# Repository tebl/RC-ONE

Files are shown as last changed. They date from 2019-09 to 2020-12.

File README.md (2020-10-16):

# KIM-1 Replica Computer
Along the years I've built quite a few computers, some bought as kits from various vendors and some I've even designed myself based on designs described in good old books or other technical resources - above all, there's always been one I really wanted above all of them: the KIM-1! 

Originally created by MOS in order to show off their new 6502-processor, it was a success that tapped into a market they probably never knew themselves was growing into a force to be reckoned with - the homecomputing market! Later bought up by little-known typewriter-manufacturer *Commodore*, the KIM-1 is an iconic piece of hardware and since I can't afford to buy one I'll build one instead.

The original unit cost 245$ assembled with everything you needed to get started, it had six segment displays for outputting information and a 24-key keypad onboard. CPU ran at an incredible 1 Mhz, it had a complete monitor in 2K of ROM, 1K of static RAM as well as an additional 128 bytes of RAM. You got 15 additional I/O lines to play with, all on a single PCB.

# RC-ONE
I however don't have that amount of money to play with, PCB prices skyrocket past 100x100 mm so I've separated functionality into separate boards so that each version would cost only around 5$ per piece instead. It means it's no longer a single board computer, but if it means more people can build it as a fun project then that's a plus in my book. The main setup does not include the additional 15 I/O lines due to space requirements, but you can add those back to the system by including the 65K Expansion (in addition to the backplane module) if you want to. If you just want to play around with the system and try your hand at machine language coding, you can get started with the CPU board, UI board and a keypad module.

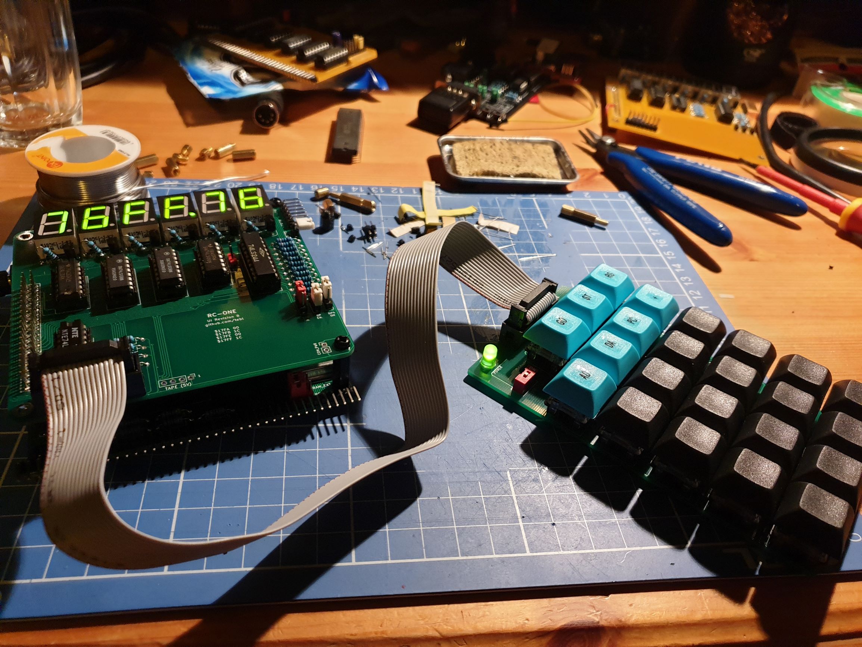
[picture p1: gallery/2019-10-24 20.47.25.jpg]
RC-ONE Standalone


As a classic microcomputer, I've gone ahead and created the obligatory memory map for your perusal - the highlights are shown below, but you'll find the complete set of information in the documentation section ([ODS](https://github.com/tebl/RC-ONE/raw/master/documentation/memory_map.ods)- or [PDF](https://github.com/tebl/RC-ONE/raw/master/documentation/memory_map.pdf)-format). Some of the functions have been shifted physically, but in the end the system should be functionally identical to an original system and able to run code without requireing changes.

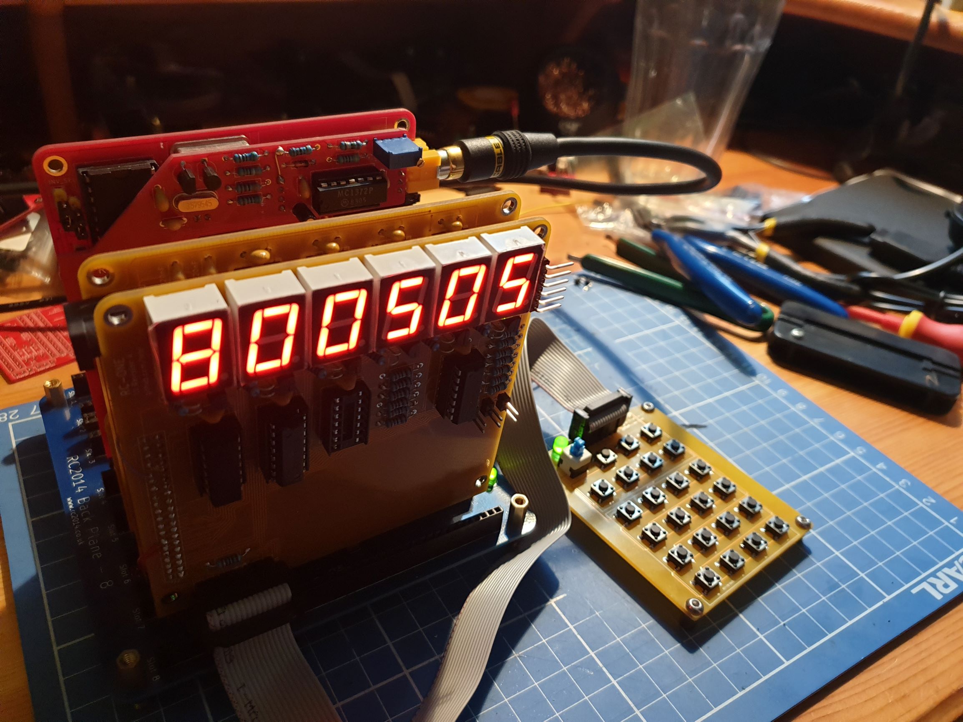
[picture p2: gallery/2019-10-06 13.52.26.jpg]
Expanded system


The system is highly expandable, with the [65K Expansion board](https://github.com/tebl/RC-ONE/tree/master/RC1%2065K%20Expansion) in place you'll get better utilization of the components already on the CPU board as well as the ability to add additional modules to the system with an additional backplane also in place. See *System modules* below for a list of modules required for a complete system, optional modules available as well as modules for other systems that are compatible with the RC-ONE computer.

A lot of the work I've done couldn't have been completed without the work previously done by Ruud Baltissen, you can compare the schematics he did for the original KIM-1 computer and his more modern recreation of it by studying his [Build your own KIM-1](http://www.baltissen.org/newhtm/buildkim.htm) page.

## Project status
The RC-ONE computer is operational, it can be used to enter and run code via the keypad and can output to the displays as expected and for many this will be all that's needed to have fun with it as a replica of the KIM-1. Some sections are still being worked on, mainly those that deal with the TTY mode and tape functionality - see [TODO](https://github.com/tebl/RC-ONE/blob/master/TODO.md) for an overview of things I'd like to see done sometime in the future!

## System modules
As mentioned earlier there are a few different modules available for the system, some will be required to make the system function and others is considered optional and can be added if you want that extra piece of 70s-technology to play around with. There may be additional modules in the project files, but the ones I've added here are the ones that can be considered ready. As modules are being worked on over time, I've also added an order link to the modules so that you can get the last version I know worked. For more information about the specific module, including schematic and a list of parts you'd need to build it - click the name of the module!

Note that due to the similarities with the [RC6502  Apple 1 Replica](https://github.com/tebl/RC6502-Apple-1-Replica), quite a few of the modules developed for that system will also work with the RC-ONE - the ones I've tested and use with the system have also been linked below.

| Module | RC-ONE | RC-ONE 65K | Order |
| --- | --- | --- | ----- |
| [RC-ONE CPU](https://github.com/tebl/RC-ONE/tree/master/RC1%20CPU) | required | required | [PCBWay](https://www.pcbway.com/project/shareproject/RC_ONE_KIM_1_Replica__CPU_module_.html) |
| [RC-ONE User Interface](https://github.com/tebl/RC-ONE/tree/master/RC1%20UI) | required | required | [PCBWay](https://www.pcbway.com/project/shareproject/RC_ONE_KIM_1_Replica__UI_revision_C_.html) |
| [RC-ONE Keypad SX](https://github.com/tebl/RC-ONE/tree/master/RC1%20Keypad) | required * | required * | [PCBWay](https://www.pcbway.com/project/shareproject/RC_ONE_Keypad_SX.html?inviteid=88707) |
| [RC-ONE Keypad MX](https://github.com/tebl/RC-ONE/tree/master/RC1%20Keypad%20MX) | required * | required * | [PCBWay](https://www.pcbway.com/project/shareproject/RC_ONE_Keypad_MX.html) |
| [RC-ONE 65K Expansion](https://github.com/tebl/RC-ONE/tree/master/RC1%2065K%20Expansion) |  | required | [PCBWay](https://www.pcbway.com/project/shareproject/RC_ONE_65K_Expansion.html) |
| [RC-ONE 8K ExRAM](https://github.com/tebl/RC-ONE/tree/master/RC1%208K%20ExRAM) |  | optional | |
| [RC6502 Backplane](https://github.com/tebl/RC6502-Apple-1-Replica/tree/master/RC6502%20Backplane)  |  | required | [PCBWay](https://www.pcbway.com/project/shareproject/RC6502_Apple_1_Replica__Backplane_module_revision_A_.html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) |
| [RC6502 Prototyping module](https://github.com/tebl/RC6502-Apple-1-Replica/tree/master/RC6502%20Prototyping) |  | optional | [PCBWay](https://www.pcbway.com/project/shareproject/RC6502_Apple_1_Replica__Module_prototyping_board_.html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) |
| [6502 Project Platform](https://github.com/tebl/RC-Project-Board) | optional | optional | [PCBWay](https://www.pcbway.com/project/shareproject/6502_Project_Platform__RC6502__RC_ONE__RC6802_.html?inviteid=88707) |
| [6502 Games Board](https://github.com/tebl/RC-Project-Board/tree/master/projects/GB-001%20Game%20Board) | | optional** | [PCBWay](https://www.pcbway.com/project/shareproject/6502_Games_Board.html)
| [6502 Games Platform](https://github.com/tebl/RC-Project-Board/tree/master/platforms/PP%206502%20Game%20Board) | | optional** | [PCBWay](https://www.pcbway.com/project/shareproject/6502_Games_Platform.html)

*) Only one Keypad module is required, the MX version is a lot more comfortable to use though it comes at an increased cost.
**) You need [6502 Games Platform](https://github.com/tebl/RC-Project-Board/tree/master/platforms/PP%206502%20Game%20Board) and 6502 Game Board to build the 6502 Games hardware, originally created by Rodnay Zaks in his book [6502 Games](https://archive.org/details/6502GamesRodnayZaks/mode/2up). To use them with the RC-ONE you also require the [65K Expansion](https://github.com/tebl/RC-ONE/tree/master/RC1%2065K%20Expansion) installed.

If you would like to have a copy of one or more modules (usually 5$ per module), consider using the order links listed above - that way you also support the development of these boards while doing so. Alternatively, you can also zip up the contents of the export directory for each module and give that to your favourite PCB fabrication plant (I use [PCBWay](https://www.pcbway.com/setinvite.aspx?inviteid=88707) instead. Note that since I'm always tinkering with things, this repository may contain changes that I've not yet tested!

## Tell me more!
You'll find a lot of additional technical information belonging to each of the various modules by clicking on them from the table in the previous section, but those are mainly for reference when using or building them. For that reason I've also taken the time to write a somewhat acceptable attempt at a [manual](https://github.com/tebl/RC-ONE/blob/master/Manual.md), it should be able to get you started at both understanding not only how to use the computer, but also give you a more concise idea about what a KIM-1 computer (or replica) actually is.

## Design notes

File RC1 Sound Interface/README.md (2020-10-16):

# RC-ONE Sound Interface (SID)

**This design is untested!**

Made in order to use Commodore 64 SID chip replacements such as the SwinSID, armSID or fpgaSID as a sound device. Purposefully does not include the extra voltages needed to use a real SID-chip, mostly because the functioning chips that are left in this world belong in real computers (also, did not want to mess around with more than one power rail).

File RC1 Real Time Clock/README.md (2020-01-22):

# RC-ONE Real Time Clock (RTC)

**This design is untested!**

Wanted a Real Time Clock, but have been a hard time locating a suitable circuit for it since most of them either contain batteries that ran out a decade ago or are based on I2C or SPI (which I don't feel like bit-banging now or possibly ever). Appearantly there is a chip called DS12885 that is suitable and was readily used on the XT and AT line of computers, so they are cheap and plentiful though have a multi-plexed bus that is probably why it haven't been much used for SBC builds. Did however find an article in [Elektor Electronics from april 1985](https://www.americanradiohistory.com/UK/Elektor/80s/Elektor-1985-04.pdf) that uses it, so I've tried my best to adapt it for use here.

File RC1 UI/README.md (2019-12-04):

# RC-ONE

Among the years I've built quite a few computers, some bought as kits from various vendors and some I even designed myself based on available designs describes in books and other technical resources - above all, there was one I really wanted above all of them; the KIM-1! The [RC-ONE](https://github.com/tebl/RC-ONE) is a functional replica designed in a modular fashion, for the specifics see the specific module.

## User Interface (UI)
The *User Interface (UI)* board has been created to stack on top of the CPU-board, see below for an indication of how that'll look on a completed revision B system - I'm using M3 nylon standoffs to support the boards.

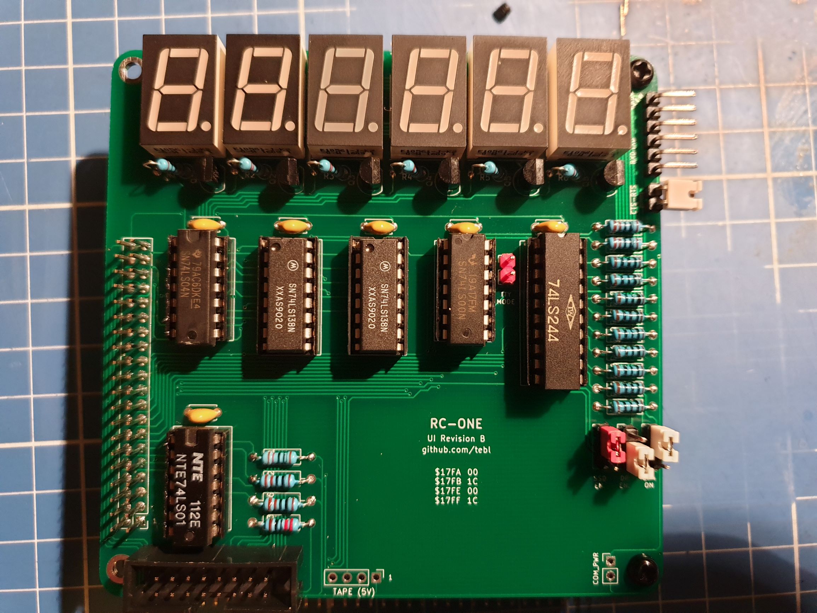
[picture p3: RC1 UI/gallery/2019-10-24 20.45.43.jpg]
Assembled UI Board

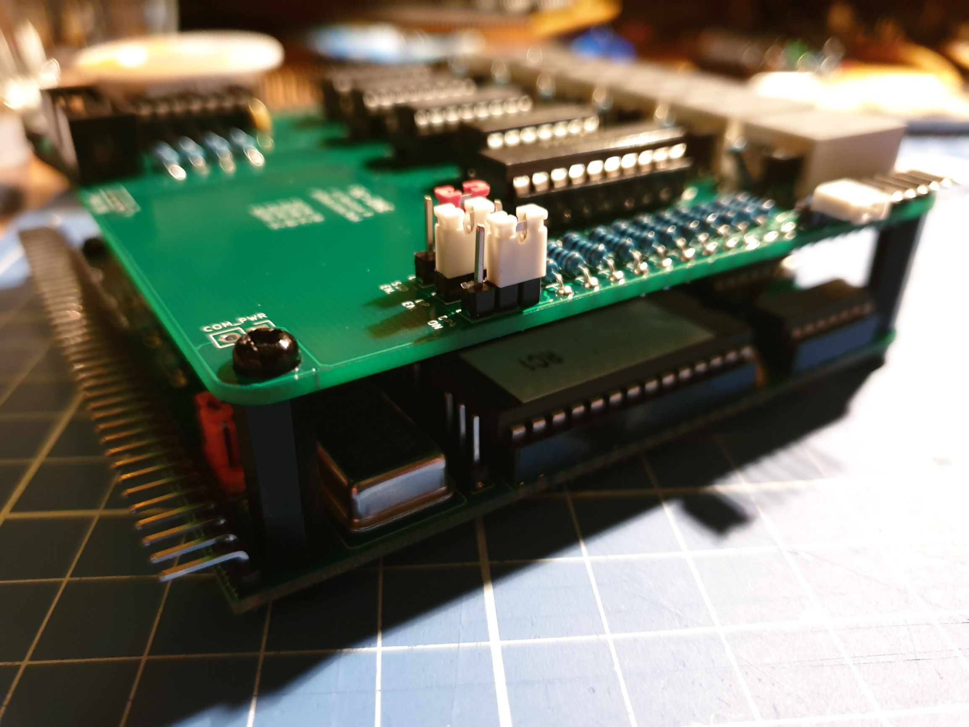
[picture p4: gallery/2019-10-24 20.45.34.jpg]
Stacked boards


The UI board takes care of all the various ways that the user can interact with the computer, it should functionally include all the functions found on the original computer such as 7-segment displays, keypad connector, a simplified tape interface as well as the ability to connect with a serial terminal.

The displays function the same way as the original displays, but the output hardwareas well as the logic dealing with device selection has been changed to replace some of the ICs that I could not reliably obtain - unfortunately at an increased chip-count, but that is the cost of doing increasingly outdated projects. The 6532 compared to the original 6530 IC has an extra I/O line, I've connected that up to the decimal point of the displays though the bahaviour of these is not supported by the original monitor program so I've added jumpers to enable/disable this functionality.

The tape interface was one created by Daniel Metzger and was featured in the book *22 micro-computer projects - to build, learn and learn*, I don't have an original KIM-1 so I can't compare the two though it is the only one I've seen that only use 5v (3.5mm jack has both audio in and out, I designed it for use with a ZX Spectrum +3 tape cables that people are still selling). 

The serial interface is now TTL level and is intended for use with USB TTL serial adapters, *USE_COM* must be jumpered when resetting the computer so that the computer knows to attempt communication over serial instead of using the displays/keypad. After starting up, the computer will await the receipt of the *ENTER* key in order to determine the baud rate that should be used when communicating with the terminal (-program).

## Jumpers
| Reference | Position | Description |
| ---| --- | ---  |
| DP_EN | 1-2 | Decimal point (DP) on displays connected to 6532 PB6 line |
| | 2-3 * | DP on displays disabled as original |
| DP4_EN | 1-2 * | DP on display 4 always on |
| | 2-3 | DP on display 4 connected to 6532 PB6 line |
| SSD_EN | 1-2 * | Enable Seven Segment Displays (SSD) |
| | 2-3 | Disable Seven Segment Displays (SSD) |
| TTY_MODE  | o-o | Jumper to enable TTY-mode, disabled keypad/displays |
| CTS - RTS | o-o * | Shorts serial CTS to RTS to disable flow control |
| COM_PWR | o-o | Jumpering allows the computer to be powered over the serial connection *INSTEAD* of connecting power to the CPU board |

\*) Marks the default jumpered positions for a standalone RC-ONE system.

# Schematic
The supplied KiCad files should be sufficient as both a schematic and as a starting point for ordering PCBs (basically you could just zip the contents of the export folder and upload that on a fabrication site), the schematic is also available in [PDF-format](https://github.com/tebl/RC-ONE/raw/master/RC1%20UI/export/RC1%20UI.pdf) so that you print it out and hang it on your office wall, excellent conversation starter at any technology-oriented business worth working at (or so I keep telling myself)!

If you require more assistance, there is also a separate [Troubleshooting](https://github.com/tebl/RC-ONE/blob/master/Troubleshooting.md) guide as part of the supplied documentation. Also make sure to have a read through the [Manual](https://github.com/tebl/RC-ONE/blob/master/Manual.md) to see if it's a *feature* instead!

# BOM
This is the part list as it stands now, most should be easy to get a hold of from your local electronic component shop though you might have to consider other sources depending on the quality of your local vendor. Values in parenthesis are optional components that might not be needed depending on what you want, here it's mostly the tape interface.

Some vendors will have the same ICs in different form factors, the ones you want will often be specified as being in the form of a DIP/PDIP package. For the pin headers, you probably won't find the exact pin count so just buy the 40 pin versions and snip off the parts you don't need.

| Reference | Item | Count |
| --- | --- | ----- |
| PCB | Fabricate yourself using Gerber files | 1 |
| AFF1-AFF6 | 0.56" 7-segment displays (C.K.) | 6 |
| C7,C9 | 50nF ceramic capacitor | (2)|
| C8 | 68nF ceramic capacitor | (1)|
| C1-C6 | 100nF ceramic capacitor | 6 |
| C11 | 100nF ceramic capacitor | (1)|
| D4 | 5mm LED | (1)|
| D1-D3 | 1N4148 small signal diode | 3 |
| D5-D7 | 1N4148 small signal diode | (3)|
| J1 | 2x8 straight pin header | 1 |
| J2 | 2x20 straight pin header | 1 |
| J3 | 1x6 right-angle pin header | 1 |
| J4 Audio | 3.5mm 5pin green audio socket (PJ307) | (1)|
| JP1,JP3 | 1x2 straight pin header | 2 |
| JP4-JP6 | 1x3 straight pin header | 3 |
| JP2 | 1x2 right-angle pin header | 1 |
| Q1-Q6 | 2N3904 TO-92 transistor | 6 |
| Q7-Q9 | 2N3904 TO-92 transistor | (3)|
| R7,R8,R14-R20 | 100 ohm resistor | 9 |
| R10 | 100 ohm resistor | (1)|
| R13 | 220 ohm resistor | 1 |
| R22,R23,R25,R26 | 1k ohm resistor | 3 |
| R29-R31 | 1k ohm resistor | (3)|
| R11,R33 | 1k5 (1500) ohm resistor | (2)|
| R36 | 2k2 (2200) ohm resistor | (1)|
| R27 | 2k7 (2700) ohm resistor | (1)|
| R32 | 6k8 (6800) ohm resistor | (1)|
| R1-R6,R21 | 10k ohm resistor | 7 |
| R9,R28,R34 | 10k ohm resistor | (3)|
| R35 | 51k ohm resistor | (1)|
| U1,U2 | 74LS138 (DIP-16) | 2 |
| U3 | 74LS01 (DIP-14) ** | (1)|
| U4 | 74LS00 (DIP-14) | 1 |
| U5 | 74LS04 (DIP-14) | 1 |
| U6 | 74LS244 (DIP-20) | 1 |
| | Jumpers for settings (CAP headers) | 4 |

*) These values depend on the color of the seven segment displays you bought, 100 was a bit dim on the green displays though red ones should be good. Personally I'd bump it up a notch on the blue displays. Test on a breadboard first if the brightness is important to you, if in doubt use 100 ohm.

**) The 74LS01 is not stocked everywhere, but it seems the NTE74LS01 is still being produced. The computer will mostly function without it, but you won't be able to single-step code or use the serial interface so it's wort getting one!

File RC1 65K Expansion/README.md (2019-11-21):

# RC-ONE

Among the years I've built quite a few computers, some bought as kits from various vendors and some I even designed myself based on available designs describes in books and other technical resources - above all, there was one I really wanted above all of them; the KIM-1! The [RC-ONE](https://github.com/tebl/RC-ONE) is a functional replica designed in a modular fashion, for the specifics seaddresse specific module.

## 65K Expansion
The original KIM-1 computer as well as RC-ONE base system only has around 1K of RAM available as well as 2K of ROM, it also limits the entire address space available to the 6502 CPU to 8K where most of it has already been taken up. The RC-ONE by comparison uses the same address decoding scheme, but actually has 32K of RAM and 8K of ROM on the base system, most of it simply isn't accessible by the base system. The addition of the 65K Expansion allows the computer to access up to 29K of RAM , the full 8K of ROM as well as increases the total address space to the 64K limit set by the 6502 processor.

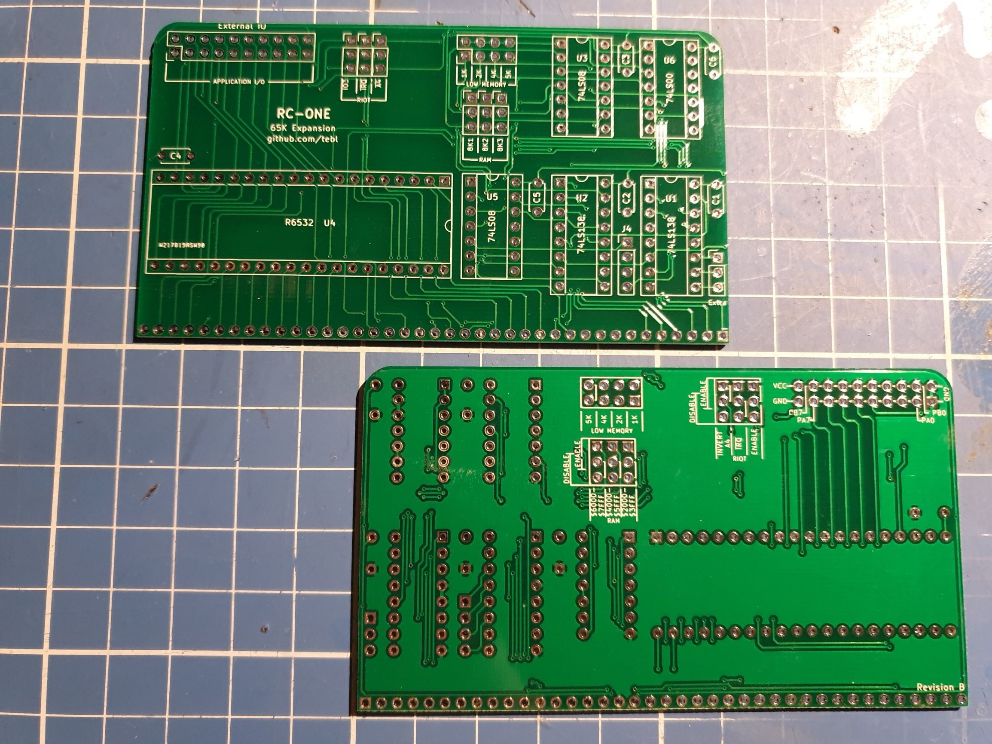
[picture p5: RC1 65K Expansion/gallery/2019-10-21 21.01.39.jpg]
65K Expansion


For a complete overview of the addressing used with the computer, see [Memory Map](https://github.com/tebl/RC-ONE/raw/master/documentation/memory_map.pdf) ([ODS-format](https://github.com/tebl/RC-ONE/raw/master/documentation/memory_map.ods)) for a comparison between the relevant systems - preview of the main bits below as well!

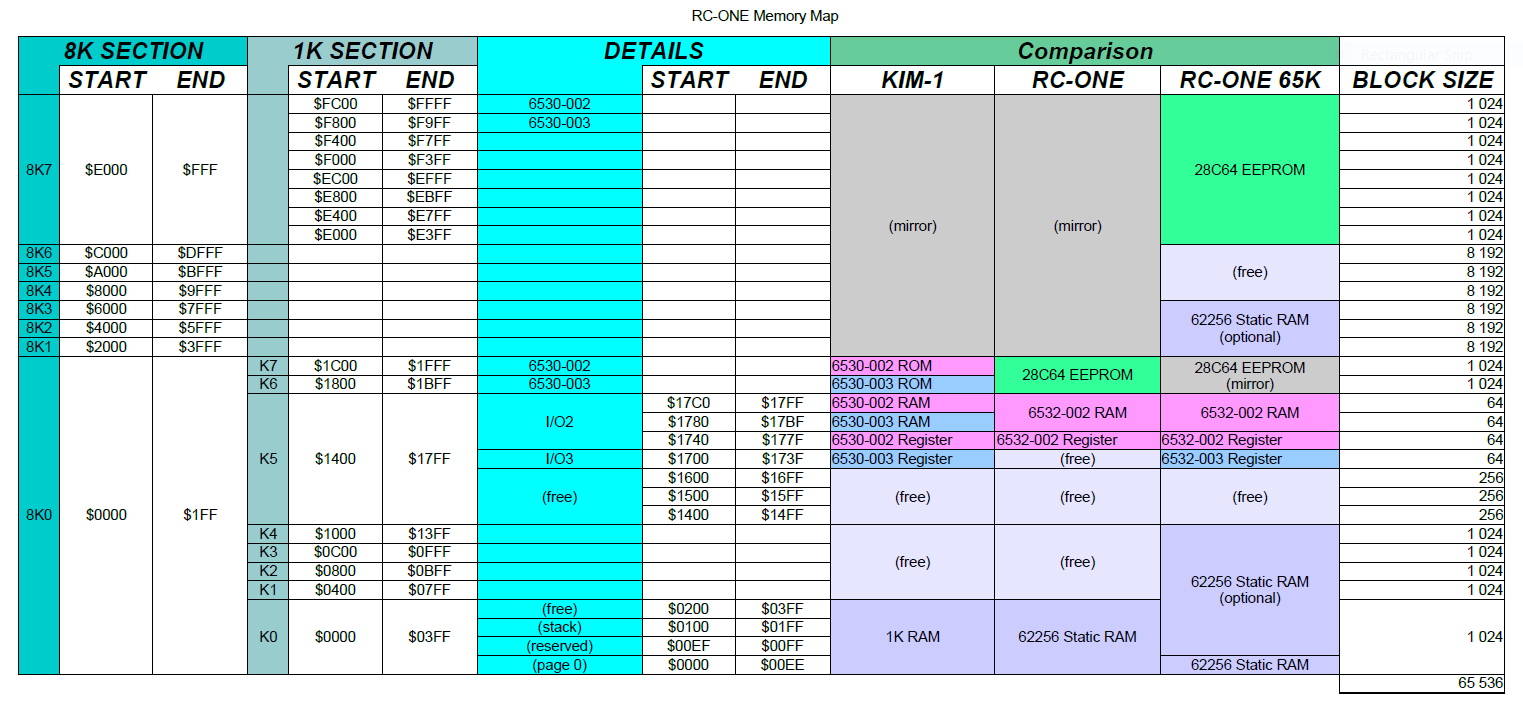
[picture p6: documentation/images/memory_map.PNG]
Memory Map


The 65K Expansion expands upon the address decoding performed by the [CPU-board](https://github.com/tebl/RC-ONE/tree/master/RC1%20CPU) so that more of the address space is both freed up, my implementation on it is for the most part functionally the same as the one described in the [KIM-1 Programming Manual](http://users.telenet.be/kim1-6502/6502/proman.html) (which is why it's called the *65K Expansion*).

Given that since the 65K Expansion changes the address decoding, the *DEN* jumper on the CPU module needs to be removed in order for the computer to function with the 65K Expansion taking over the heavy lifting on the address decoding. Likewise, the *RAM_EXT* and *ROM_EXT* configuration must be changed so that pins 2-3 on them are jumpered in order for the additional RAM and ROM to be accessible.

The original KIM-1 computer came with two 6530s, one dedicated to the user interface and the other available to do with as you please. The RC-ONE base system only has the one 6532 replacing the former, the latter has been added to the 65K Expansion so that you don't have to go without it if you don't actually want to! Quite a lot of the books written for the KIM-1 depend on the additional I/O lines in order to control fun little hardware experiments and I think it's worth getting the extra 6532 for this purpuse.

## Configuration
| Reference  | Position | Description |
| --- | --- | --- |
| DEN *  | o o ** | **Remove** jumper when using 65K Expansion |
| RAM_EXT *  | 1-2 | Jumper when **NOT** using with 65K Expansion |
| | 2-3 ** | RAM decoding performed by 65K Expansion |
| ROM_EXT *  | 1-2 | Jumper when **NOT** using with 65K Expansion |
| | 2-3 ** | ROM decoding performed by 65K Expansion |
| LOW MEMORY | 1-2 | 1K low memory size ($0000 - $03FF) |
| | 3-4 | 2K low memory size ($0000 - $07FF) |
| | 5-6 | 4K low memory size ($0000 - $0FFF) |
| | 7-8 ** | 5K low memory size ($0000 - $13FF) |
| RAM_8K1 | o o | Enable 8K RAM size ($2000 - $3FFF) |
| RAM_8K2 | o o | Enable 8K RAM ($4000 - $5FFF) |
| RAM_8K3 | o o | Enable 8K RAM ($6000 - $7FFF) |
| RIOT_IO3 | 1-2 ** | Enable RIOT chip |
| | 2-3 | RIOT chip disabled |
| RIOT_IRQ | 1-2 | RIOT chip IRQ line connected to BUS |
| | 2-3 ** | RIOT chip IRQ line not connected |
| RIOT_A4 | 1-2 ** | Invert A4 to match 6532 registers to 6530 |
| | 2-3 | 6532 registers according to 6532 datasheet |

*) These jumpers are found on the CPU board
**) Marks the default jumpered positions for a RC-ONE system, but mostly these are suggestions meant to get you started with a computer functionally equivalent to a 65K expanded KIM-1 with a 4K RAM expansion installed.

## Connectors
The following additional headers break out additional signals. *EXTRA* and *K1-K4* allows a convenient hookup point for decoded memory segments for use in other projects as they don't conflict with any other expansions present on the same backplane (pin 1 is on the top). Application I/O is numbered odd-even, see reverse side of PCB or this [image](https://github.com/tebl/RC-ONE/raw/master/RC1%2065K%20Expansion/gallery/application_io.png) for reference.

| Reference | Pins | Description |
| --- | --- | --- |
| Application I/O | 1 (bottom left) | GND |
| | 2 (top left) | GND |
| | 3 | PB7 |
| | 4 | PA7 |
| | 5 | PB6 |
| | 6 | PA6 |
| | 7 | PB5 |
| | 8 | PA5 |
| | 9 | PB4 |
| | 10 | PA4 |
| | 11 | PB3 |
| | 12 | PA3 |
| | 13 | PB2 |
| | 14 | PA2 |
| | 15 | PB1 |
| | 16 | PA1 |
| | 17 | PB0 |
| | 18 | PA0 |
| | 19 (bottom right) | GND |
| | 20 (top right) | VCC |
| EXTRA | 1 (top) | 8K4 ($8000 - $9FFF) |
| | 2 | 8K5 ($A000 - $BFFF) |
| | 3 | 8K6 ($C000 - $DFFF) |
| K1-K4 | 1 (top) | 8K0 K1 ($0400 - $07FF) |
| | 2 | 8K0 K2 ($0800 - $0BFF) |
| | 3 | 8K0 K3 ($0C00 - $0FFF) |
| | 4 | 8K0 K4 ($1000 - $13FF) |

# Schematic
The supplied KiCad files should be sufficient as both a schematic and as a starting point for ordering PCBs (basically you could just zip the contents of the export folder and upload that on a fabrication site), the schematic is also available in [PDF-format](https://github.com/tebl/RC-ONE/raw/master/RC1%20Keypad%20MX/export/RC1%20Keypad%20MX.pdf) so that you print it out and hang it on your office wall, excellent conversation starter at any technology-oriented business worth working at (or so I keep telling myself)!

# BOM
This is the part list as it stands now, most should be easy to get a hold of from your local electronic component shop though you might have to consider other sources depending on the quality of your local vendor.

| Reference | Item | Count |
| --- | --- | ----- |
| PCB | Fabricate yourself using Gerber files | 1 |
| D1 | 5mm LED | 1 |
| J1 | 2x8 straight pin header | 1 |
| SW1-SW22,SW23,SW24 | 3 or 5 pin Cherry MX key switches * | 23 |
| SST | 1-position DIP switch | 1 |
| Keycaps | Blank 1U keycaps ** | 23 |
| Keypad cable | 2x8 pin JTAG cable | 1 |

*) Any type of Cherry MX compatible switches can be used, these can be either of the 3 or pin variety. Personally I bought the green Gateron MX switches and they work great though you'd probably want to buy the non-green version if you don't like the clicky sound.

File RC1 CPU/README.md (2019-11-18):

# RC-ONE

Among the years I've built quite a few computers, some bought as kits from various vendors and some I even designed myself based on available designs describes in books and other technical resources - above all, there was one I really wanted above all of them; the KIM-1! The [RC-ONE](https://github.com/tebl/RC-ONE) is a functional replica designed in a modular fashion, for the specifics see the specific module.

## CPU
The CPU board has been created to stack with the UI-board, see below for an indication of how that'll look on a completed revision B system - I'm using M3 nylon standoffs to support the boards.

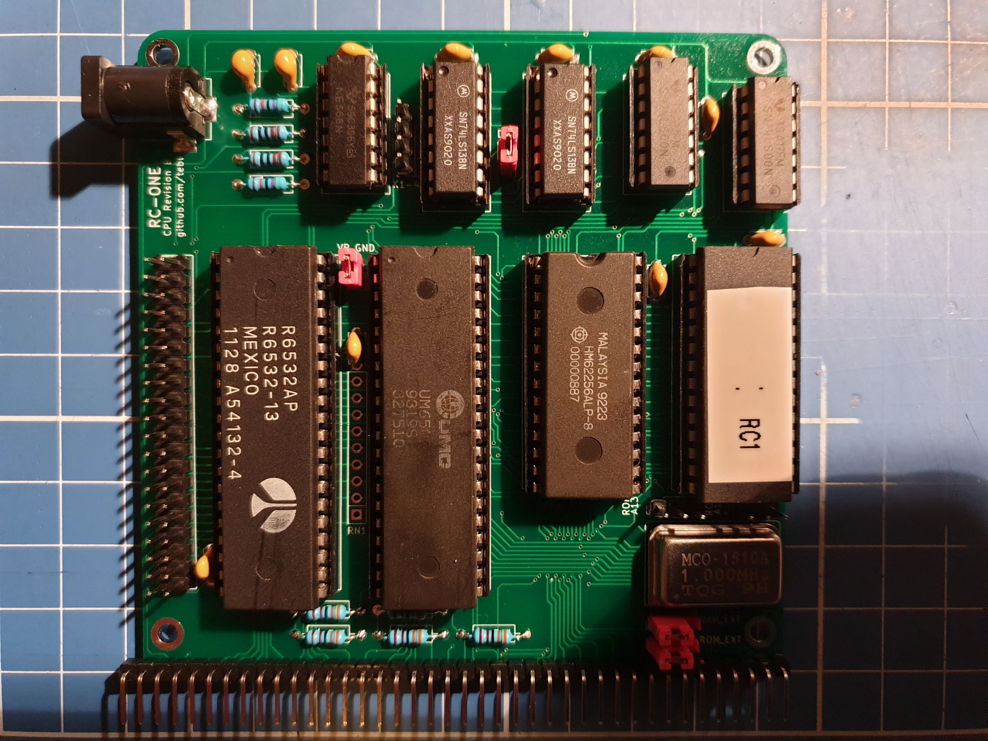
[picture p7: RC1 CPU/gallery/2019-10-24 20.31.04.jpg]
Assembled CPU Board

Stacked boards

The CPU board is actually a complete SBC (Single Board Computer) by itself, meaning that it can be used standalone - the only thing missing is an automatic reset, which the KIM-1 originally also lacked. The design follows the original KIM-1 schematics and has the exact same specifications as the original system (1Mhz, 1K RAM and 2K ROM), you can compare the [memory map](https://github.com/tebl/RC-ONE/raw/master/documentation/memory_map.pdf) for the specifics.

Some of the ICs however have been changed out with components that should be easier to source for a lot less money, the result of this is that the system actually instead has 32K of RAM and 8K ROM on the board though only 1K of RAM 2K of ROM will be accessible by the CPU board without additional hardware. The [65K Expansion](https://github.com/tebl/RC-ONE/tree/master/RC1%2065K%20Expansion) allows you to utilize most of the the memory (29K maximum) and the full 8K of ROM.

The *DEN* jumper must jumpered when **NOT** using together with a [65K Expansion board](https://github.com/tebl/RC-ONE/tree/master/RC1%2065K%20Expansion), *RAM_EXT* and *ROM_EXT* likewise must be jumpered across pins 1-2 when not using the expansion (these transfer the address decoding to the 65K-card, without it there is no decoding done and the computer will not work).

## Jumpers
| Reference | Position | Description |
| --- | --- | ---  |
| DEN | o-o * | Jumper when NOT using with 65K Expansion |
| RAM_EXT | 1-2 * | Jumper when NOT using with 65K Expansion |
| | 2-3 | RAM decoding handled by 65K Expansion |
| ROM_EXT | 1-2 * | Jumper when NOT using with 65K Expansion |
| | 2-3 | ROM decoding handled by 65K Expansion |
| VP_GND | o-o * | Jumpered when UM6502, R6502 and SY6502 processors |

\*) Marks the default jumpered positions for a standalone RC-ONE system with a common 6502 processor (ie. not 65c02).

# Schematic
The supplied KiCad files should be sufficient as both a schematic and as a starting point for ordering PCBs (basically you could just zip the contents of the export folder and upload that on a fabrication site), the schematic is also available in [PDF-format](https://github.com/tebl/RC-ONE/raw/master/RC1%20CPU/export/RC1%20CPU.pdf) so that you print it out and hang it on your office wall, excellent conversation starter at any technology-oriented business worth working at (or so I keep telling myself)!

If you require more assistance, there is also a separate [Troubleshooting](https://github.com/tebl/RC-ONE/blob/master/Troubleshooting.md) guide as part of the supplied documentation. Also make sure to have a read through the [Manual](https://github.com/tebl/RC-ONE/blob/master/Manual.md) to see if it's a *feature* instead!

# BOM
This is the part list as it stands now, most should be easy to get a hold of from your local electronic component shop though you might have to consider other sources depending on the quality of your local vendor. Values in parenthesis are optional components that might not be needed.

Some vendors will have the same ICs in different form factors, the ones you want will often be specified as being in the form of a DIP/PDIP package. Usually you'll want sockets for each of the ICs as well, a bag of assorted sockets should be easily available without setting you back more than a couple bucks. With the sockets in place, you don't need to dread having to remove an IC later, this leads to easier fault finding and you can easily "borrow" them for other projects later! For the pin headers, you probably won't find the exact pin count so just buy the 40 pin versions and snip off the parts you don't need.

| Reference | Item | Count |
| --- | --- | ----- |
| PCB | Fabricate yourself using Gerber files | 1 |
| C1-C9 | 100nF ceramic capacitor | 9 |
| C10-C11 | 220nF ceramic capacitor | 2 |
| J1 | 39p right angle pin header | 1 |
| J2 | 2x20 pin straight header | 1 |
| J3 | 2.1mm x 5.5mm barrel plug | 1 |
| JP1,JP2 | Single row, 2 pin straight header | 2 |
| JP3,JP4 | Single row, 3 pin straight  header | 2 |
| R1-R3,R6-R7  | 3k3 (3300) ohm resistor | 5 |
| R9-R10 | 1k ohm resistor | 2 |
| R11-R12 | 47k ohm resistor | 2 |
| RN1 | 4k7 ohm bussed resistor array (SIP-9) | (1)|
| U1 | 6502 CPU (DIP-40) | 1 |
| U2 | 62256 Static RAM (DIP-28) | 1 |
| U3 | 28C64/28C256 EEPROM (DIP-28) | 1 |
| U4 | 6532 RIOT (DIP-40) | 1 |
| U5,U9 | 74LS00 (DIP-14) | 2 |
| U6 | LM556 (DIP-14) | 1 |
| U7,U8 | 74LS138 (DIP-16) | 2 |
| X1 | 1.000Mhz TTL Oscillator, (DIP 14) | 1 |
| | Jumpers for settings (CAP headers) | 3 |

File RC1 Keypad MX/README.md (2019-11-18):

# RC-ONE

Among the years I've built quite a few computers, some bought as kits from various vendors and some I even designed myself based on available designs describes in books and other technical resources - above all, there was one I really wanted above all of them; the KIM-1! The [RC-ONE](https://github.com/tebl/RC-ONE) is a functional replica designed in a modular fashion, for the specifics see the specific module.

## Keypad MX
The RC-ONE has a keypad with the same key layout as the one found on the original KIM-1 computer, it has been designed so that it can be connected to the computer using a cheap 2x8 pin JTAG cable.

RC-ONE with Keypad MX
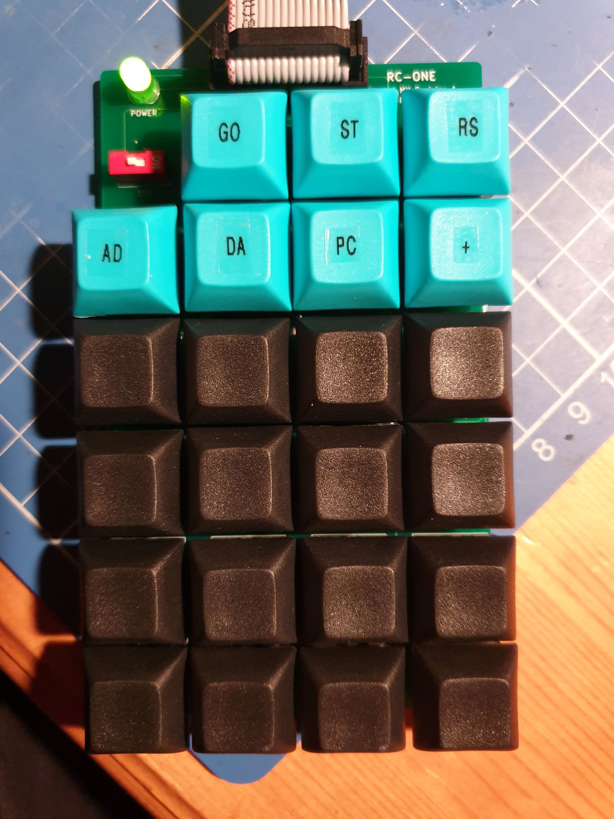
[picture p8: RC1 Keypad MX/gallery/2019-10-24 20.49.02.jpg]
Keypad MX


This is the MX version of the keypad, it uses Cherry MX key switches as well as suitable keycaps for that ultimate RC-ONE experience. I built mine using cheaper Gateron clone switches, they're really comfortable for the price and when using the green ones you also get that traditional clicky sound. I was out of white on clear tape for my label printer so 0-F was blank when I took the picture, but overall it's a good look! Add some bumpon rubber feet to the bottom to save the desk from the sharp solder points on the underside.

The Keypad MX might be part of the ultimate RC-ONE experience, but it is a rather expensive build due to the PCB size and components used - the standard [Keypad](https://github.com/tebl/RC-ONE/tree/master/RC1%20Keypad) uses ordinary tactile switches and is a lot cheaper to build. On the other hand, both of these can be connected to your main computer as a USB keyboard by adding the [Keypad USB Adapter](https://github.com/tebl/RC-ONE/tree/master/RC1%20Keypad%20to%20USB) along with an Arduino Pro Micro.

# Schematic
The supplied KiCad files should be sufficient as both a schematic and as a starting point for ordering PCBs (basically you could just zip the contents of the export folder and upload that on a fabrication site), the schematic is also available in [PDF-format](https://github.com/tebl/RC-ONE/raw/master/RC1%20Keypad%20MX/export/RC1%20Keypad%20MX.pdf) so that you print it out and hang it on your office wall, excellent conversation starter at any technology-oriented business worth working at (or so I keep telling myself)!

# BOM
This is the part list as it stands now, most should be easy to get a hold of from your local electronic component shop though you might have to consider other sources depending on the quality of your local vendor.

| Reference | Item | Count |
| --- | --- | ----- |
| PCB | Fabricate yourself using Gerber files | 1 |
| D1 | 5mm LED | 1 |
| J1 | 2x8 straight pin header | 1 |
| SW1-SW22,SW23,SW24 | 3 or 5 pin Cherry MX key switches * | 23 |
| SST | 1-position DIP switch | 1 |
| Keycaps | Blank 1U keycaps ** | 23 |
| Keypad cable | 2x8 pin JTAG cable | 1 |

*) Any type of Cherry MX compatible switches can be used, these can be either of the 3 or pin variety. Personally I bought the green Gateron MX switches and they work great though you'd probably want to buy the non-green version if you don't like the clicky sound.

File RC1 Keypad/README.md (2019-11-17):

# RC-ONE

Among the years I've built quite a few computers, some bought as kits from various vendors and some I even designed myself based on available designs describes in books and other technical resources - above all, there was one I really wanted above all of them; the KIM-1! The [RC-ONE](https://github.com/tebl/RC-ONE) is a functional replica designed in a modular fashion, for the specifics see the specific module.

## Keypad
The RC-ONE has a keypad with the same key layout as the one found on the original KIM-1 computer, it has been designed so that it can be connected to the computer using a cheap 2x8 pin JTAG cable.

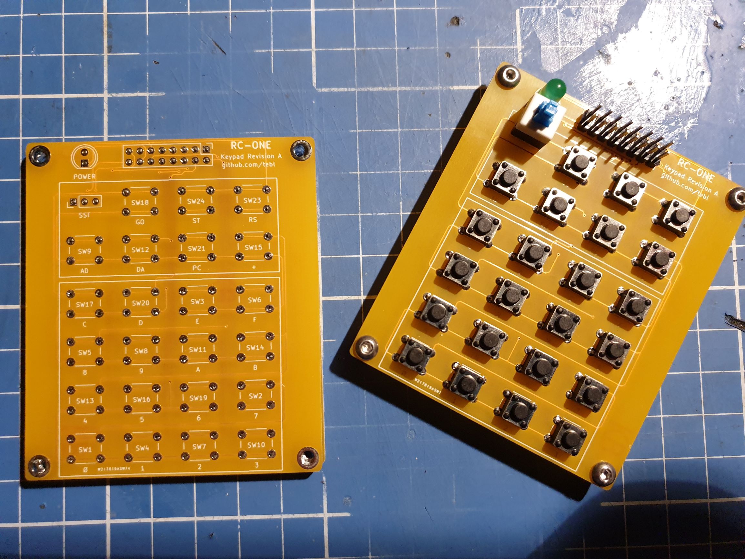
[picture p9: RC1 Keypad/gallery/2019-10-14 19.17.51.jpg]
Keypad PCB and assembled unit


To avoid punching a lot of tiny holes into the desk underneath the keypad, I recommend getting some M3 nylon standoffs to create some space under the solder points. Using a proper 2x8 pin IDC connector also ensures you don't plug the cable in the wrong way. The SST switch can be pin headers and a jumper to be moved around or a 3-position slide switch.

While the keypad is perfectly sufficient for getting started with the RC-ONE, it's not the most ergonomic piece of keyboard I've ever used and entering longer programs may prove a somewhat painful process. For that reason, and I really wanted to build one, the [Keypad MX](https://github.com/tebl/RC-ONE/tree/master/RC1%20Keypad%20MX) version was also designed - it uses Cherry MX (or cheaper clones) key switches for that ultimate RC-ONE build! The keypad itself can also be used as an ordinary USB keyboard by adding the [Keypad USB Adapter](https://github.com/tebl/RC-ONE/tree/master/RC1%20Keypad%20to%20USB) along with an Arduino Pro Micro.

# Schematic
The supplied KiCad files should be sufficient as both a schematic and as a starting point for ordering PCBs (basically you could just zip the contents of the export folder and upload that on a fabrication site), the schematic is also available in [PDF-format](https://github.com/tebl/RC-ONE/raw/master/RC1%20Keypad/export/RC1%20Keypad.pdf) so that you print it out and hang it on your office wall, excellent conversation starter at any technology-oriented business worth working at (or so I keep telling myself)!

# BOM
This is the part list as it stands now, most should be easy to get a hold of from your local electronic component shop though you might have to consider other sources depending on the quality of your local vendor.

| Reference | Item | Count |
| --- | --- | ----- |
| PCB | Fabricate yourself using Gerber files | 1 |
| D1 | 5mm LED | 1 |
| J1 | 2x8 straight pin header | 1 |
| SW | Momentary push button | 23 |
| SST | 3-position slide switch * | 1 |
| Keypad cable | 2x8 pin JTAG cable | 1 |

*) You can install one of those handy 3-position slide switches, these are sold from China and have a 2.54mm pin spacing - if you use them, I recommend testing it with a continuity meter after soldering it in to make sure that it functions properly and does not permanently bridge the connections (had some problems with them). Alternatively, you can use anything that is able to short the two right-most pins as long as it fits or can be made to fit.

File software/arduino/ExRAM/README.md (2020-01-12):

# ExRAM
Originally based on the Arduino EEPROM programmer as featured in a [video](https://www.youtube.com/watch?v=K88pgWhEb1M) by the master of breadboards, Ben Eater. I started this project with his code at the heart of it all, then coerced it into becoming a way of loading data onto a 62256 static RAM chip before adding a bunch of features to the whole overall package.

The Arduino has a fully functioning command-line interface added to it so that you can send it commands using most fully-featured terminal programs, the one I use for this project is Tera Term for Windows. The configuration I use is included in the project files, but you will most certainly have to change the COM-port used to make it work - there's nothing special added to it other than line-delays in order to make data transfers more reliable. The reason for the delays is that the Arduino Nano doesn't include any form of hardware-based flow control so while it still runs at a whopping 16Mhz, it doesn't even come close to being able to compete with modern laptop so it gets easily overflowed with data).

The interface currently supports loading data in the form of both Intel HEX-files as well as the more ancient Paper-tape formats. For a complete listing of the supported commands, type **help** and press ENTER for a listing of the currently supported commands. If you find that the output contains a bunch of wierd characters like the title being shown as "[1;37mExRAM 0.2", then that's probably just that the terminal software doesn't support the [terminal codes](https://wiki.bash-hackers.org/scripting/terminalcodes) that I added to it (unfortunately, the Arduino serial terminal is one of them) - you can either just disable them by giving the command *ansi off* or recompile the sketch with the feature disabled.

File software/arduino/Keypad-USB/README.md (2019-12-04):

# Keypad to USB adapter

While not actually a part of the RC-ONE computer, I wanted to a way to use the keypad on a modern computer - this is implemented by using an Arduino Pro Micro, a version of the board with USB host functionality.

This project folder contains an Arduino sketch with the necessary code to do so, code was originally based on routines by Dave Curran and his [ZX81 USB Keyboard](http://blog.tynemouthsoftware.co.uk/2012/02/zx81-usb-keyboard-source.html) though changes were made and bugs were probably introduced.

## Arduino-module
For assistance on getting going with the Pro Micro on common tasks such as uploading code and communicating with the module, I found the drivers guides on [learn.sparkfun.com](https://learn.sparkfun.com/tutorials/pro-micro--fio-v3-hookup-guide#hardware-overview-pro-micro) to be of great help (the board I purchased and used for the project was a DIY MORE Arduino Pro Micro). The following is what I have selected as board type, make sure that you pick the one that corresponds to your module as Pro Micro will have to be reset using the module if you have problems.

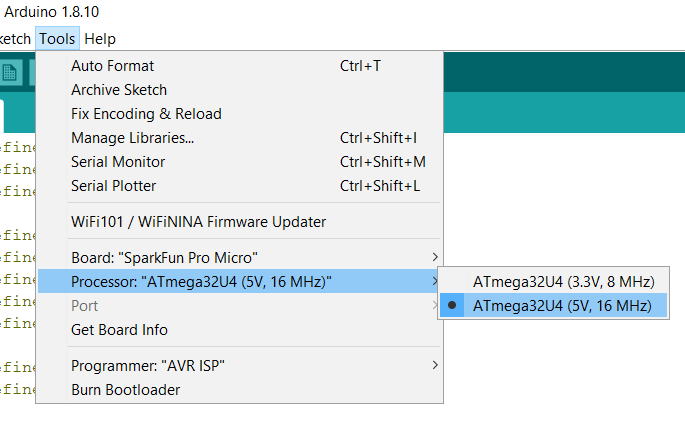
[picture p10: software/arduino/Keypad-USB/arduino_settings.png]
Arduino board configuration


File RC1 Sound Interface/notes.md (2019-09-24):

$xx00 Voice 1 freq. LB
$xx01 Voice 1 freq. HB
$xx02 Voice 1 Pulse wave LB
$xx03 Voice 1 Pulse wave HB
$xx04 Voice 1 Control
$xx05 Voice 1 attack/decay
$xx06 Voice 1 sustain/release

$xx07 Voice 2 freq. LB
$xx08 Voice 2 freq. HB
$xx09 Voice 2 Pulse wave LB
$xx0a Voice 2 Pulse wave HB
$xx0b Voice 2 Control
$xx0c Voice 2 attack/decay
$xx0d Voice 2 sustain/release

$xx0e Voice 3 freq. LB
$xx0f Voice 3 freq. HB
$xx10 Voice 3 Pulse wave LB
$xx11 Voice 3 Pulse wave HB
$xx12 Voice 3 Control
$xx13 Voice 3 attack/decay
$xx14 Voice 3 sustain/release

$xx15 Filter cutoff freq. LB
$xx16 Filter cutoff freq. HB

$xx17 Filter resonance/routing
$xx18 Filter mode/volume

$xx19 Analog X
$xx1A Analog Y
$xx1B Voice 3 oscillator
$xx1C Voice 3 envelope

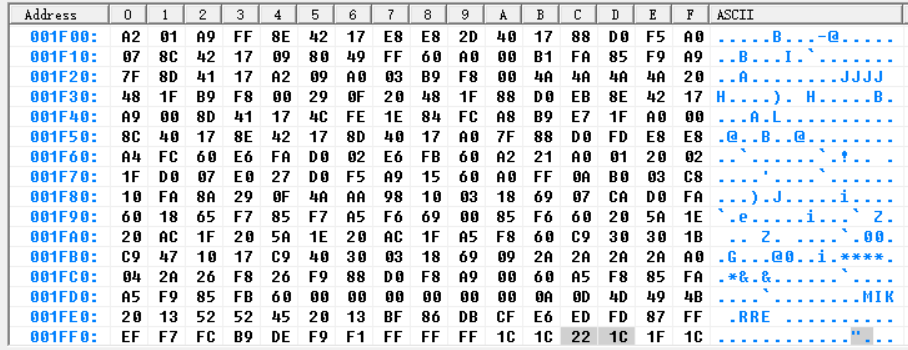
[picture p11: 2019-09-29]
documentation/images/reset_vector #1.png

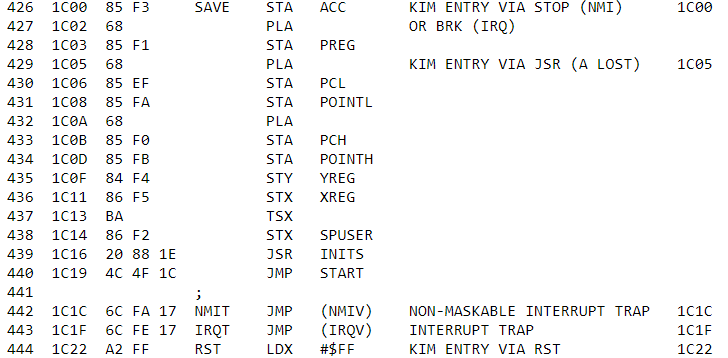
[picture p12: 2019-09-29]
documentation/images/reset_vector #2.png

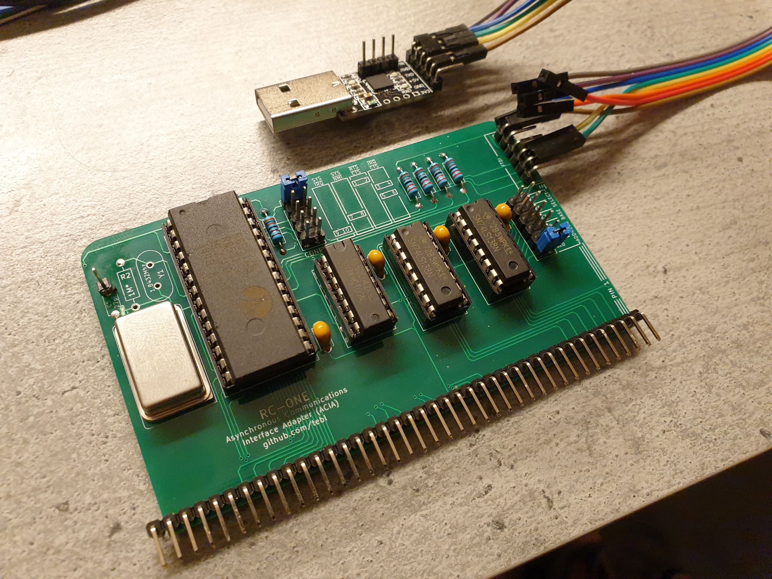
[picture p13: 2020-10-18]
RC1 ACIA/gallery/2020-10-18 02.45.57.jpg

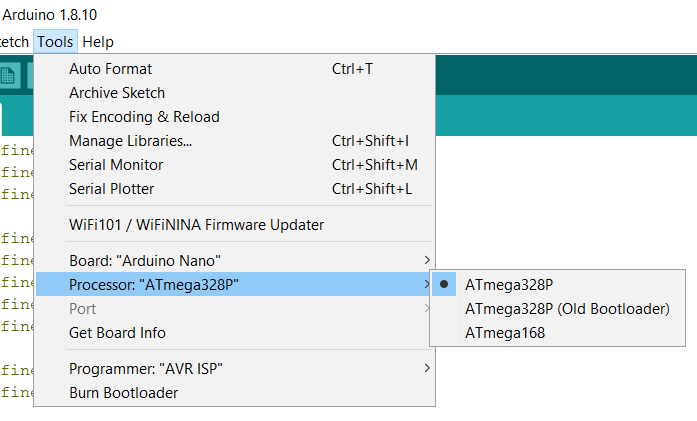
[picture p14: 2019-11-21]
software/arduino/ExRAM/arduino_settings.png

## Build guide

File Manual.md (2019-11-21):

# RC-ONE Manual
There are manuals and this one is mine, all mine and has all the best words with the exception of the parts actually written by other people. A lot of the best words might also never find a way into this manual, mostly because I never found a natural way of mentioning the Aardvark in a document describing the inner workings of the computer that might one day be known as the *RC-ONE*.

RC-ONE Standalone

# 1> Introduction
What an *RC-ONE* actually is? Well, that is what this project is all about. Mostly it is functional replica of the original MOS KIM-1, but please keep in mind the *mostly*-part as I'll surely loose my way before long and start implementing features or make changes that weren't supposed to be there in the first place.

If you want the original authenticity and the same identical parts as back in the day, then I recommend one of the primary sources of information used when building the RC-ONE; the [Build your own KIM-1](http://www.baltissen.org/newhtm/buildkim.htm) pages by Ruud Baltissen as well as the pages of [Hans Otten](http://retro.hansotten.nl/6502-sbc/kim-1-manuals-and-software/). Rest asure, however, that the RC-ONE will ultimately be a KIM-1 in spirit (thrown together, cheaply made and open to all manner of hacks)!

Somewhat telling for probably all of the projects I've fiddled with, I've mostly tended towards recreating the type of equipment I could not possibly manage to finance such as the [*RC6502 Apple 1 replica*](https://github.com/tebl/RC6502-Apple-1-Replica) - or - the ones such as the [*RC1802 Cosmac ELF*](https://github.com/tebl/RC1802-Cosmac-ELF), which was chosen based on the already excellent availability of software and documentation so I didn't have to write sufficient amounts of it. The RC-ONE, being based on the KIM-1, fits neatly into both of those categories - I could not buy afford an actual one, but I could read almost all about it!

While we're on the whole *reading bit* and coming back to the topic of this supposedly being called a manual, most of the ancient wordy tomes of knowledge mentioning the computer will probably do a better job of conveying its capabilities through step-by-step guidance - so it is my hope that this manual won't have to be much longer than its actual length.

# 2> History of MOS KIM-1
As the story goes, without going so far as to actually fact-check things before repeating them from a spotty set of memories of someone born half a decade later... MOS was a company originally selling digital calculators, these were mostly constructed using on integrated circuits (ICs) produced by Texas Instrument (TI), but when TI themselves started undercutting the market by producing calculators for themselves they were soon forced to find other ways of earning a profit.

The object therefore was to create a new calculator they could produce themselves, so a new chip responsible for doing the calculations was made. However, the chip that was designed - the 6502 - was much more actually more advanced than what was necessary for a simple calculator due to the foresight of its designer, the legendary Chuck Peddle. It wasn't designed to be a simple chip capable of performing only a set number of calculations, it was a CPU capable of doing a lot more than that - it was able to do CPU-y things!

Anyway, the calculators weren't actually flying off the shelves and the 6502 itself didn't see much third-party use either - mostly because hardware designers didn't know what to do with it either! In order to make 6502 an attractive purchase they needed something to show off it's capabilities, something that buyers could toy around with in order to learn why they needed to base their next product around it - the MOS KIM-1 was what they came up with!

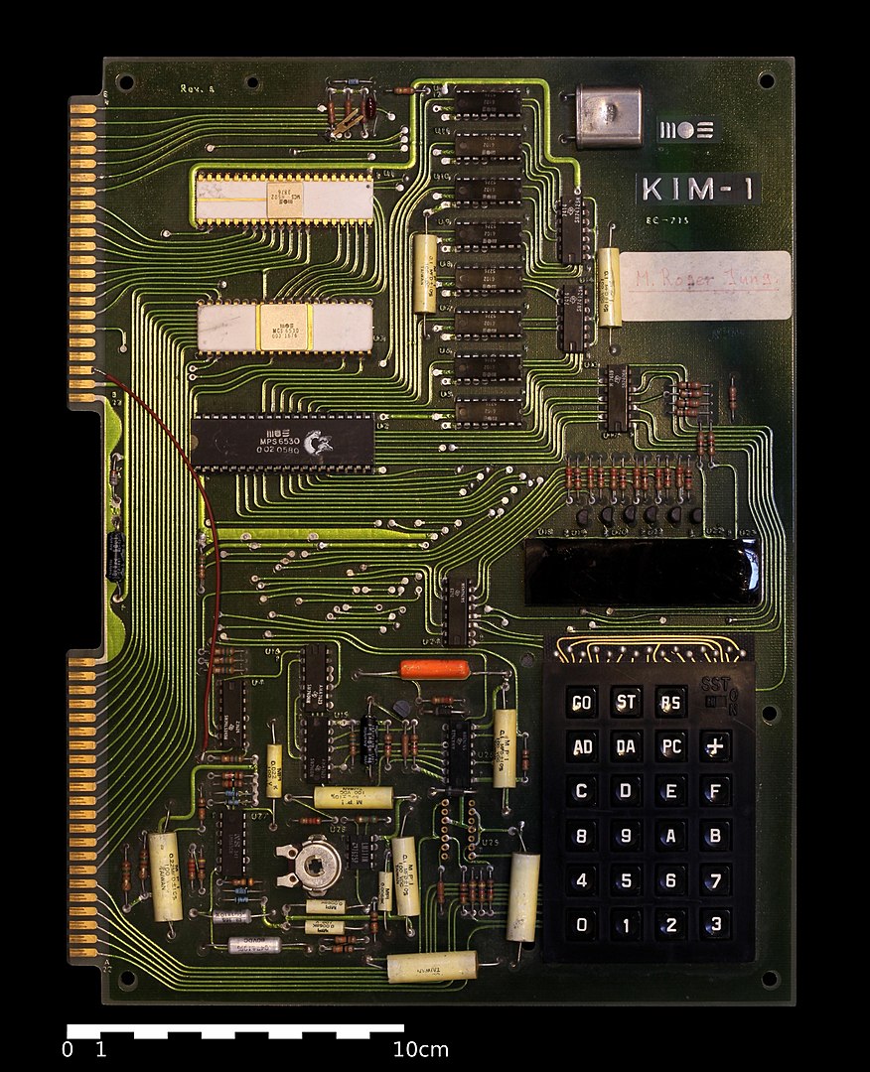
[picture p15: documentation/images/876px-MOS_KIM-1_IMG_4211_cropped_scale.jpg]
MOS KIM-1

> **MOS KIM-1 computer. On display at the Musée Bolo, EPFL, Lausanne.**
> Source [Wikipedia](https://en.wikipedia.org/wiki/KIM-1#/media/File:MOS_KIM-1_IMG_4211_cropped_scale.jpg): Rama & Musée Bolore-framing: Tomer T
> CC BY-SA 2.0 fr, https://commons.wikimedia.org/w/index.php?curid=18666108.

The KIM-1, standing for **K**eyboard **I**nput **M**onitor, probably didn't strike people as much more than an ordinary calculator kit though its success was in a market they probably never expected to exist in any substantial form; the home computer market!

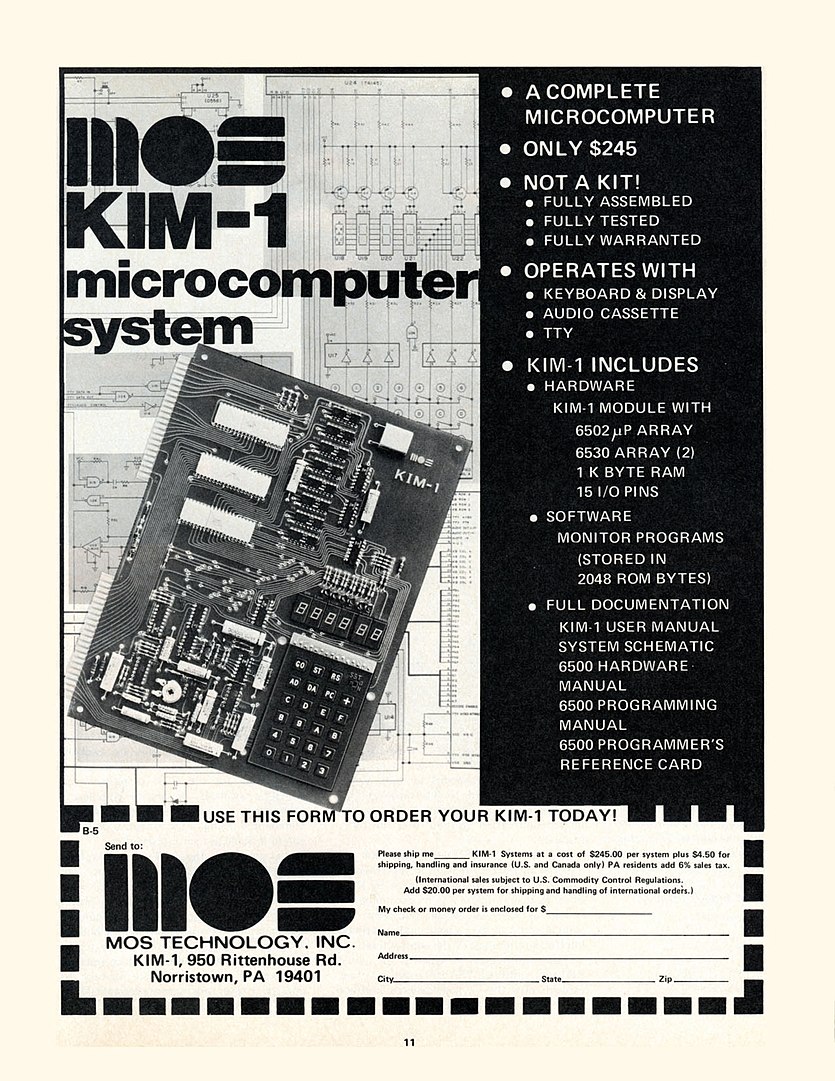
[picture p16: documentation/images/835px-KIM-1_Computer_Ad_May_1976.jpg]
MOS KIM-1, only $245

> **The introductory advertisement for the KIM-1 microcomputer, May 1976**
> Source [Wikipedia](https://en.wikipedia.org/wiki/KIM-1#/media/File:KIM-1_Computer_Ad_May_1976.jpg): MOS Technology Inc. Norristown, PA. - Scanned from the May 1976 BYTE magazine (page 11) by Michael Holley Swtpc6800 in August 2009
> Public Domain, https://commons.wikimedia.org/w/index.php?curid=8594032

Four paragraphs on overtime, a company called Commodore was struggling to make a satisfactory profit on the steadily declining market for mechanical typewriters, so they ended up buying MOS. The MOS KIM-1 became the Commodore KIM-1, later expanded to become the Commodore PET and so forth until we end up with my favourite computer of all time - the Commodore 64!   

Did you need to know all that? Probably not. 

## 2.1> Specifications
The heart of the KIM-1 computer was always its CPU, a MOS-branded 6502 CPU clocked at a whopping 1 Mhz. Without even attempting to account for the difference in the level of sophistication, but only going by pure clock speed it's at least 2000 times slower than my already ancient laptop. A 3$ Arduino will be actually be a lot faster than what this thing is clocked in at. On the other hand, and this is where it really gets interresting - that's still a million tiny tasks that could potentially be performed every second!

It had a single KB of static memory available, plus 128 words worth of memory giving it a total of 1152 bytes of RAM. I could return to the case of my sad laptop at this point and just mention that it has around 4 million times that, but the 1K wasn't actually all that much back then to be honest. That's after all only a 100 monkeys typing things in for 11.52 seconds before running out, accounting for adressing difficulties due to non-continuous memory and overrunning system memory not accounted for. The system monitor, the software allowing you to interact with the system is stored in 2K of ROM. 

In the category of I/O, you got a bit of everything in the package thanks to the versatility of two 6530 chip originally found on the system. The first one is dedicated to handling the keypad, serial TTY, the tape interface and outputting data to the six seven segment displays. The last 6530 was yours to do with as you wanted, that's 15 bi-directional I/O lines that could be used to change the world - one short-circuit at a time!

Well, that's what you got!

## 3> A brief history of RC-ONE
If you've already read the previous chapters, then the briefest of history for the RC-ONE that I can give has already been given. Read on for the for the slightly less brief history.
    
Still here? Well, then who's a good boy [or girl]? You are, I guess...

The RC-ONE project as my big follow-up to the RC6502, it was my summer of 2017 project with all my hope and slightly more available time poured into it. Thinking it'd be easy now that I've learned the basics of 6502 and basic amateur PCB design, my first and second attempt at creating a compact, functional and affordable version of the KIM-1 - were of course complete failures and thrown into the pile of shame for later part extraction.

Summer of 2019 I threw out the old files and took a new tactic, this time keeping the main components of the 6502 computer on a separate CPU board putting all of the rest of the interface components a separate User Interface board. Divide and conquer, keeping both under the magic $5 limit on most PCB fabrication shops such as PCBway. Also needed a keypad, had to have something suitable for hammering out all my frustrations upon.

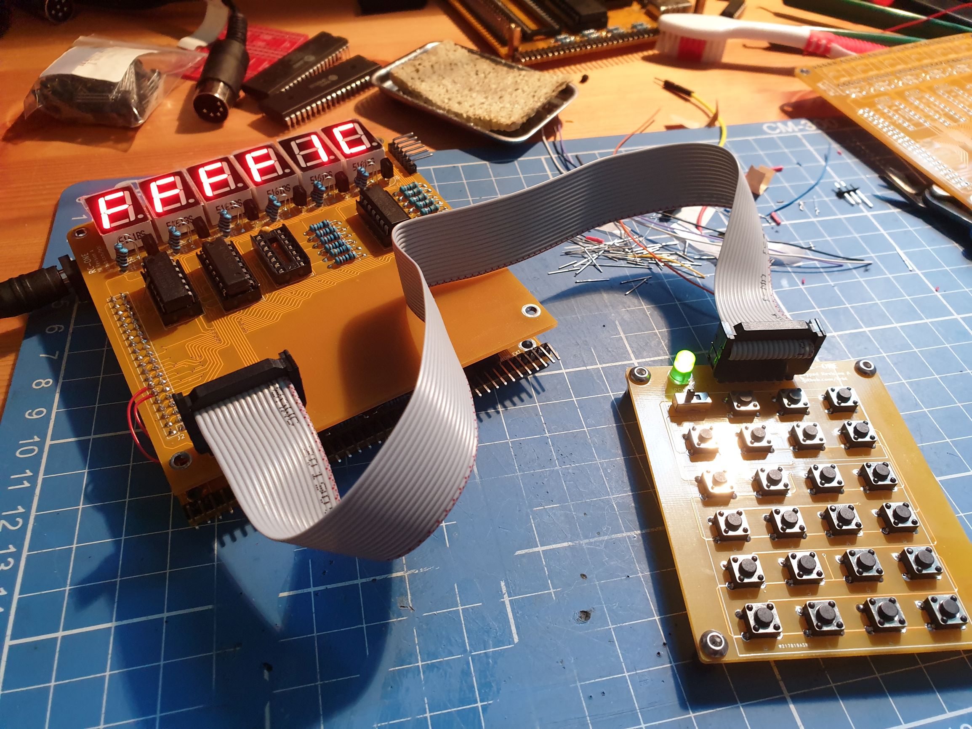
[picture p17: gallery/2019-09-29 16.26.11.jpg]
Revision A


The first of the new ones worked with some cutting and patching, the second perished in a fire due to last minute redesigns in order to avoid components that weren't so easy to obtain; I unfortunately live in a small country with a de-facto monopoly on the sale of electronic components to private citizens and they don't believe in stocking any of the older or cheaper components, so until the day Norway leaves the global market (probably january 2020) then my options have been the Chinese vendors via Ebay and AliExpress. Yes, I've gotten a lot of fakes - it's what I've got access to, after that I guess I'll have to consider hobbies not dealing with any sort of technology.

Revision B

Anyway, third time's the charm! Thankfully, in time before things really start grinding to a halt around here!

## 4> Construction
Welcome to the part where you'll be expected to play along, so get your soldering iron heated up and lets get going. First of though, make sure that you've got all of the components and modules necessary to build at least a basic RC-ONE system. The required modules have been listed in the table below, but for a complete list of available modules including all of the cool extras - see the main project [README](https://github.com/tebl/RC-ONE)!

| Module | RC-ONE | RC-ONE 65K |
| --- | --- | --- |
| [CPU](https://github.com/tebl/RC-ONE/tree/master/RC1%20CPU) | required | required |
| [User Interface](https://github.com/tebl/RC-ONE/tree/master/RC1%20UI) | required | required |
| [Keypad](https://github.com/tebl/RC-ONE/tree/master/RC1%20Keypad) | required * | required * |
| [Keypad MX](https://github.com/tebl/RC-ONE/tree/master/RC1%20Keypad%20MX) | required * | required * |
| [65K Expansion](https://github.com/tebl/RC-ONE/tree/master/RC1%2065K%20Expansion) | | required |
| [RC6502 Backplane](https://github.com/tebl/RC6502-Apple-1-Replica/tree/master/RC6502%20Backplane) | | required |

*) Only one Keypad module is required, the MX version is a lot more comfortable to use though it comes at an increased cost.

In order to build each of the modules, you'll need to obtain the pre-requisite number of components as specified - a component list will usually be found in something called a *BOM*, you'll find them separately listed for each of the modules by clicking on them above.

### 4.1> Watch the hot end!
If you turned on your soldering iron at the start of chapter 4, then waited for 2-6 weeks for a delivery from China, then I apologize for not thinking things through. If you've got everything ready, then get ready and turn on your soldering iron **NOW**!

Mentally or physically sort the components in order of height, start with the smallest components and work your way up to make things easy for yourself; do the diodes (not LEDs as those are pretty tall), resistors, monolithic capacitors if you have them and then sockets for all of the ICs. Then, probably the rest of the components as you'll probably have gotten the point by now.

If there is something you're unsure about, which holes to put the component leads into - then it's a good idea to put those aside for now, it'll probably make more sense as the other components slot into place. When doing the connectors, try doing a test-fit to ensure that things slot together like you expect them to (check twice, solder once).

You should already have some practice using a soldering iron before building something like the RC-ONE, but given that we're in the post-YouTube world you can find all manner of excellent tutorials that show you exactly how things are done (just press skip on the video if you encounter the standard arrogant, *you shouldn't do it if you're not already and expert with the best possible tools available* attitude). The short story; heat component lead, add solder to lead and remove the hot end within a second or so (keep fingers away from boiling hot metal).

Take your time, there's no need to hurry things along and build everything in a single night or even a single week - those that don't take things slow are doomed to burn their fingers and accidentally create solder bridges in the wrong places! After you're done, check the default jumper on the various modules so that you have a known good configuration before moving along to the next step.

UI Module
CPU Module
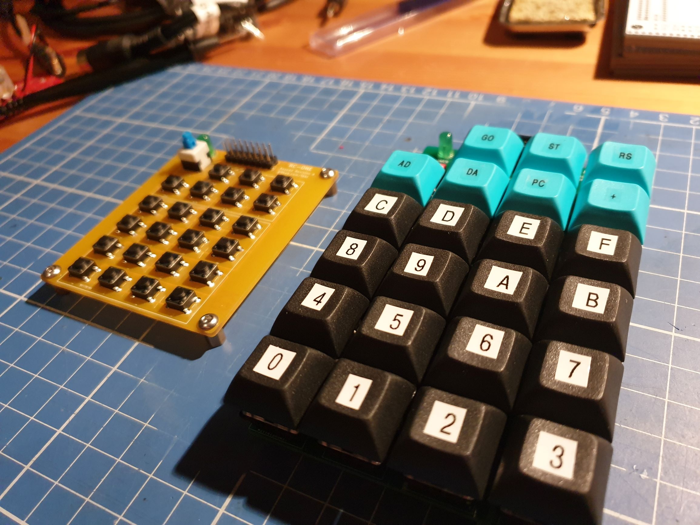
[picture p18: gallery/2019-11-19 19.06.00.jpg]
Keypad and Keypad MX


### 4.2> Before applying power
Before powering it up by connecting, there's a few things that should be done in order to minimize the potential for any accidental damage to the system.

#### 4.2.1> Visual inspection
Start by doing a visual inspection of all things soldered and plugged into place, does it look like you missed a solder point? Is there a hint of even a tiny hint of solder that bridges across to somewhere it shouldn't?

Examine the ICs after plugging them in, does the alignment match up with the symbols on the board itself and have you made sure that none of the pins got bent underneath the socket instead of going down into it?

#### 4.2.2> Check for continuity (in all the wrong places)
At point you'll need a multimeter, but given that you've committed to building an actual computer by soldering it together I sort assume you already have one on hand. If you don't, then you don't even need those expensive Fluke thingies - the $10 version from your whatever chain that sells cheap tools, will probably be more than you need.

Find the continuity setting, it's the one that makes an irritating noise every time you touch both of the probes together. If you in a similar fashion to the aforementioned Aardvark, is a nocturnal sort of fellow [or gal] then your significant other'll probably learn to hate it the morning rolls around!

Check out the [datasheets](https://github.com/tebl/RC-ONE/tree/master/documentation/datasheets) found within the documentation-folder, look at the pinouts listed. An example for the 74Ls138 is shown below, the thing I'd like you to note down at the moment is where pin 1 is located (this'll always be your main reference point), the way the pins are numbered and especially for this section of the manual - the location of the pins labelled *VCC* and *GND*.

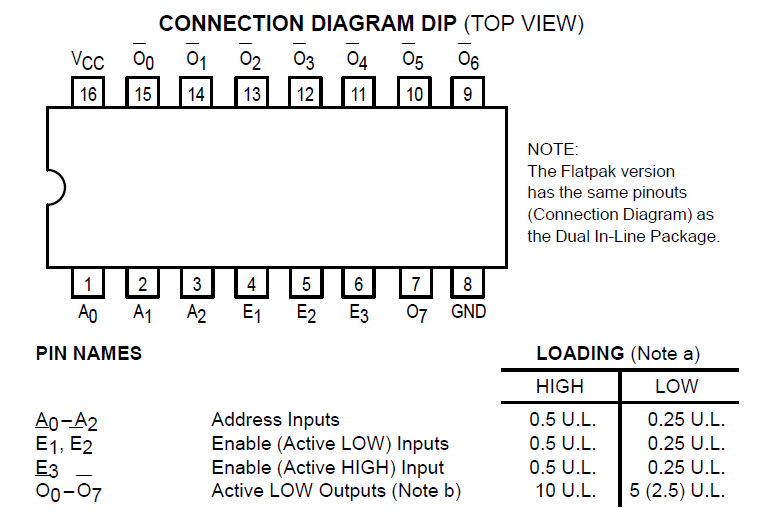
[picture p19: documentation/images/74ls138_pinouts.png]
74LS138 Pinout


Put one of the probes on *VCC* and the other on *GND*, if the multimeter makes a beeping sound then you've got a short in the worst of places. Never attempt to power up a system in this state before finding the short, you'll either overheat the power supply or most likely turn parts of the PCB into a shortlived heater until some of the traces turn into ash (I'm not joking about this part)!

Do this for all of the modules you've built, preferably without them connected together so that any faults of this kind can be narrowed down even further.

**NB!** This is probably the point where you'll slot together the various modules using cables, baling wire and probably not a hammer (I may be judgning you, but only if you let me know you've done it this way). Pay careful attention so that none of the pins are out of alignment, this is very important!

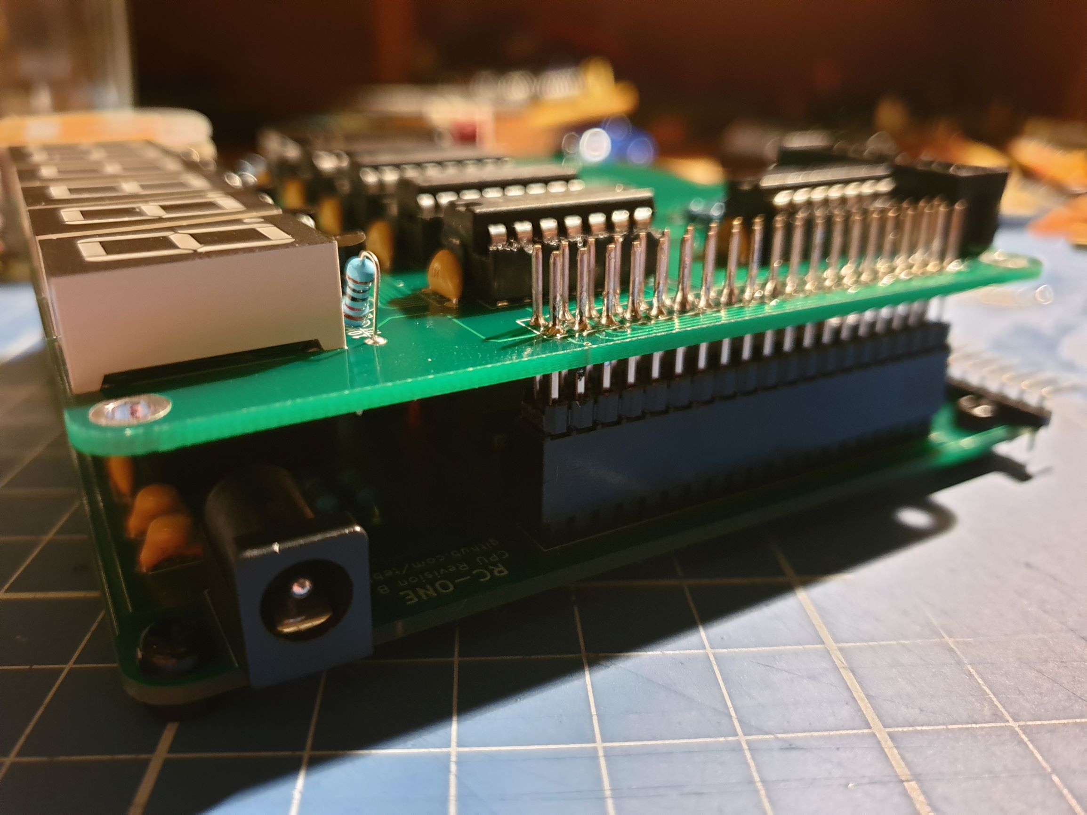
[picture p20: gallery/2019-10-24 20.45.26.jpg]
Pin alignment


#### 4.2.3> Connect the power
Connect a 5V DC power supply, it should have a barrel connector and you must use one that has a positive center pin - there should be an illustration on the power supply itself that makes this perfectly clear. Note however that as a retro-computer afficianado you may have several negative-center power supplies in your collection, this will instantly and more than like permanently kill all the ICs on your boards!

All good so far? Good.

Connect the power, but only do so for a short while at first; observe the board carefully, is something smoking? If so, replace those components before powering it up and attempt to read up on the schematic in order to determine the root cause.

### 4.3 Connect the power (for real this time)
Connect the power as previously described, did something happen? At the very least you should have a green (or whatever colour you selected) LED lighting up on the keypad of your choice. Some of the 7-segment displays might even light up, but this is mainly due to the randomness of the computer being in an unknown state until it is properly reset.

Other computers you've worked with probably includes an automatic reset when you power it on, the RC6502 has one in the form of a 555-timer if you're wondering how that'd work in a circuit (with the RESET-signal present on the backplane connector, you can actually make a separate expansion that does this for you if you'd like to). Anyway, the KIM-1 didn't include one - and so the RC-ONE in its current revision doesn't either. You need to manually press the *RESET* (**RS**) button on the keypad in order to reset the computer. Hopefully the displays light up, letting you bask in the electronic afterglow of having a computer that more or less runs!

**NB!** Make sure that the *SST* switch is off, this means that the DIP-switch/slide-switch or something else entirely, that has a direction, is in the left position.

### 4.4> When things fail
If you've gotten to this point and everything works;
> Congraturation,
> This story is happy end.
> Reset to starting point.
> Challenge again!

Didn't work at all or just some things working? If nothing is working, return to the start of chapter 4 and start there again - read the pinouts and use your multimeter to ensure that each of the chips are receiving somewhere in the vicinity of 5v on the pins labelled VCC (some might say VDD though - same thing, different conventions of naming things). Beginners tip; put the black one on somewhere named *GND* and the red on the one you're measuring, check manual for which setting to use when measuring voltage.

Find the reset pin, ensure that it is also 5v unless you're sitting on the *RESET*-button (then, why would you choose to do that?). Do the same for the clock pins on the 6502 (pins 37 and 39), the multimeter will average the reading while the clock swings between VCC and GND so you'll get around 2.5v and this is a good indication of things working without needing exotic equipment such as an oscilloscope. You probably won't be able to do most of that without removing the UI module, but that's OK as long as you don't do that with power connected!

Hopefully at this point something works, even if not perfectly; a consitent glitch, though scary at first is usually a very good sign as that means you're almost at the finish line. All that would remain now is around 99% of all learning with electronics: even more troubleshooting in the next sub-section!

If everything worked, skip right to the software parts - or - keep reading more for further extrapolated knowledge based on very little actual knowledge!

#### 4.4.1> Try some more logic
OK, so it didn't work the second, third or fourth time... don't despair, this is what the hobby is all about! Kim Jong-Un supposedly climbed the highest mountain in North-Korea waring formal shoes, so surely you can conquer the only KIM that mattered in the western world - the KIM-1 and it's later offspring, the RC-ONE!

The next step is attempting to apply structured logic to all of your troubles confined to the inner workings of the RC-ONE. This starts by printing out the schematic for each of the modules needed - print it in the largest sheet of paper you can force into your printer. Actual paper means you can make notes on said paper, larger paper means you can fit even more notes on said paper and finally you can study all of them in the peace and quiet that is required. Like the Aardvark you need to burrow into the logic, roll around in it and hopefully pieces'll start to come together.

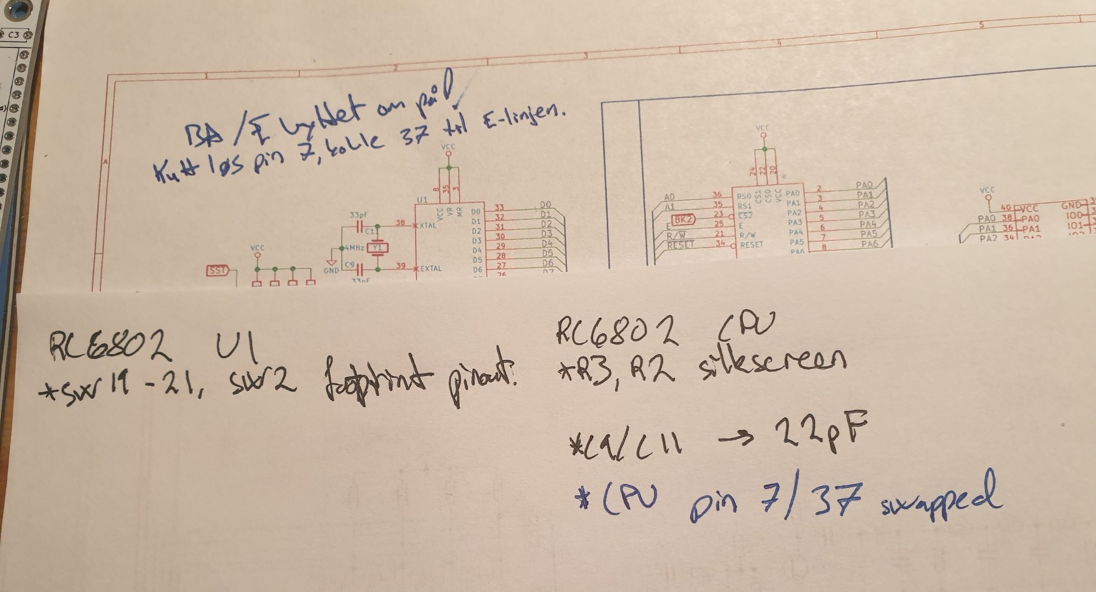
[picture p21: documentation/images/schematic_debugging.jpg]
Paper debugging


You don't need to understand all of it, you just need to understand the basics of it all to get started. Schematics make it easier to understand the logic in a design, it dictates how everything is connected and to what. Take note of the pin numbering used, remembering how things are numbered from previous chapters, and start continuity testing between the corresponding points on the board to see if things beep as expected or possibly without them being supposed to beep.

Note down on the paper things you've checked and are sure about, if you feel like starting a new pass then just get a new printout and start from there again. Try to narrow things down, anticipate what you think those components do and, if possible, how a fault at that point might look in a system that is not working.

I've also started putting things related to troubleshooting in a separate [Troubleshooting](https://github.com/tebl/RC-ONE/blob/master/Troubleshooting.md)-document as well, it'll be a bit more on the dry side though it might quite possibly contain that little extra nugget of wisdom required to get further in the build process. On that note, here ends the construction section of the manual. Sadness all around, but hopefully there's a happy little RC-ONE computer at the end of it all!

## 5> The software side of life
The software running on the RC-ONE is the same as the one powering the original KIM-1, it is a simple monitor that allows you to enter program using the hex-keypad (meaning it has keys numbered from 0 to F in hexadecimal), run it and even perform simple debugging. With the 65K Expansion you'll be able to put up to 6K worth of extra programs on the same EPROM, but on the base system you'll have to enter those the hard way (usually by typing them in, possibly even loading them from tape if I get that working). If you recall from some of those earlier pictures, the keypad on the RC-ONE will look something like the following:

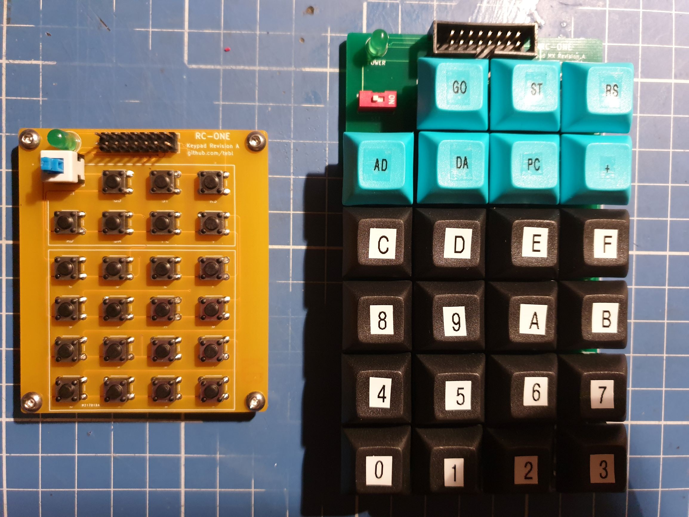
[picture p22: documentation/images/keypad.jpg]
Keypad


I won't go into more details on what each key does than what is shown below, as the book that originally came with the system - the [Programmers Manual](http://users.telenet.be/kim1-6502/6502/proman.html) will do a better job of explaining all the fine details. When looking for something a little more accessible, I highly recommend checking out The [First Book of KIM](https://archive.org/details/The_First_Book_of_KIM).

| Key | Description |
| --- | --- |
| SST | Right position to single-step code |
| GO  | Start executing from current address |
| ST  | Stop executing program |
| RS  | Resets the computer |
| AD  | Address mode, enter digits to set (4 digits) |
| DA  | Data mode, enter digits to set (last 2 digits) |
| PC  | Resume single-stepping after each step |
|  +  | Increases currently set address |
| 0-F | Enters digits into data or address depending on mode |

The first step that you always have to do before doing anything with the computer is to set the initalization vectors for the monitor. These are the addresses that the CPU will used to determing where it should start execution when an interrupt is encountered such as when pressing the ST-button to stop execution. The following snippet from the First Book of KIM describes this process in detail:

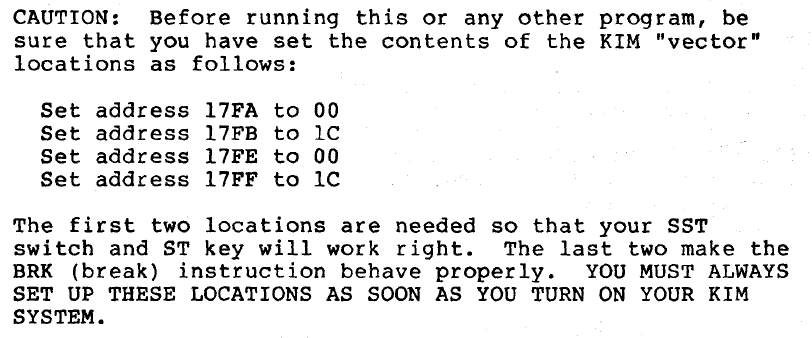
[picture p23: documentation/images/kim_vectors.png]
Reset vectors


The computer should already be in addressing mode after it has been reset, meaning that the next digits typed in will set the address on the first 4 displays. After typing in **17FA**, push **DA** to go into data entry mode and enter 00 using the keypad. Press the **+** key to go to the next address, verify that it is listed as **17FB** and enter **1C**. Keep pusing **+** to get to **17FE** and keep goint until all of the data has been entered.

### 5.1> Mapping it all out
Life may be like a box of chocolate, but computers not so much - unless you veer into unitialized memory, then all bets are off until you put something sensible into them. Returning to the magical number of **17FA** in the previous section, which is usually written as **$17FA** as it's a hexadecimal number - even more, it's a four digit address into the 64K of total address space that the 6502 processor is able to access directly. Where does this number come from?

Well, some numbers are magical - meaning that someone else, in this case the designer of the original KIM-1 decided that this specific address should be used for that uniquely specific thing. All of the machines that operate in the same fashion has rules determining how the system should react, in the case of a 6502-based system it all comes down to which memory addresses are assigned to the various segments of RAM, ROM or even more traditional devices that you'd probably not think of as a storage device (they probably aren't, but we call them registers when working with them like that). 

So where is everything? To answer that, we need a map and when dealing with anything 8bit you should find one for just about any computer you'll every work with (unless they come up with something better). This map is usually referenced to as the computers Memory Map, if you're lucky it exists and even matches the actual hardware you'll be working on in practice though you'll usually also need to refer to the datasheets related to the IC living in that area of memory. The RC-ONE has a map that looks something like the following:

Memory map preview

There's a lot of information to take in, but rememember that this is only used as a reference when programming new things into the computer so you don't have to remember everything - it's in a document so that I don't actually have to remember it. The picture only includes the highlights, in order to get the complete and most up to date information you'll have to check out the source material - available in [ODS](https://github.com/tebl/RC-ONE/raw/master/documentation/memory_map.ods)- or [PDF](https://github.com/tebl/RC-ONE/raw/master/documentation/memory_map.pdf)-format).

The essential part when getting started is just getting a feeling for where everything lives, you can see the differences between the original KIM-1 and the various versions of the RC-ONE.

### 5.2> Hello KIM-1
The chapter where we finally type in our first program, but not before setting up those interrupt vector you learned all about at the beginning of the chapter - do this now, the next time and every time before you start entering programs. With that done, let's go completely coocoo on this KIM-1 (*sort of*) by getting the important parts of the follwing assembler listing typed in:
```
0000-                  1               .CR     6502
0000-                  2               .TF     hello.hex,INT
0000-                  3
00FA-                  4       POINTL  .EQ     $FA     addressL on display
00FB-                  5       POINTH  .EQ     $FB     addressH on display
00F9-                  6       INH     .EQ     $F9     inputbuffer high
1F1F-                  7       SCANDS  .EQ     $1F1F
0000-                  8
0200-                  9               .OR     $0200
0200-                 10               .TA     $0000
0200-                 11
0200-A9 C0            12 (  2) START   LDA     #$C0
0202-85 FB            13 (  2)         STA     POINTH
0204-A9 0C            14 (  2)         LDA     #$0C
0206-85 FA            15 (  2)         STA     POINTL
0208-A9 00            16 (  2)         LDA     #$00
020A-85 F9            17 (  2)         STA     INH
020C-20 1F 1F         18 (  6) LOOP    JSR     SCANDS
020F-4C 0C 02         19 (  3)         JMP     LOOP
```

Well, that's certainly a bunch of information just to type in one simple program! I could probably have just given you the byte by byte listing instead, but where would the learning process be in that as you'd just be getting a load of magic numbers instead. This way is better, trust me!

Each assembly statement is one line, the lines are numbered from 1 to 19 and all of them equal a maximum of one machine language instruction (the stuff that the CPU knows how to execute). I say maximum because most of the lines at the beginning are just equates, they tell the assembler program information that should be used when converting the program to the machine language instructions. As programs for the KIM-1 usually do, the program should be loaded into memory starting at location $0200 (this is the first column of the code listing) and the first bits of data to be typed into the computer is on line 12.

Enter 0200 while in address mode (push *AD* if you're not sure), push *DA* to tell the monitor program that'll you'll be entering data next. The first instruction consists of two bytes, which is why there's two numbers listed after the address - type in *A* and *9* for the first one, push *+* to go to the next memory location and then enter C0 and hit the *+*-key again. The address part of the display should now read 0202 and we've come to the next line, continuing to enter data as you go along until the entire thing has been loaded into memory. Now imagine the mind-blowing experience this was back in those days!

To verify that everything was entered correctly, go back into address mode using the *AD* key and enter the $0200 address again. Use the *+* key again and verify that you've gotten all of the bytes in the correct place, correct if necessary. Keeping track of the addresses as you go along makes it easy to spot bytes left out, or those that snuck in without having a place in the program.

To run the program, return to $0200 (again). Hit *GO* and hope that the program runs the way it should - either the computer will go coocoo - or - you will!

Press the stop key (*ST*) when you're bored with the program, after that - either go looking for other more advanced programs to enter into the computer or write your own!

Check out chapter 7 for some of the places to find more stuff!

## 6> Going 65K
As you've probably already noticed from studying the extremely detailed memory map that I gave you somewhere around chapter 5, there aren't really all that many blocks of *free* address space that can be easily used for expansions in on unexpanded system - what you get is mostly K1 through K4. What happened to the other 56K available to the 6502, 8K1 through 8K8 to make them go all gray and unattractive?

The short story is that the base systems do not differentiate between any of the high address lines (partial address decoding), so that the bottom 8K is mirrored into every 8K section on the computer - their mirrors of eachother! Initially it would seem like a bad design choice, but when they made the system they already thought out a pretty nifty upgrade path for the system by building a 65K Expansion for the system (it's in the manual, that's what they called it back then).

What they did was add a jumper called *DECODER ENABLE*, this is *DEN* on the RC-ONE CPU board and it should be removed on a 65K system. Given that the RC-ONE also has a lot more RAM and ROM than what is normally accessible, mostly due to those ICs being a lot cheaper these days, I added a way of overriding the original memory decoding so that an upgraded system can access most of it. The table below summarizes the jumper settings used for a 65K system, these are all found on the CPU board of the computer. 

| Reference | Position | Description |
| --- | --- | ---  |
| DEN | o o | Remove jumper for a 65K system |
| RAM_EXT | 1-2 | Jumper when NOT using with 65K Expansion |
| | 2-3 * | RAM decoding is handled by 65K Expansion |
| ROM_EXT | 1-2 | Jumper when NOT using with 65K Expansion |
| | 2-3 * | ROM decoding is handled by 65K Expansion |

If you recall from chapter 4 there is one more module that you'll need in addition to the 65K Expansion itself - a backplane to connect it all together (this is why there's also those 39 pins at the bottom of the CPU board). Any compatible backplane such as the one that comes with the RC2014-line of computers can be used, as I've done in with the 65K computer shown below. Alternatively you can use the RC6502 backplane, it makes things a bit easier at it has the proper pin names used with a 6502 processor.

65K System

## 7> Where do I go now?
As with most things in life, that'll be up to you to decide and I'm neither old enough or wise enough to pretend I know the answer to that question. The Aardvar would probably find the answer using its long snout, then again it doesn't care much for old computers - if it'd ever encounter one, given that it is a medium-sized mammal mostly just living in Zoo-s outside of Africa there's a rather slim chance of that.

As previously mentioned an on the topic of the KIM-1 and the RC-ONE, you really should spend some time reading the [Programmers Manual](http://users.telenet.be/kim1-6502/6502/proman.html) to get the finer details I completely messed up or left out due to humour or downright neglect (is that possible when it's a hobby project?). The [First Book of KIM](https://archive.org/details/The_First_Book_of_KIM) is another excellent tome of knowledge, you mostly just have 20 pages in total to read - after that it's just program listings. Interest that the computer initially created spawned a magaine called the [Dr. Dobb's Journal of Computer Calisthenics and Orthodontia](http://6502.org/documents/publications/dr_dobbs_journal), all collected volumes are available online and there is no better way of learning about a system than reading through what the original owners did with their systems back then.

A gentleman named Jeff Tranter on YouTube made an excellent series of videos on the original KIM-1, those come highly recommended. [Part 1](https://www.youtube.com/watch?v=jj0Hn2ZcW-s), [Part2](https://www.youtube.com/watch?v=97PccuhGl9w) and finally [Part3](https://www.youtube.com/watch?v=3loypYCzEj8). He also provides a [GitHub](https://github.com/jefftranter/6502/tree/master/asm/KIM-1)-repository with a sizable collection of programs for the KIM-1 in one place.

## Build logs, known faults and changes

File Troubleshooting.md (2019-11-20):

# Troubleshooting
When starting out building a system from scratch, there is always the chances that something goes wrong along the way and - for many, even, the very act of troubleshooting and then getting it to work is what is at the heart of the computer-building hobby. Do not be disheartenet however as the RC-ONE is a very simple system, given the time to examine the various parts of the design you'll end up learning a lot more than if it had worked perfectly the first time!

## Visual inspection
Start by doing a visual inspection, does it look like you missed a solder point or do you see one where there might be a hint of solder bridging over to somewhere it shouldn't? Examine the ICs, verify that the alignment matches up with the picture on the board itself and that none of the pins got bent underneath the socket instead of going down into it. Check that you have added all the necessary jumpers in order to make it work, pay especially notice to the following positions:

- **VP_GND** next to the 6502 CPU, this needs to be jumpered in order to make a regular 6502 such as the SY6502, UM6502, R6502 and R65C02 function properly.
- **DEN** next to the address decoders, when not using the computer with a backplane and the 65K expansion then this needs to be jumpered in order to allow the computer to function.
- **K0_EXT** and **K7_EXT** allows the address decoding for RAM and ROM to be transferred to the 65K expansion, when using the computer as a standalone system these need to be jumpered across pins 1-2 (left position).
- **SSD_EN** on the UI module enables the seven segments displays, when using the system normally you want this to be jumpered across pins 1-2 (upper position).
- **TTY_MODE** on the UI module lets the system know you'll be using it in terminal mode, when this is jumpered you won't be able to use the keypad and displays as expected - so leave this unjumpered.
- **SST** switch on the keypad halts the computer after each cycle, make sure that it is in the left position.

When reassembling the system, make sure that the alignment of pins between the CPU and UI modules is correct - messing up on this step might cause issues along the way or even toast some of the ICs, PCB or both.

# Electrical checks
At point you'll need a multimeter, with the meter set to continuity and the computer disconnected from power - check between the two top pins of the UI connector, if it beeps then you have a dead short between VCC and GND and you should fix that before doing anything else. A 2-3 watt power supply might not seem like much, but they'll happily turn the wires on a PCB into ash before shutting down themselves so check that first.

Try powering up the board without the UI module attached, hopefully you'll see no indication anything is going on (no LEDs on it, so no change means nothing started smoking). Put the meter on voltage and check that each IC is powered, you might need to lookup some pinouts to do this to find which pin is VCC and which is the GND pin - on logic chips, with the indent at the top, you'll usually find ground at the bottom left corner and VCC at the top right corner. I've included some of the datasheets as part of my [documentation](https://github.com/tebl/RC-ONE/tree/master/documentation/datasheets).

Next step is checking that the CPU has a clock signal on it's input (Phi0) at pin 37, fourth down from the top right corner of the IC. An oscilloscope does come in handy here as it provides a clearer indication that the clock looks correct, but as a quick check with a multimeter instead you should see it average somewhere in the middle with around 2.5v (stuck at 0v or 5v is a clear indication of a problem). The rest of the system relies on a second clock signal, usually called Phi2, that is generated by the CPU - you'll find this on pin 39. On a multimeter it should look the same as the clock input, if it doesn't look right you should try changing the CPU.

From this point on you'll need to start pouring over the schematics for each of the modules, as most of the basics should be covered at this point. Even if you're not familiar with schematics and know instinctively what each part does, just start where you suspect the fault lies and starting working your way from there - it'll make sense in no time!

# STop and SST
The slide-switch marked SST is for single-stepping programs, it's deactivated in the left position. The STop key halts the program currently running and returns you to the monitor program.

Neither of these keys will work directly as instended, this is because you'll need to manually configure a couple of memory addresses with the expected values in order to have these function properly. These are the CPU initialization vectors, for settings these up you can refer to the following excerpt from the excellent [*The First book of KIM*](https://archive.org/details/The_First_Book_of_KIM) by Jim Butterfield:

Vectors

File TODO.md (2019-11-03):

# TODO
 - UI Board
	 - Add tape interface
	 - Test and verify TTY mode over USB

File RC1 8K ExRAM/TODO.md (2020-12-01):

# TODO
- [ ] Memory corruption
  - [ ] Figure out why data corrupts when running programs directly from it.
  - [ ] First byte always destroyed, but everything else stays consistent when using battery backup (even without Arduino).

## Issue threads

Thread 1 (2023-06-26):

Cassette issues

nateo87, 2023-06-26:
First of all, great project, I'm having lots of fun with it.
Second, I'm struggling a bit with regards to saving to tape. I think something needs to be done to massage the signal coming out of PB7. The output of that signal, (according to my oscilloscope) seems to have a HIGH of 5v no problem, but the LOW only goes halfway to GND, and thus will not trigger the NAND gate.
Can you confirm if this issue is due to my RIOT, or perhaps something needs to be done to attenuate the signal?
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

tebl, 2023-06-26:
To be perfectly honest, I never got that far. My knowledge of analog
electronics is non-existing, so once I ran into trouble it was shelved. It
may be up to a part substitute that wasn't quite as suitable, provided I
didn't straight up goof up somewhere.

man. 26. jun. 2023, 20:04 skrev nateo87 ***@***.***>:

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

nateo87, 2023-06-26:
No, I think you were extremely close with getting the cassette to work - I build a separate cassette interface off of the original schematics using the original parts, and the issue was the exact same. I wonder if the difference is between using a 6532 instead of the original 6530, as the datasheets tall about the output of PB5 - PB7 differently. Something about a "darlington drive"? Anyways, I'm gonna do some more digging around and see what I can figure out.

nateo87, 2023-06-27:
With some help from the Minimalist Computing FB group,  we were able to suss out what's been impeding both this and the serial signals. The NAND gates feeding back into peripheral bus I/O lines are normal 74LS00 NANDs, whereas in the original KIM schematic, these are the open collector 74LS38 variant. This allows the full signal to go out against output of that gate and thus, travel through the rest of the circuit. Unfortunately, I don't have any LS38s currently on hand, but I'm anxious to get a hold of some and see if this truly does solve the issue.

nateo87, 2023-06-27:
Here are pictures comparing the two schematics:
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

tebl, 2023-06-29:
Sounds like a thing I'd do, mainly going by how the symbol looked and
scratching my head when it does something on the spectrum between working
and blowing up.

Let me know how it goes, would be fun to see it do all of its tricks.

tir. 27. jun. 2023, 20:46 skrev nateo87 ***@***.***>:

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

nateo87, 2023-07-04:
Et voilà, we're getting cassette output!
[Here's a video showing successful output.](https://youtu.be/zLS9lcPwVUU)

tebl, 2023-07-07:
That's great! Did it load back from the tape as well?

ons. 5. jul. 2023, 01:27 skrev nateo87 ***@***.***>:

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

nateo87, 2023-07-20:
Hey! Sorry it has been a while, I've been on vacation and then I need to catch up on the work backlog. Anyway, I did not try to load back, I should have some time tonight to give it a go. I'm anxious to find out if it works!

BTW, I did try the serial connection, but I was only getting a single garbage signal back from the KIM. I think the signals might need more massaging looking at how other clones achieve it? Anyway, I'll start digging into that next after I confirm that the tape works.

jvangorkom, 2023-09-20:
I have been able to get the TTY connection working, though it took some time to model and understand how the connection and its interface circuitry worked.

U4 needs to be a 74LS38 not a 74LS00.
R23 and R25 need to be shorted / 0 ohms not 1k ohms.

U4 pin 6/9 need a 10k pull up resistor.
U4 pin 8 needs a 10k pull up resistor.

The frustrating part is realizing that the analog circuity used to connect the 78LS38 to the TTY port actually invert the signal.

So I made a small pc board with the 74LS00 on it and connected as follows:

com_pwr jumpered.

Daughter board.
2 - 6 pin headers for off board connections. (J3-RC1 and J3-TTL)
1 - 74LS00 (U1)

U1 pin 7 - gnd
U1 pin 14 - +5
U1 pins 9 and 10 shorted.
U1 pins 4 and 5 shorted.

J3-RC1 pin 1 goes to J3-TTY pin 1.
J3-RC1 pin 2 goes to U1 pin 9.
J3-RC1 pin 3 goes to U1 pin 6.
J3-RC1 pin 4 goes to +5.
J3-RC1 pin 5 goes to J3-TTY pin 5.
J3-RC1 pin 6 goes to gnd.

J3-TTY pin 2 goes to U1 pin 8.
J3-TTY pin 3 goes to U1 pin 4.
J3-TTY pin 6 goes to gnd.

Note J3-TTY pin 4 is not connected to prevent a power conflict between the two systems.

Tested using 2400, 8N1

jvangorkom, 2023-09-20:
Make the 2 pull up resistors 5.1k,  10k was giving me intermittent results

nateo87, 2023-09-21:
Very excited to try this out for myself, alas, I have a large backlog of projects first to get through. Getting the TTY working along with the cassette is gonna be really satisfying.

jvangorkom, 2023-09-21:
Right now, I am using oTerminal on a MAC to talk to the computer.

The New Line and Carriage Return commands are working perfectly.  But so far I have been unable to go to a specific address or change the value in an address.  Not yet sure what is going on.  At to eliminate a case issue I tried using only numeric addresses and sent the ASCII codes for space and dot directly.

jvangorkom, 2023-09-21:
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

The weirdness mentioned in the notes causes an automatic echo of text being sent to the Kim-1 to be sent back to the terminal

Nice for what is really just 2 logic gates and some inverters

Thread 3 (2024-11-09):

power up nothing on ui display

mciucci65, 2024-11-09:
I finish to assemble the RC1 but when powerup nothing is display on UI.

I'm using 28c256 need to do something to prepare bin file for programming ?

the 5v power it's ok led on keypaad is onand i alse checked with multimeter.
I did some more test and if I remove the riot chip 6532 some was displayed on UI.

Can anyone help me ?
I'm no sure that 6532 is full working china chip :-(

tebl, 2024-11-10:
It's been quite a while since I looked at a 6502, so the following may be a
bit more vague than what I would've wanted it to be.

The 6532 may be a likely culprit as any chip from China is likely to have
been pulled from a different system, and at times they get rebadged
something else - simply by having the same overall appearance. That's not a
guarantee though as you'd need to ensure that the 6502 is properly running
on its own, pay particular attention to the NMI and RESET signals - using a
multimeter, ensure that they momentarily go low when pushed and then go
high again. The clock is harder to observe without an oscilloscope, but a
multimeter will average over time so you'll see a voltage somewhere in the
middle (without being stuck high or low). Also make sure to follow the
steps in the Troubleshooting-document.

The board was designed for the 28C256, so just ensure that the jumpers are
set to where you put the firmware (or write it to each 8k-parts of the
chip, or just do what I do in the batch files and combine the data four
times to get 32k worth of data). A good guide to start reading for the
hardware-side, is this one: http://wilsonminesco.com/6502primer/.

If you do end up getting nowhere, one tip is to look at basic examples for
the assembly code. That way you can have the computer do exactly one thing,
and then try to observe it doing that specific thing. For example, just
doing a NOP-loop, then have it write a single value to a specific address
in RAM.

lør. 9. nov. 2024 kl. 17:14 skrev mciucci65 ***@***.***>:

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

mciucci65, 2024-11-10:
thanks for quick answer it's ok if I use a MOS 6502A CPU ?
Sure cpu it's working because a tested it on other 6502 project.

Other question the firmware 28c64 in firmware folder it's ready can I use it for duplicate for 28c256 eeprom ?
kind regars
MC

tebl, 2024-11-11:
Yes, a 6502A should work fine - as far as I know the only differences
should be its capability to run at speeds up to 2Mhz. The files in the
folder is what I've used on my computer, you can just look at the batch
file to see how you can combine four copies of it to fill the entire 28C256
(always helps to have one less thing to think about).

søn. 10. nov. 2024 kl. 05:43 skrev mciucci65 ***@***.***>:

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

tebl, 2024-11-12:
Serial is a bit harder as it's software-driven, so it's the first thing to
break if there's a problem somewhere. Easiest way to test is probably to
write a small program that alternates the outputs to the display.

tir. 12. nov. 2024, 11:01 skrev mciucci65 ***@***.***>:

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

mciucci65, 2024-11-14:
Hi Tebl,

I'm waiting for new 6532 but now I have a doubt:

for eeprom 28c256 I must do four copies of 28c64.bin or I need to compose the eeprom in diffrente mode:

I tried:

1) copy /b "28c64.bin"+"28c64.bin""+"28c64.bin""+"28c64.bin" "28c256.bin"

2)copy /b "blank_2k.bin"+"blank_2k.bin"+"blank_2k.bin"+"blank_2k.bin"+"blank_2k.bin"+"blank_2k.bin"+"blank_2k.bin"+"blank_2k.bin"+"blank_2k.bin"+"blank_2k.bin"+"blank_2k.bin"+"blank_2k.bin"+"blank_2k.bin"+"blank_2k.bin"+"blank_2k.bin"+"system.bin" "28c256.bin"

3)copy /b "blank_2k.bin"+"blank_2k.bin"+"blank_2k.bin"+"system.bin"+"blank_2k.bin"+"blank_2k.bin"+"blank_2k.bin"+"blank_2k.bin"+"blank_2k.bin"+"blank_2k.bin"+"blank_2k.bin"+"blank_2k.bin"+"blank_2k.bin"+"blank_2k.bin"+"blank_2k.bin"+"blank_2k.bin" "28c256.bin"

but nothing with all eeprom bin files

kind regards

tebl, 2024-11-14:
Number 1) should work regardless of what the A13/A14 jumpers are set to, as
all 8k slots are the same.

Number 2) would only work with both  jumpers set to high.

Number 3) would only work with both jumpers set to low.

Also check that DEN, EXT_RAM, EXT_ROM has been jumpered correctly.

tor. 14. nov. 2024, 12:56 skrev mciucci65 ***@***.***>:

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

mciucci65, 2024-11-19:
thank you for your great support the issue has been resolved after I changed the 6532 received today.
thank again
kind regards
mc

tebl, 2024-11-19:
Glad it worked! Nothing more satisfying than a well-earned victory over the
machine 😅

tir. 19. nov. 2024, 13:22 skrev mciucci65 ***@***.***>:

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

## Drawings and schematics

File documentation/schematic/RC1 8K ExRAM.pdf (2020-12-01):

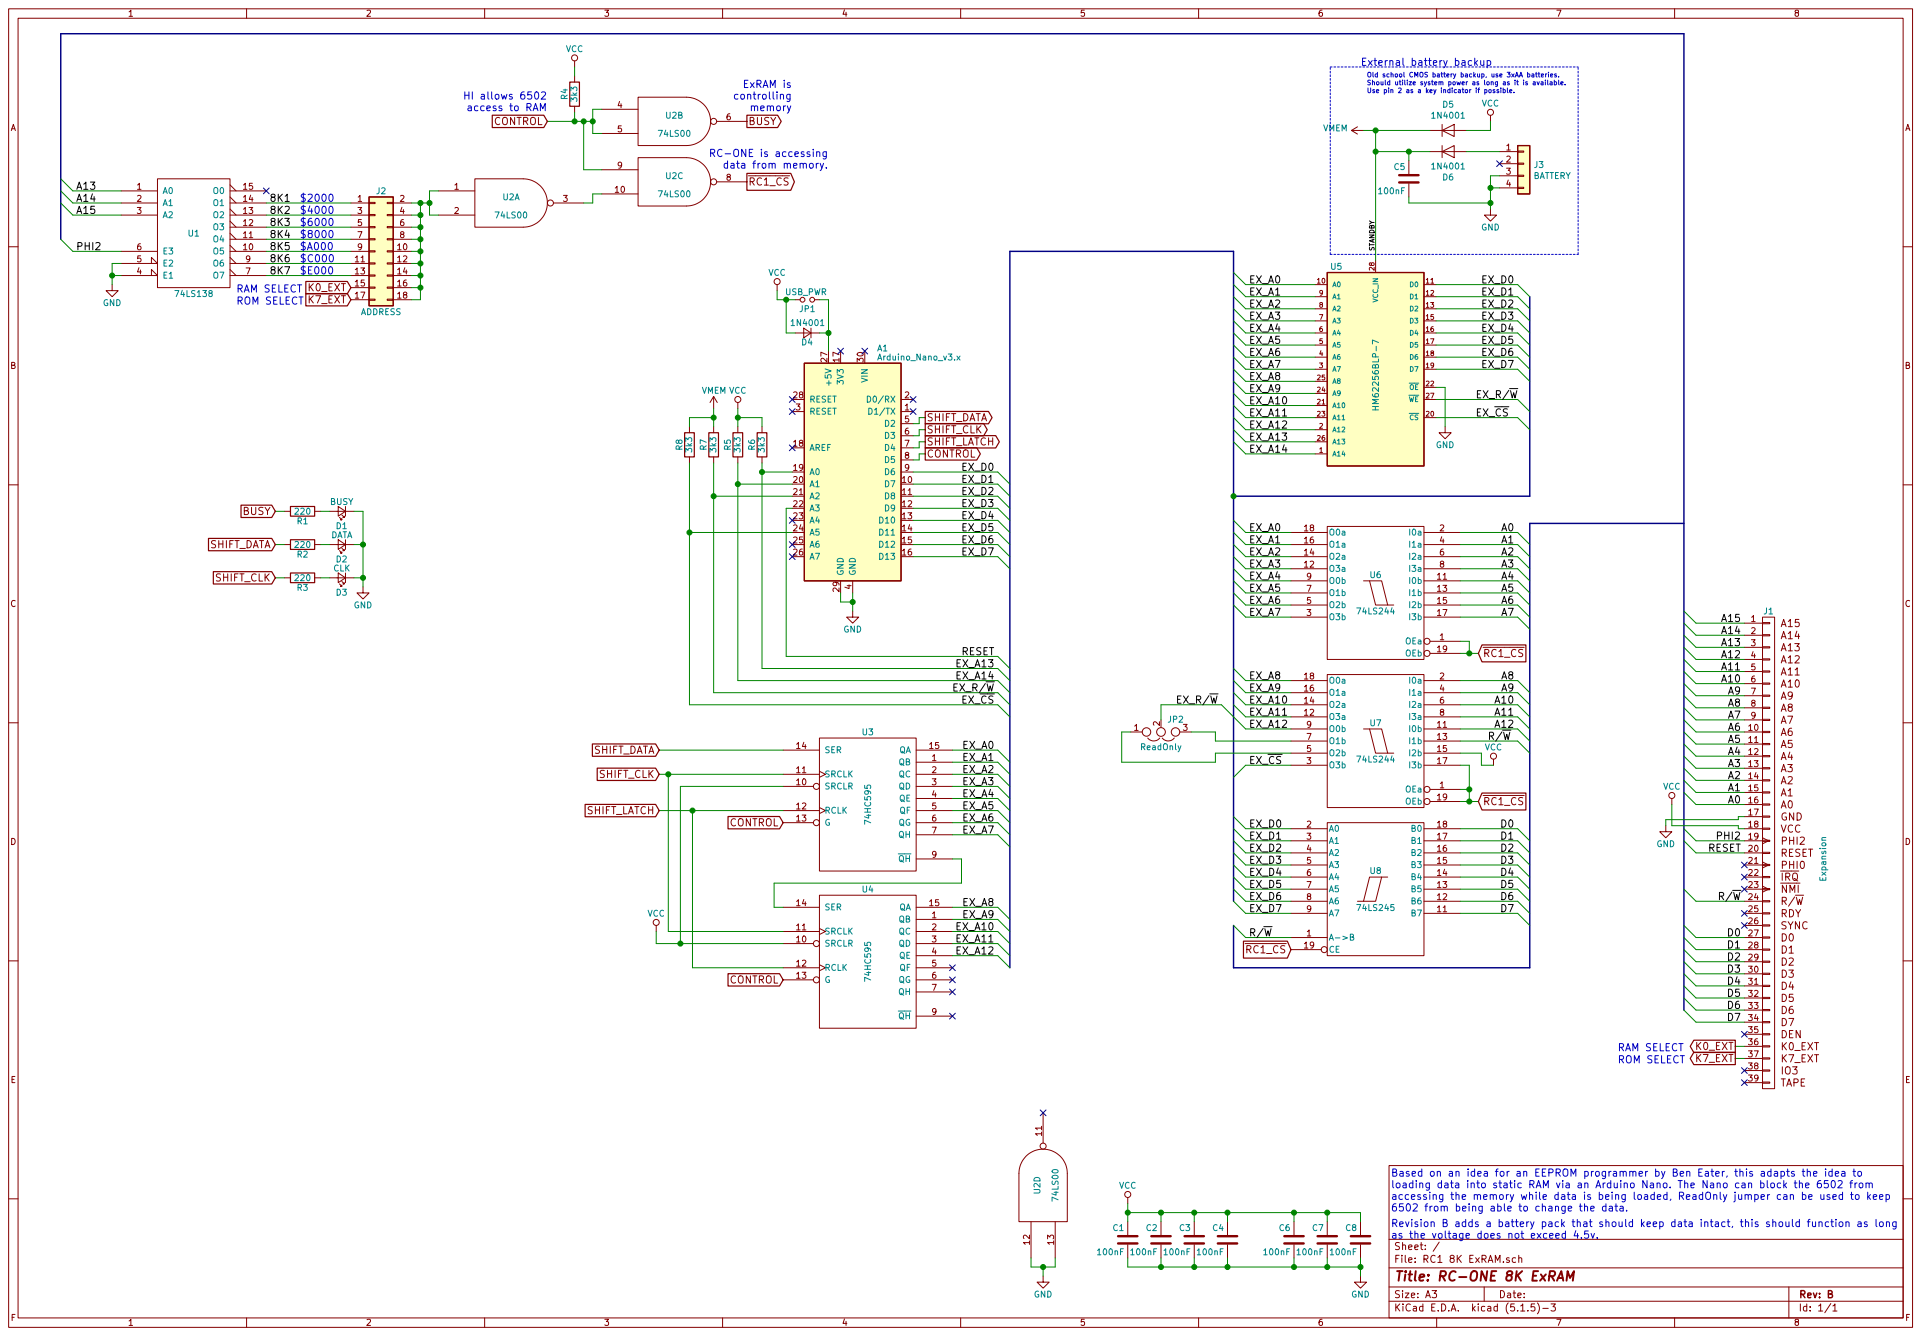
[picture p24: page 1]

Old school CMOS battery backup, use 3xAA batteries. Should utilize system power as long as it is available. Use pin 2 as a key indicator if possible. External battery backup

$6000 | 5 | 6
$8000 | 7 | 8
$A000 | 9 | 10

4 D2 5 D3 6 D4 7 D5 8 D6 9 D7 10 A1 20 VIN 30 D8 11 A2 21 D9 12 A3 22 D10 13 A4 23 D11 14 A5 24 D12 15 A6 25 D13 16 A7 26 3V3 17 +5V 27 AREF 18 RESET 28 A0 19 GND 29 A1Arduino_Nano_v3.x GND

Based on an idea for an EEPROM programmer by Ben Eater, this adapts the idea to
loading data into static RAM via an Arduino Nano. The Nano can block the 6502 from
accessing the memory while data is being loaded, ReadOnly jumper can be used to keep
6502 from being able to change the data.
Revision B adds a battery pack that should keep data intact, this should function as long
as the voltage does not exceed 4.5v.

File: RC1 8K ExRAM.sch Sheet: / C6

Id: 1/1 Title: RC-ONE 8K ExRAM

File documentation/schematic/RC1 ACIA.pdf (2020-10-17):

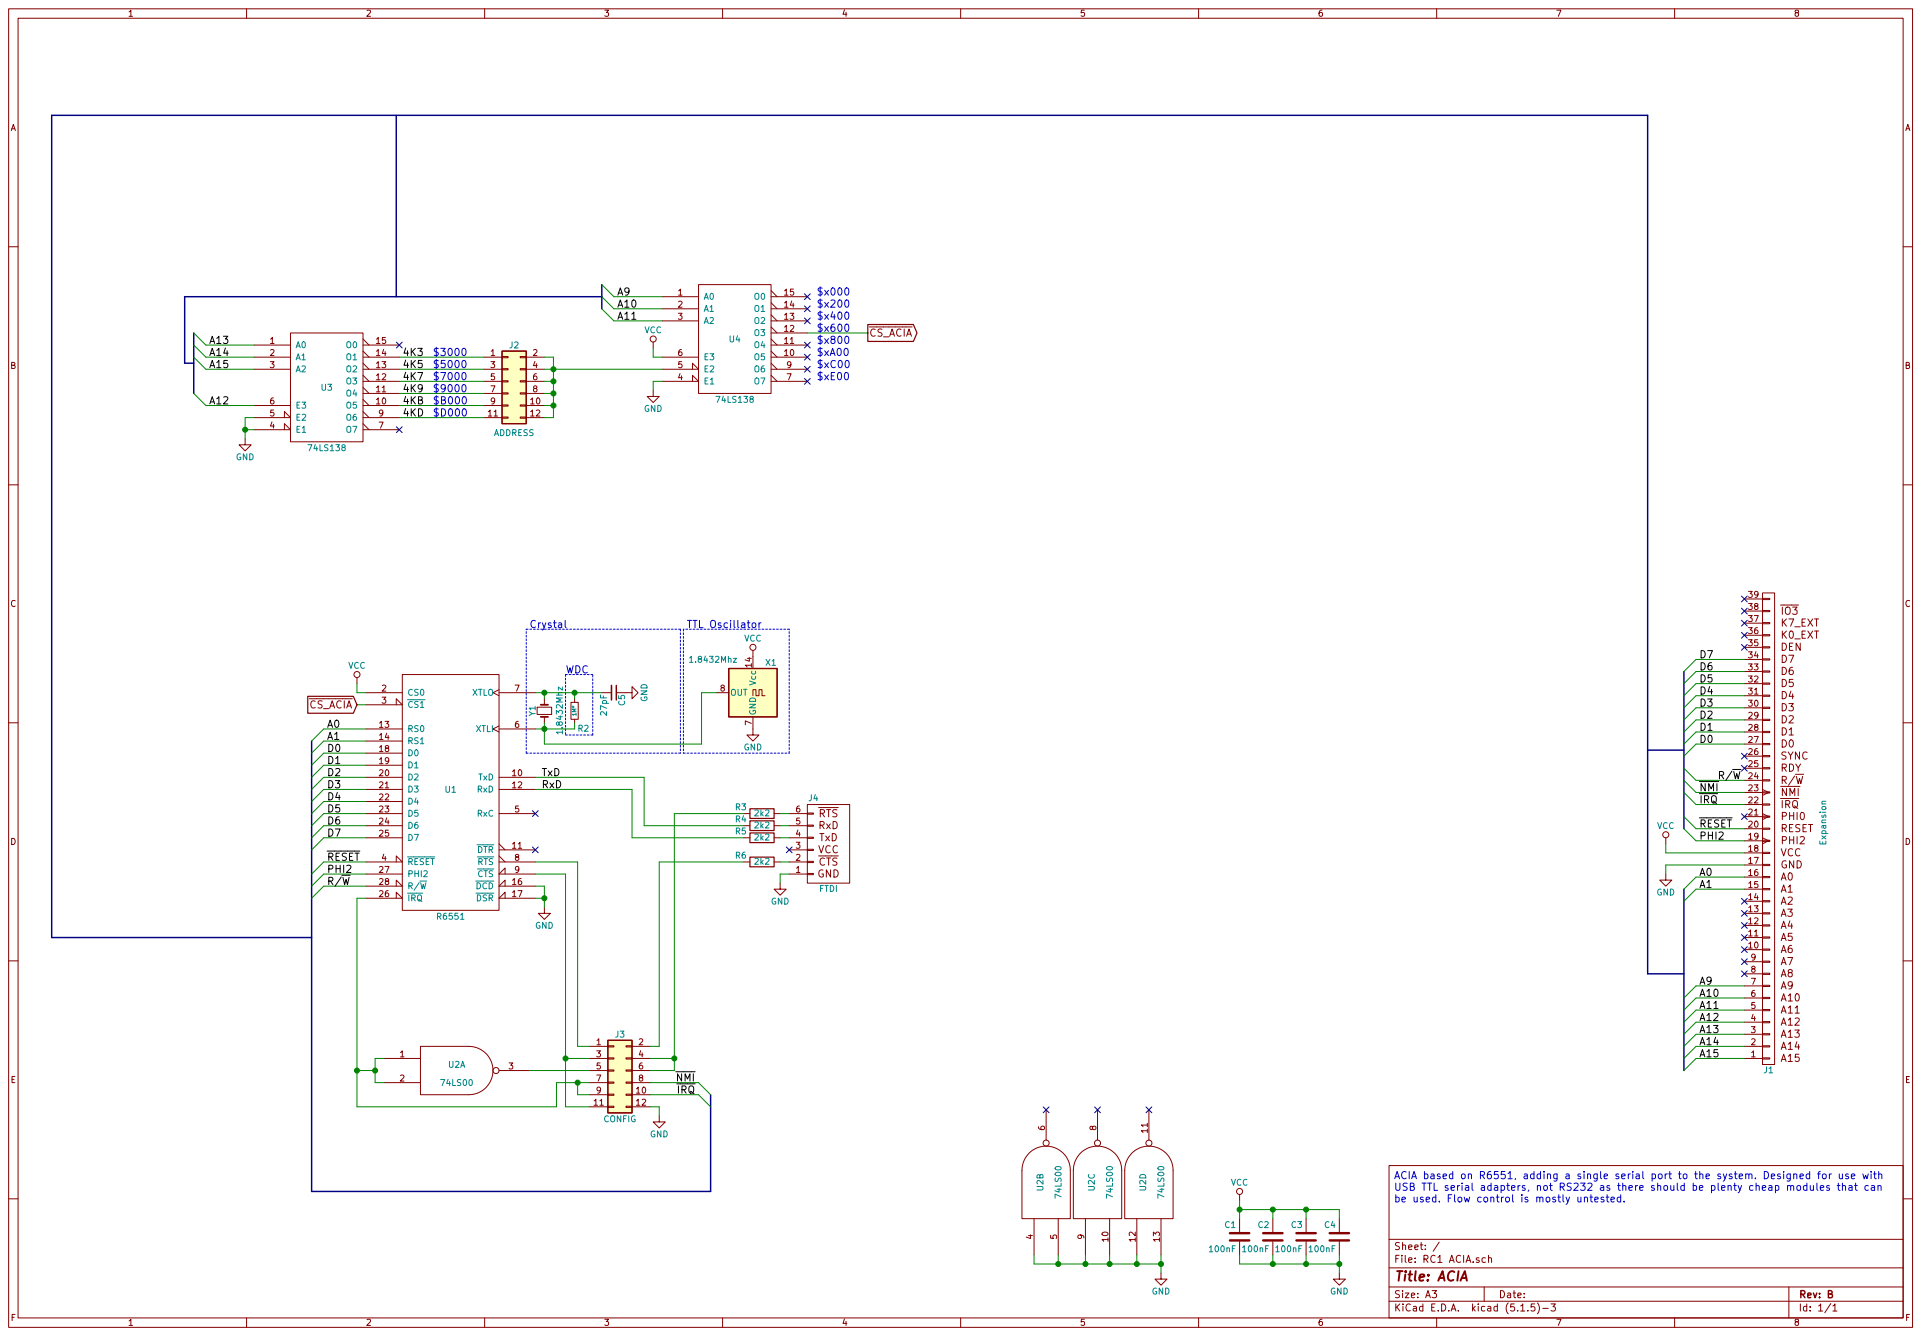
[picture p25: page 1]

4KB | $B000 | 9 | 10 | TTL Oscillator
4KD | $D000 | 11 | 12

File: RC1 ACIA.sch Sheet: / GND

IRQ 22

A14 A0 ACIA based on R6551, adding a single serial port to the system. Designed for use with

9 | 10

USB TTL serial adapters, not RS232 as there should be plenty cheap modules that can
be used. Flow control is mostly untested.

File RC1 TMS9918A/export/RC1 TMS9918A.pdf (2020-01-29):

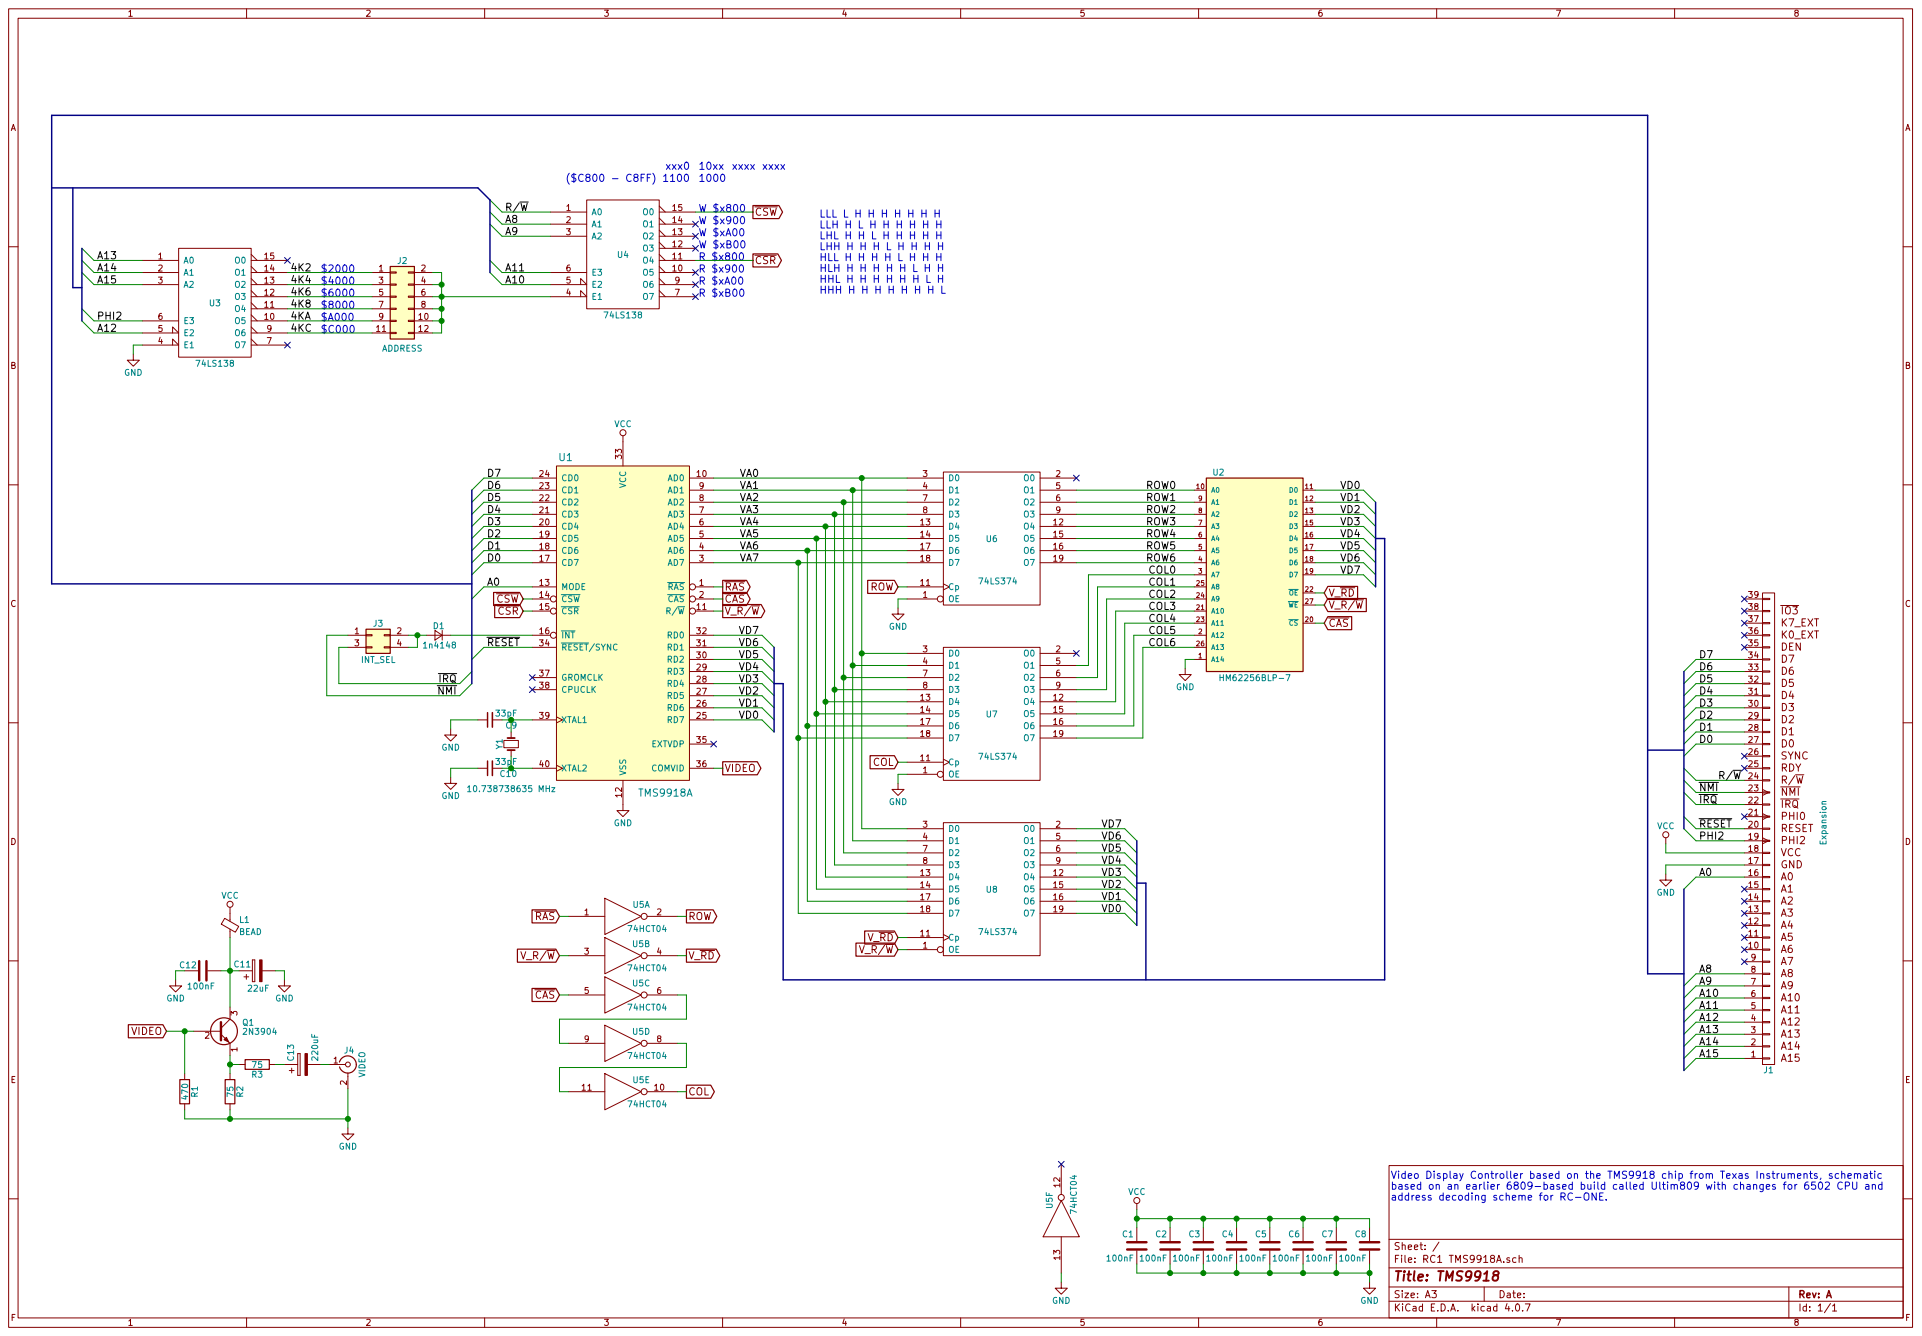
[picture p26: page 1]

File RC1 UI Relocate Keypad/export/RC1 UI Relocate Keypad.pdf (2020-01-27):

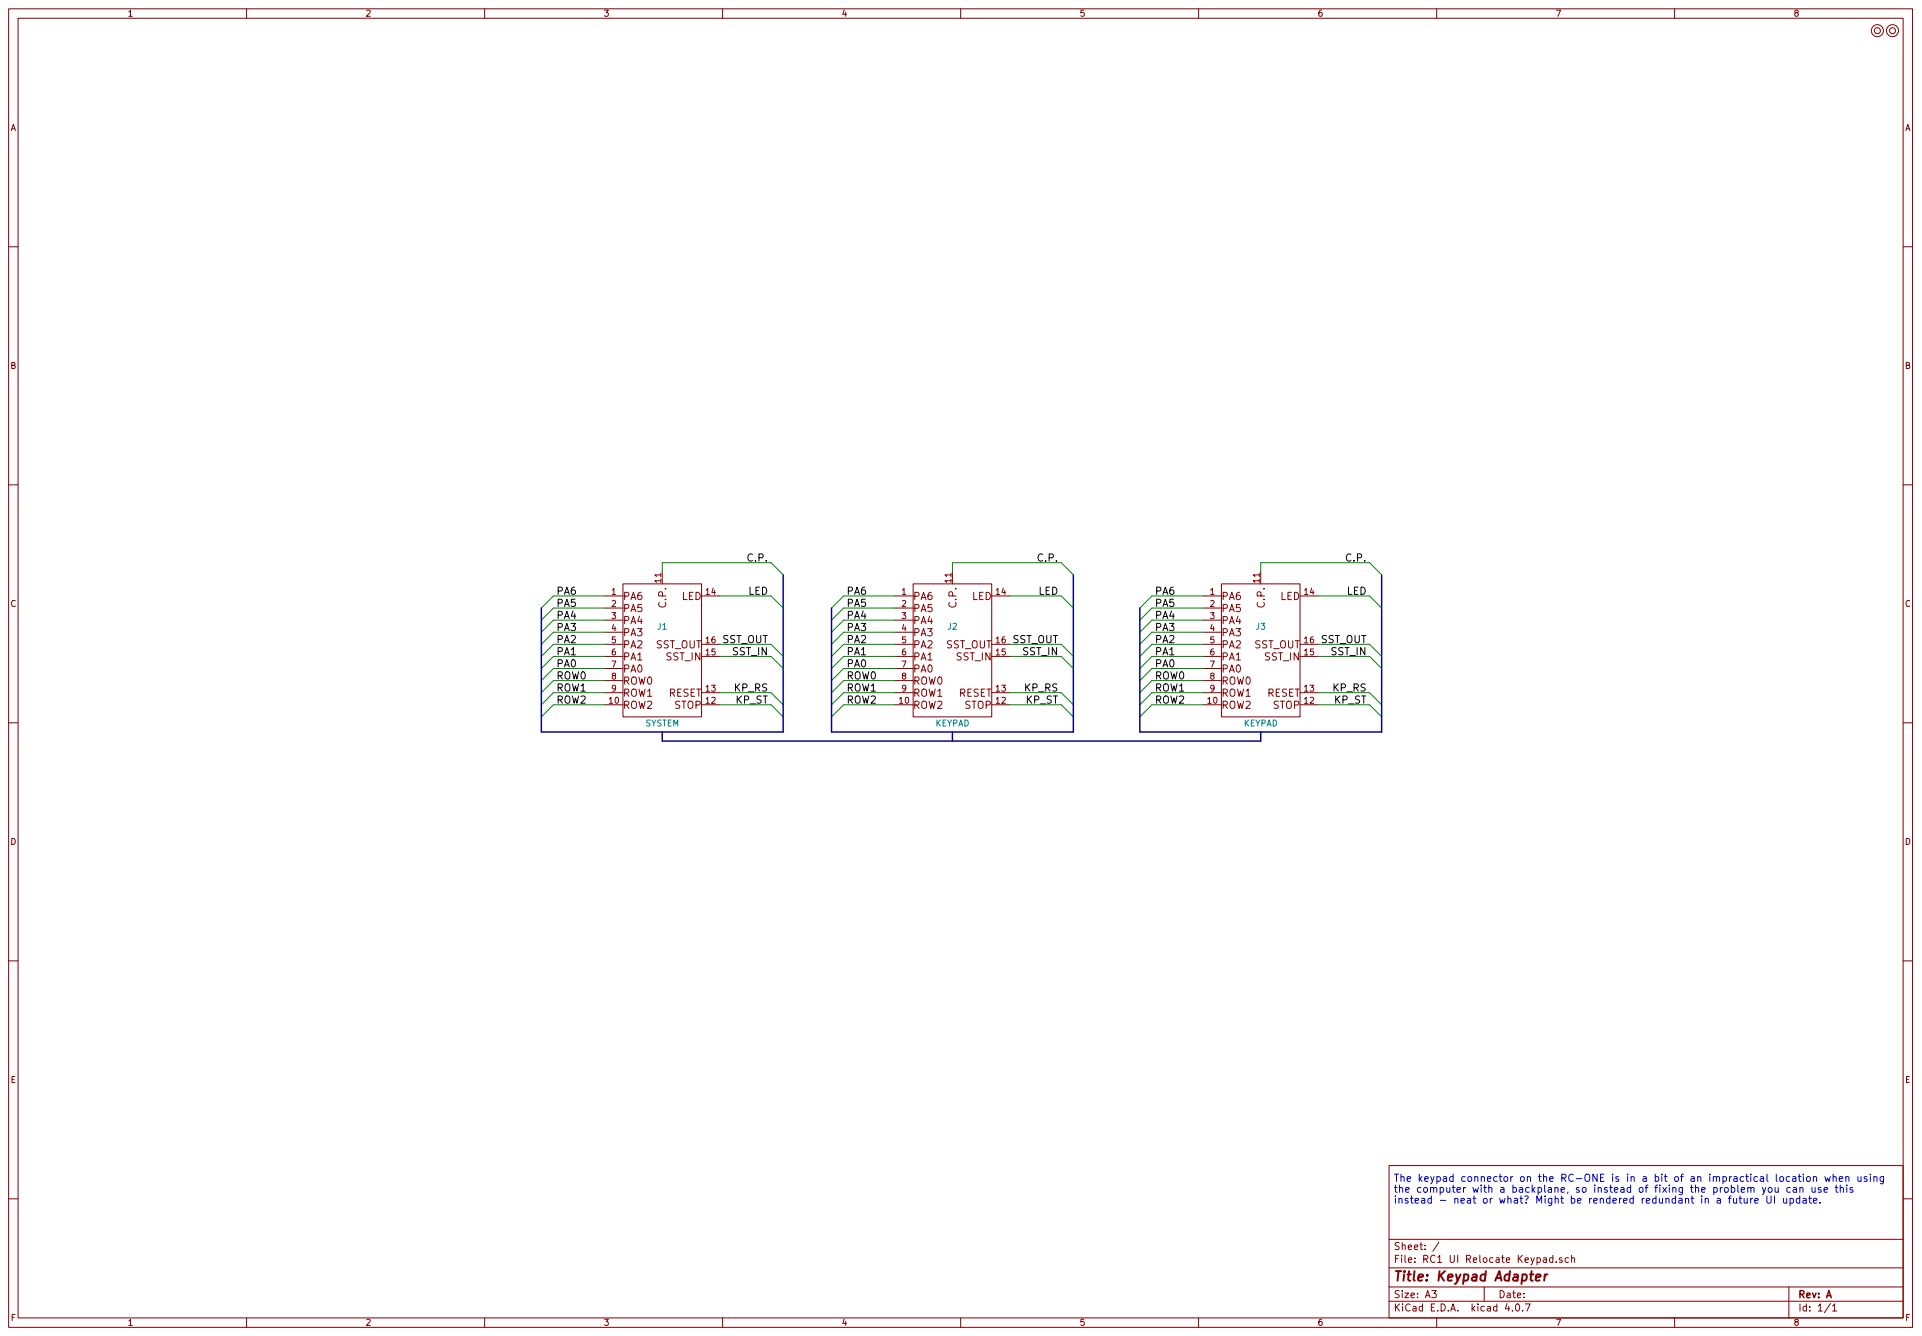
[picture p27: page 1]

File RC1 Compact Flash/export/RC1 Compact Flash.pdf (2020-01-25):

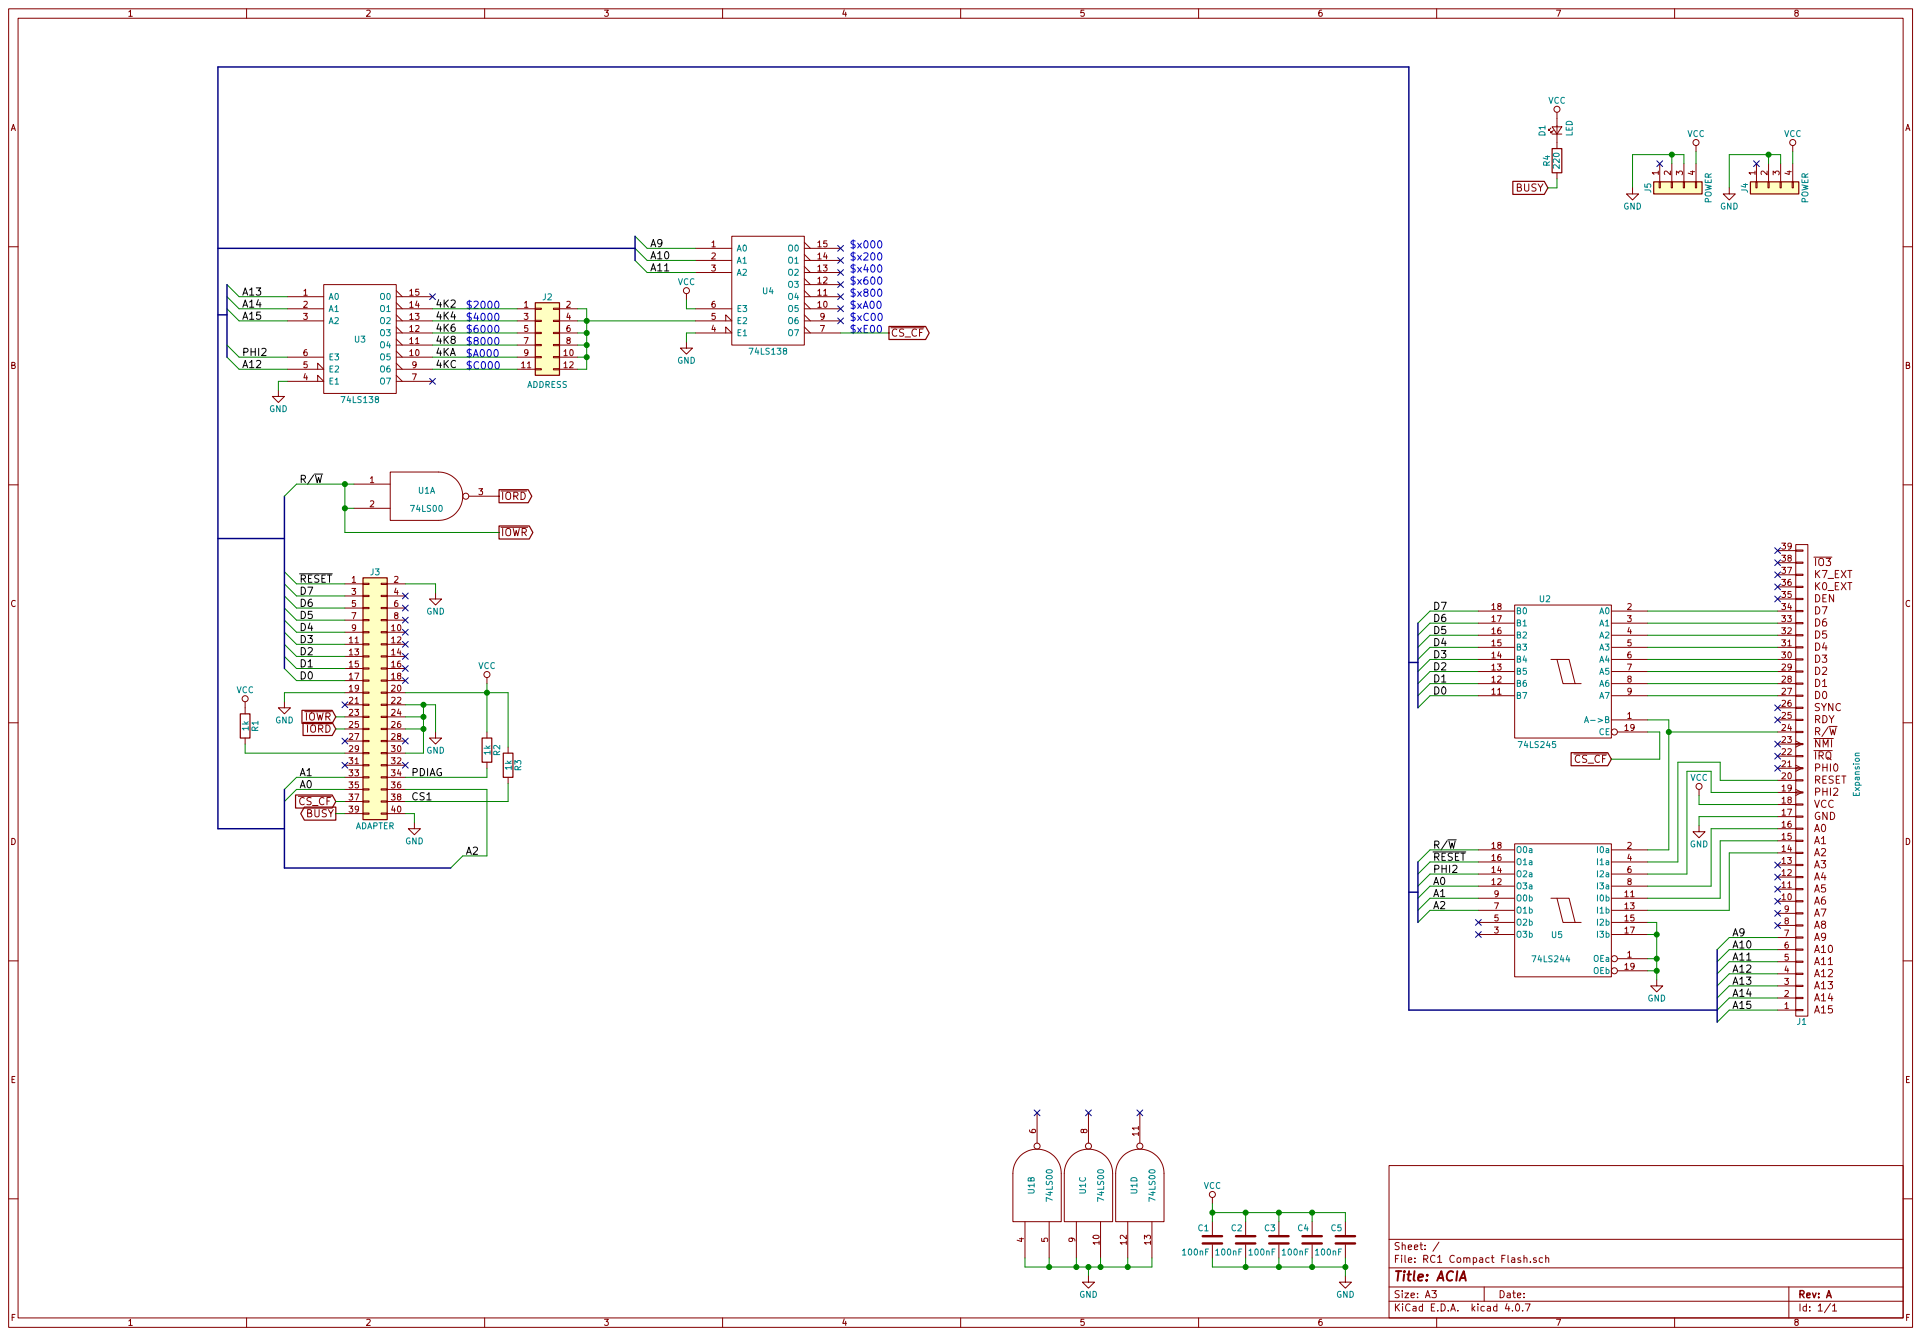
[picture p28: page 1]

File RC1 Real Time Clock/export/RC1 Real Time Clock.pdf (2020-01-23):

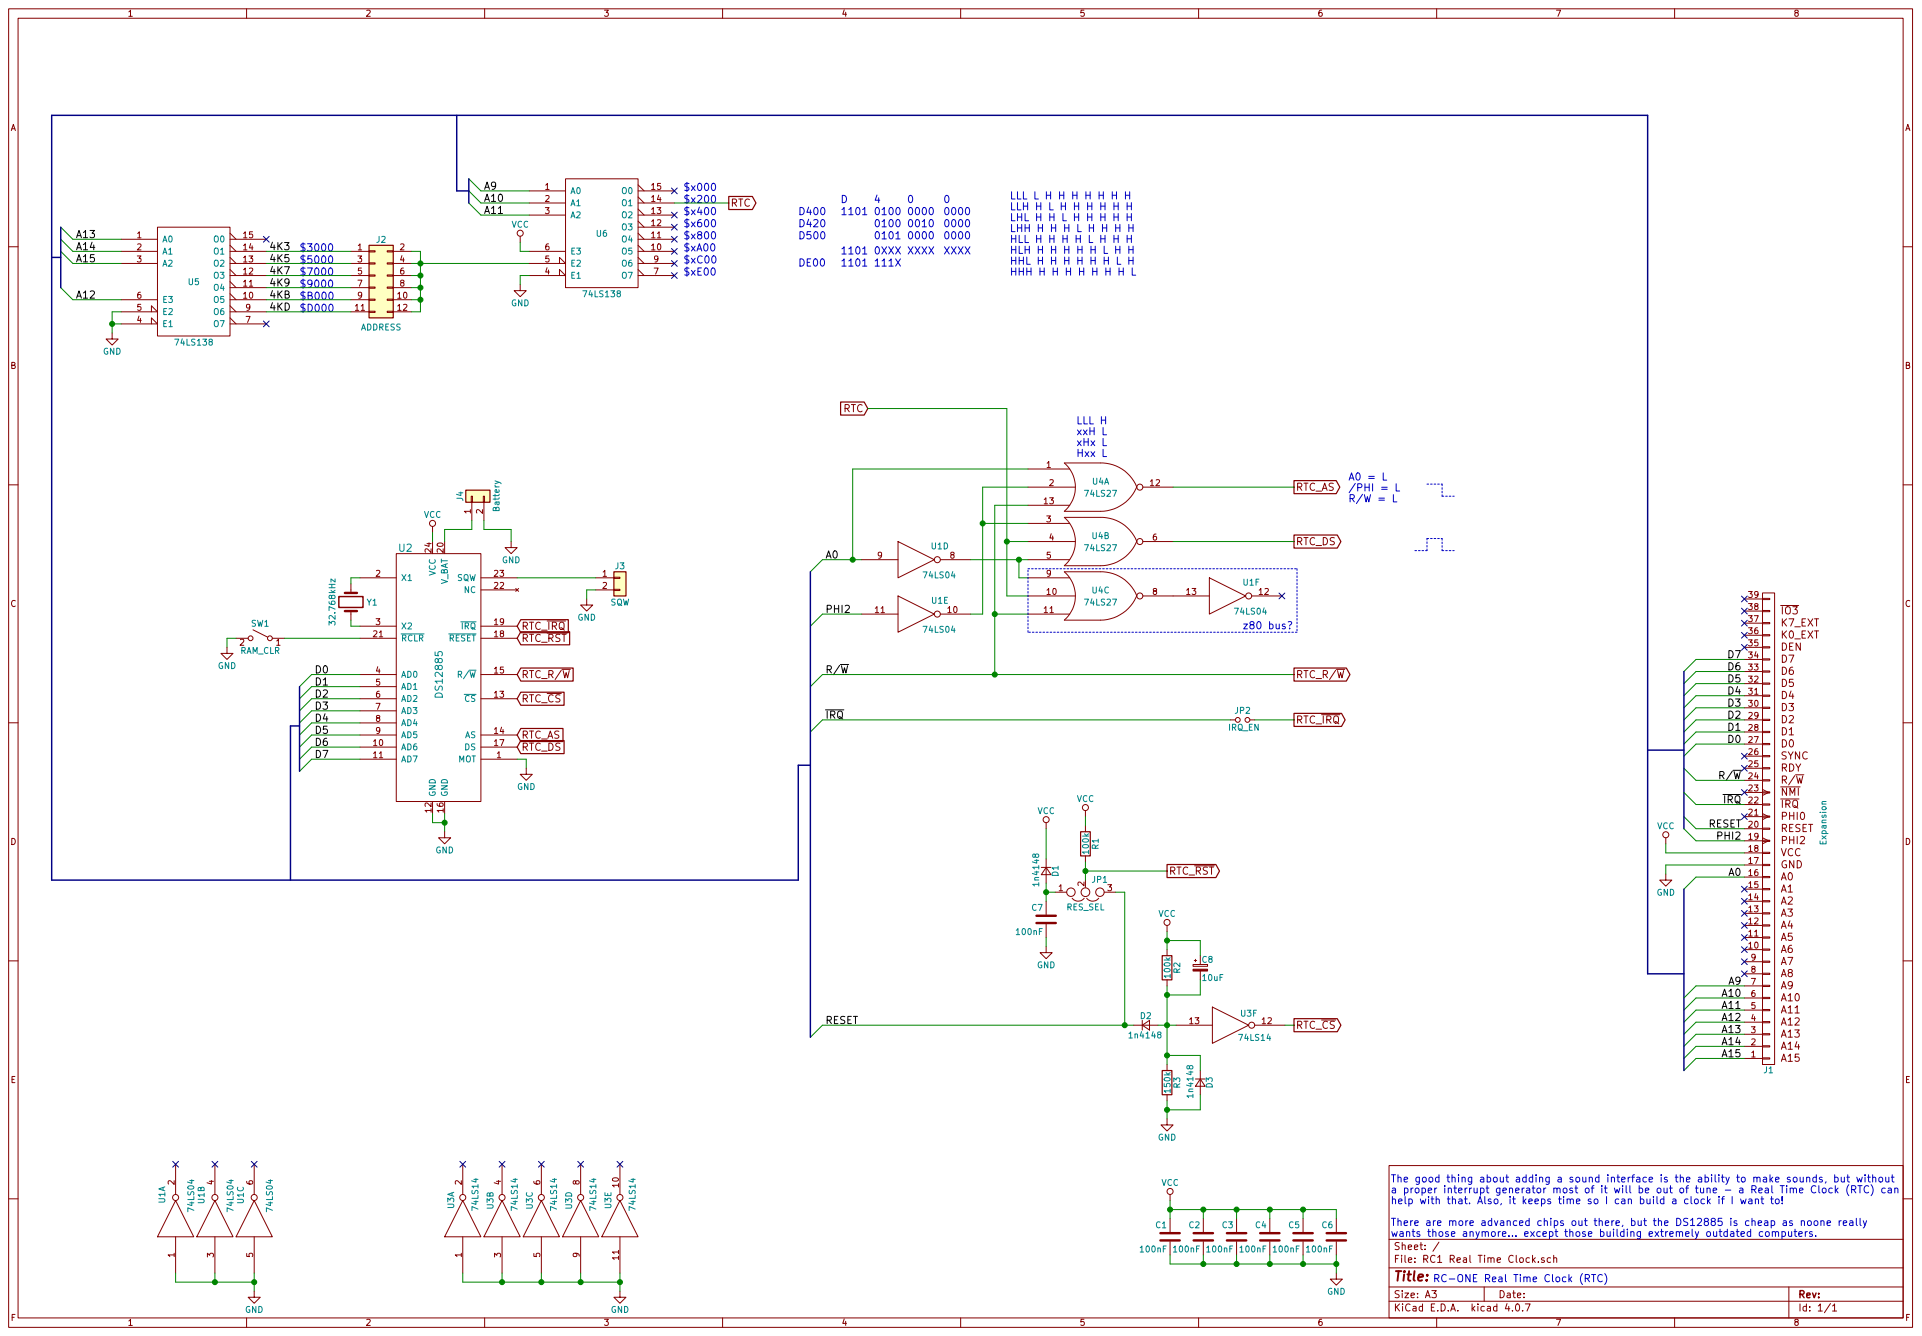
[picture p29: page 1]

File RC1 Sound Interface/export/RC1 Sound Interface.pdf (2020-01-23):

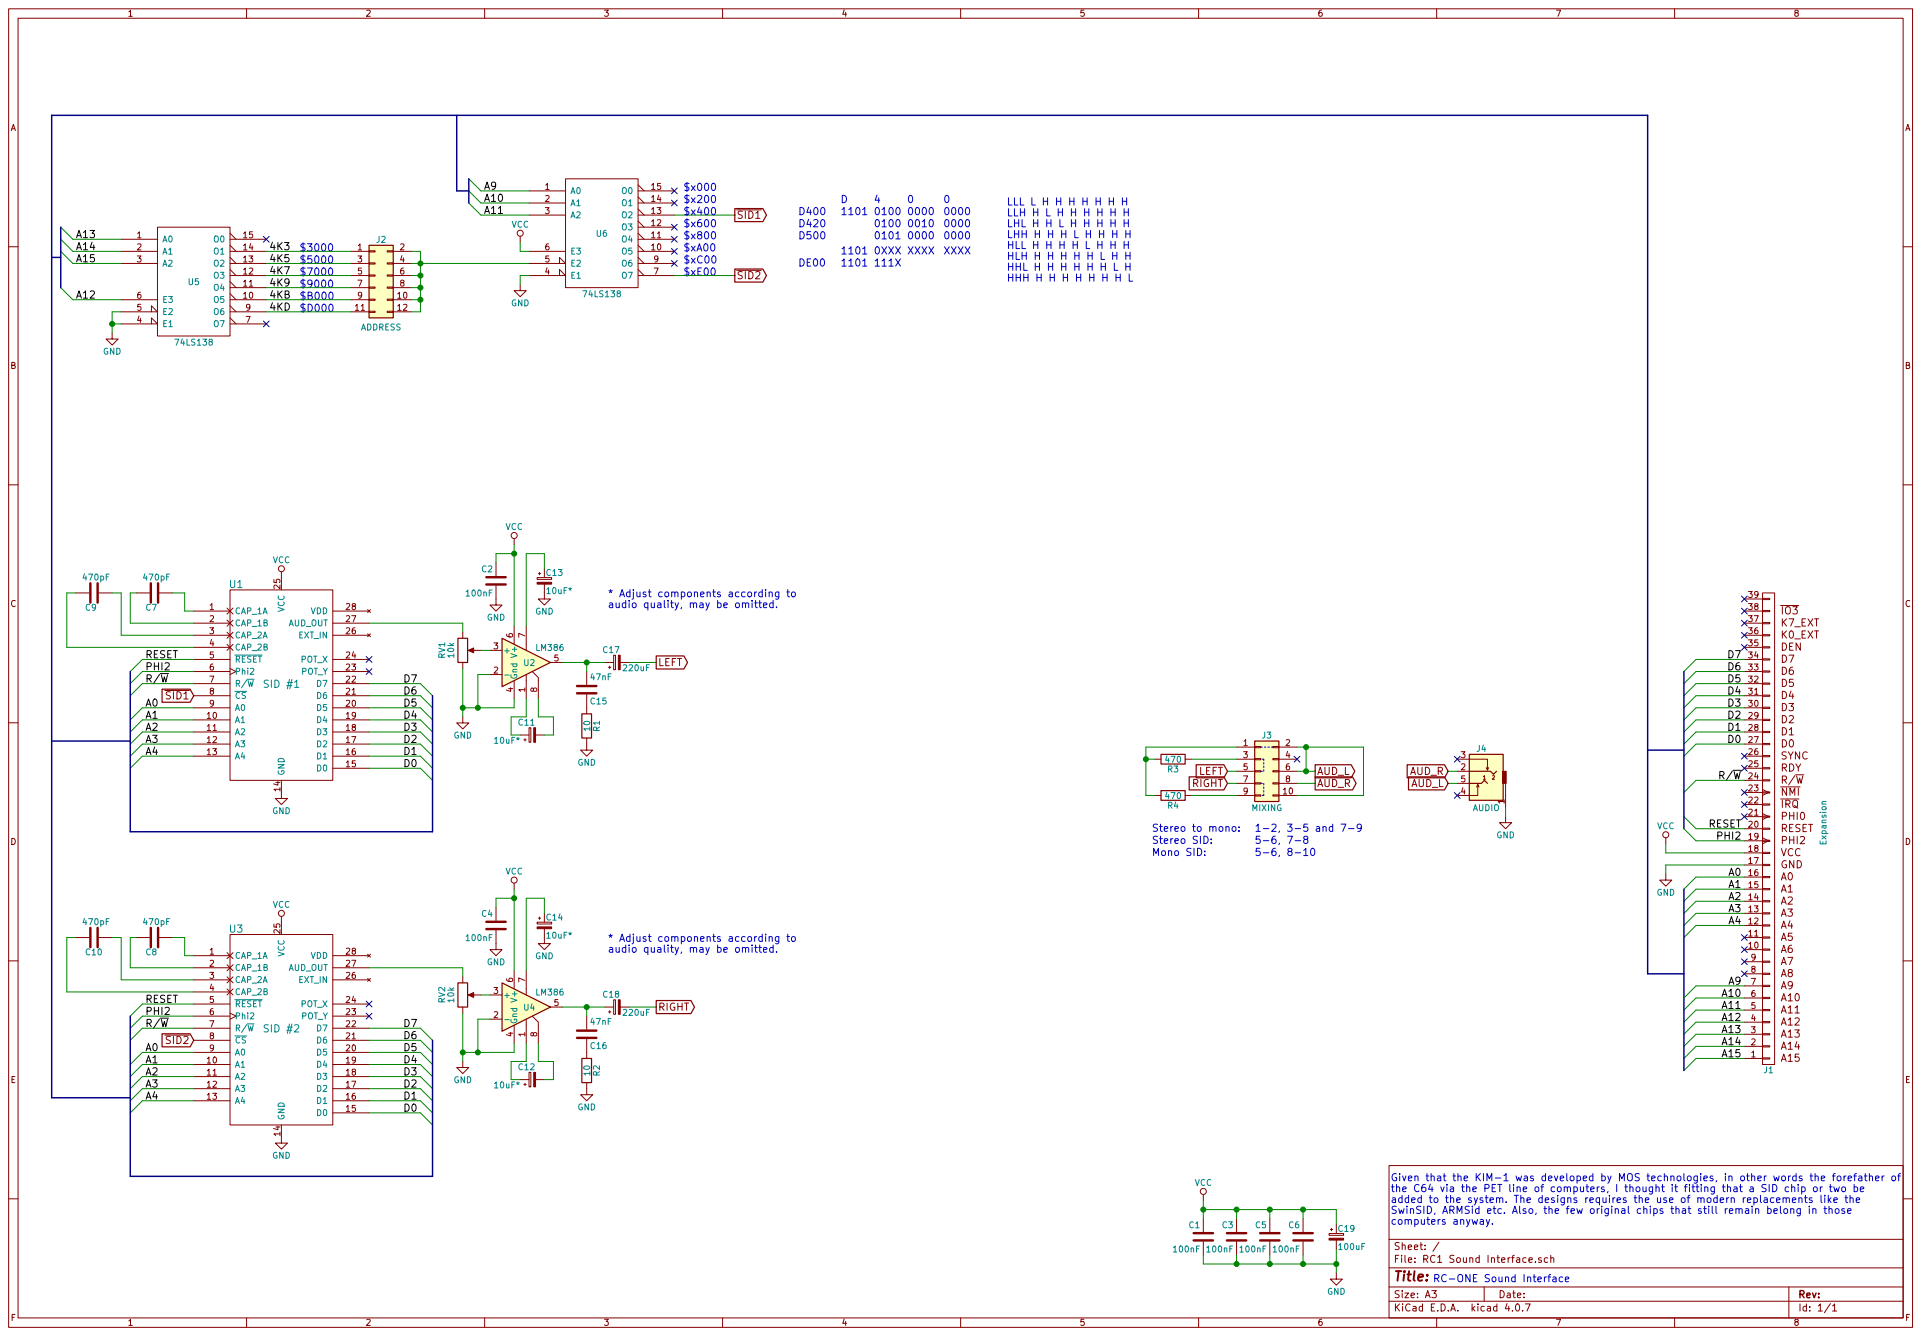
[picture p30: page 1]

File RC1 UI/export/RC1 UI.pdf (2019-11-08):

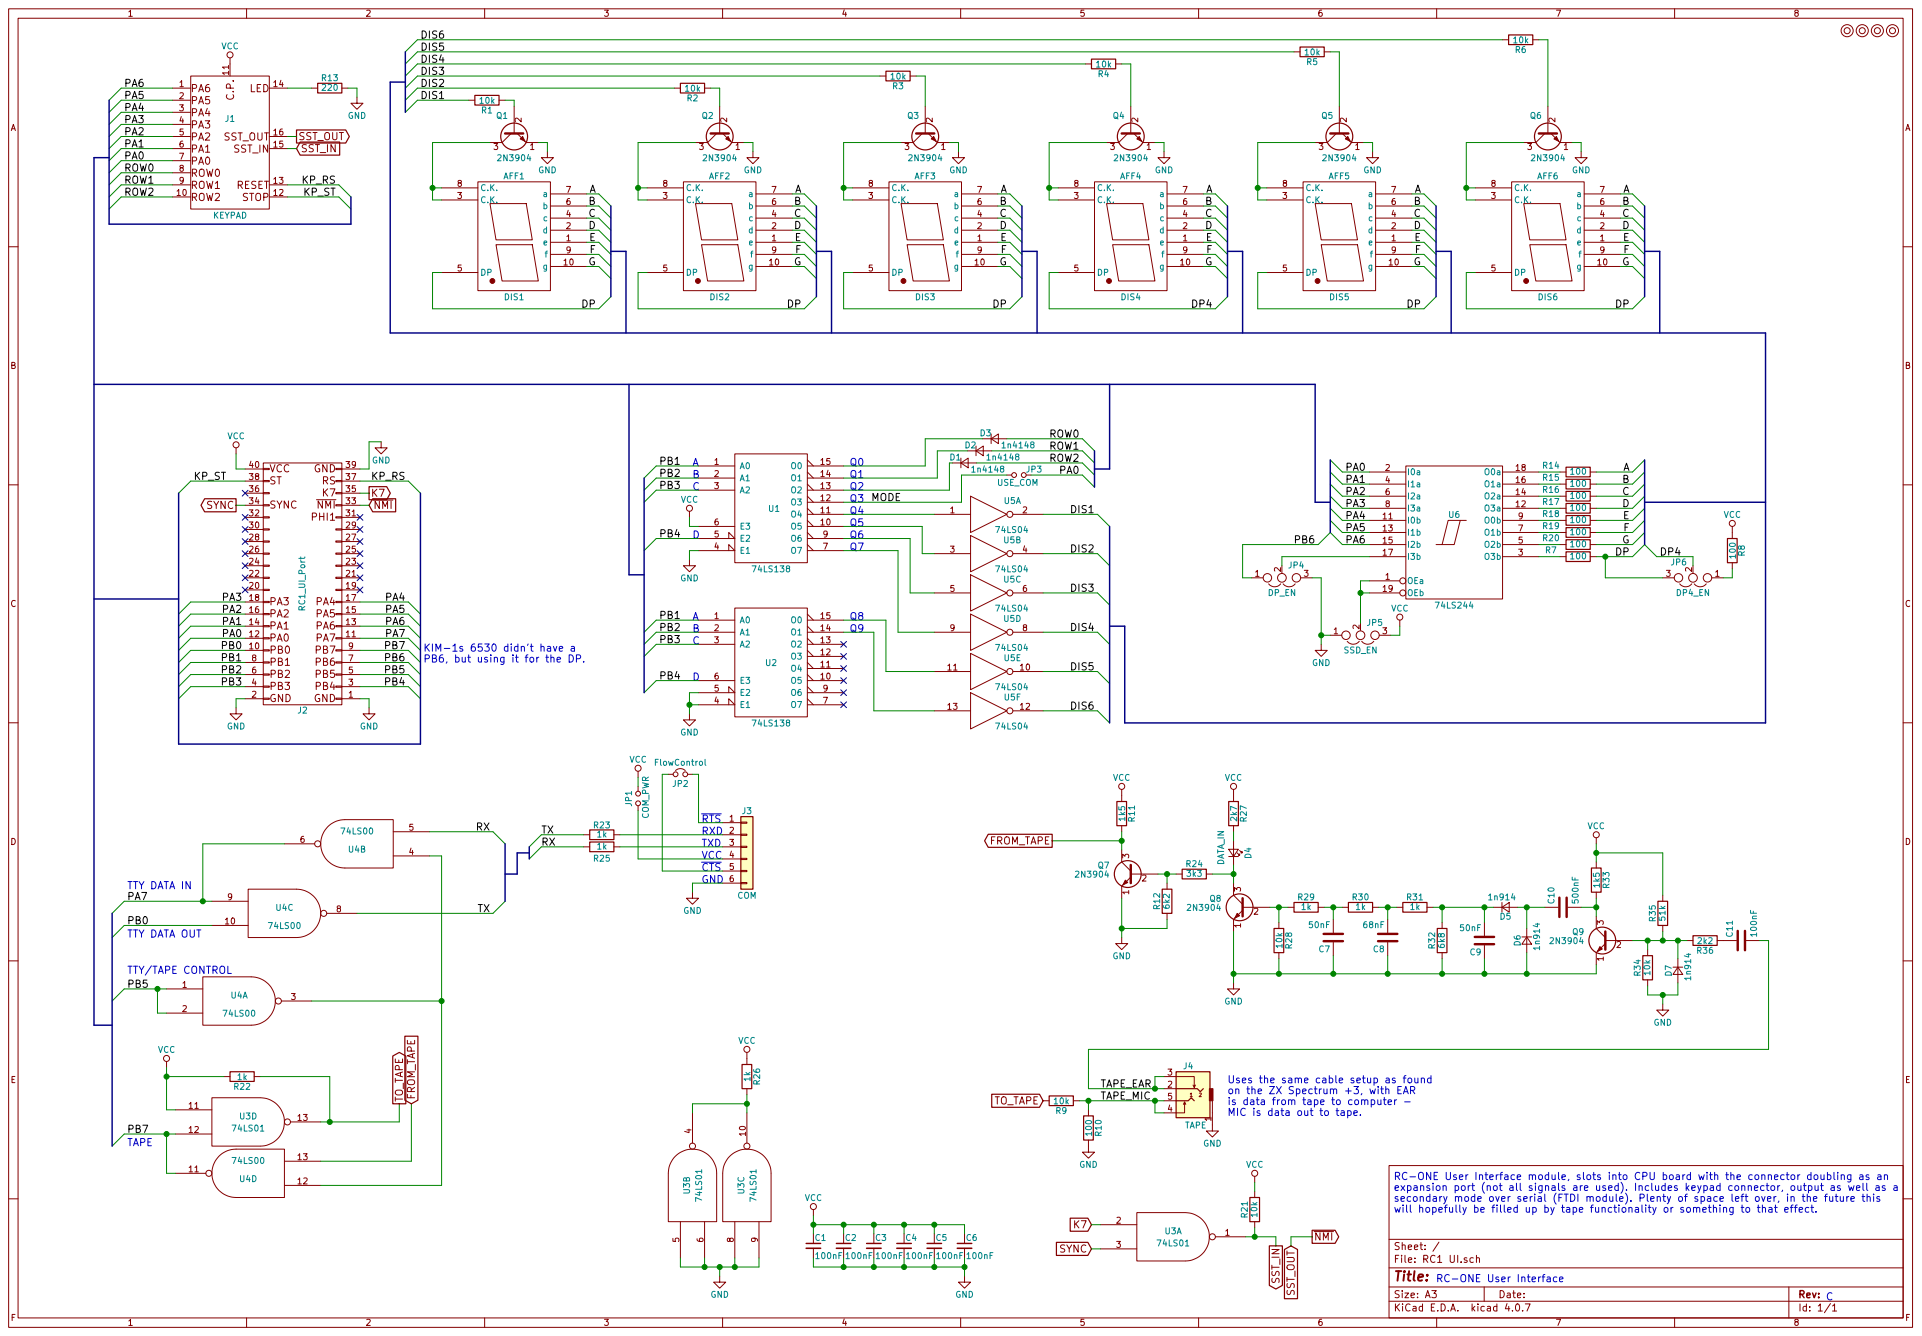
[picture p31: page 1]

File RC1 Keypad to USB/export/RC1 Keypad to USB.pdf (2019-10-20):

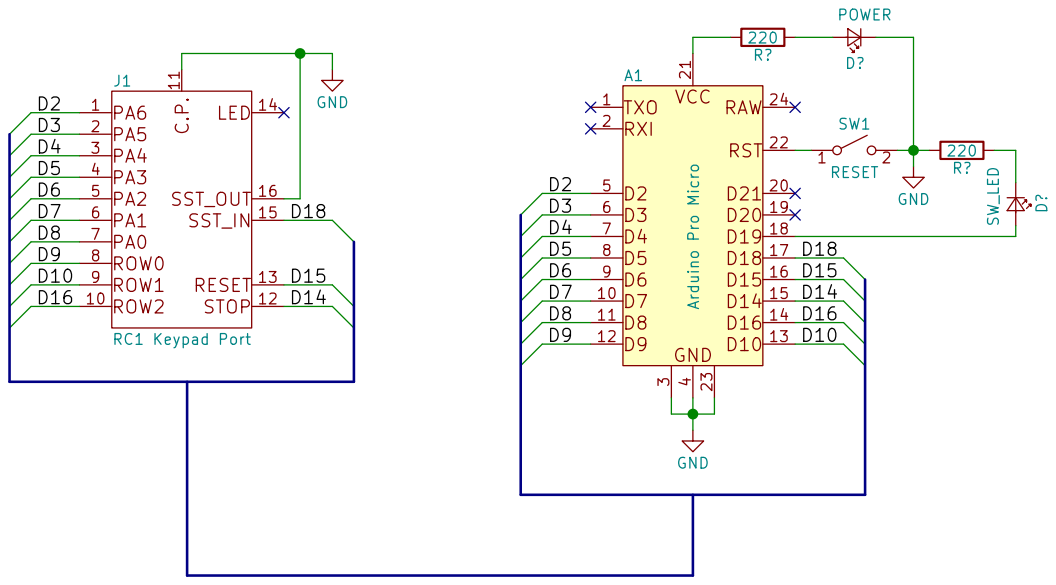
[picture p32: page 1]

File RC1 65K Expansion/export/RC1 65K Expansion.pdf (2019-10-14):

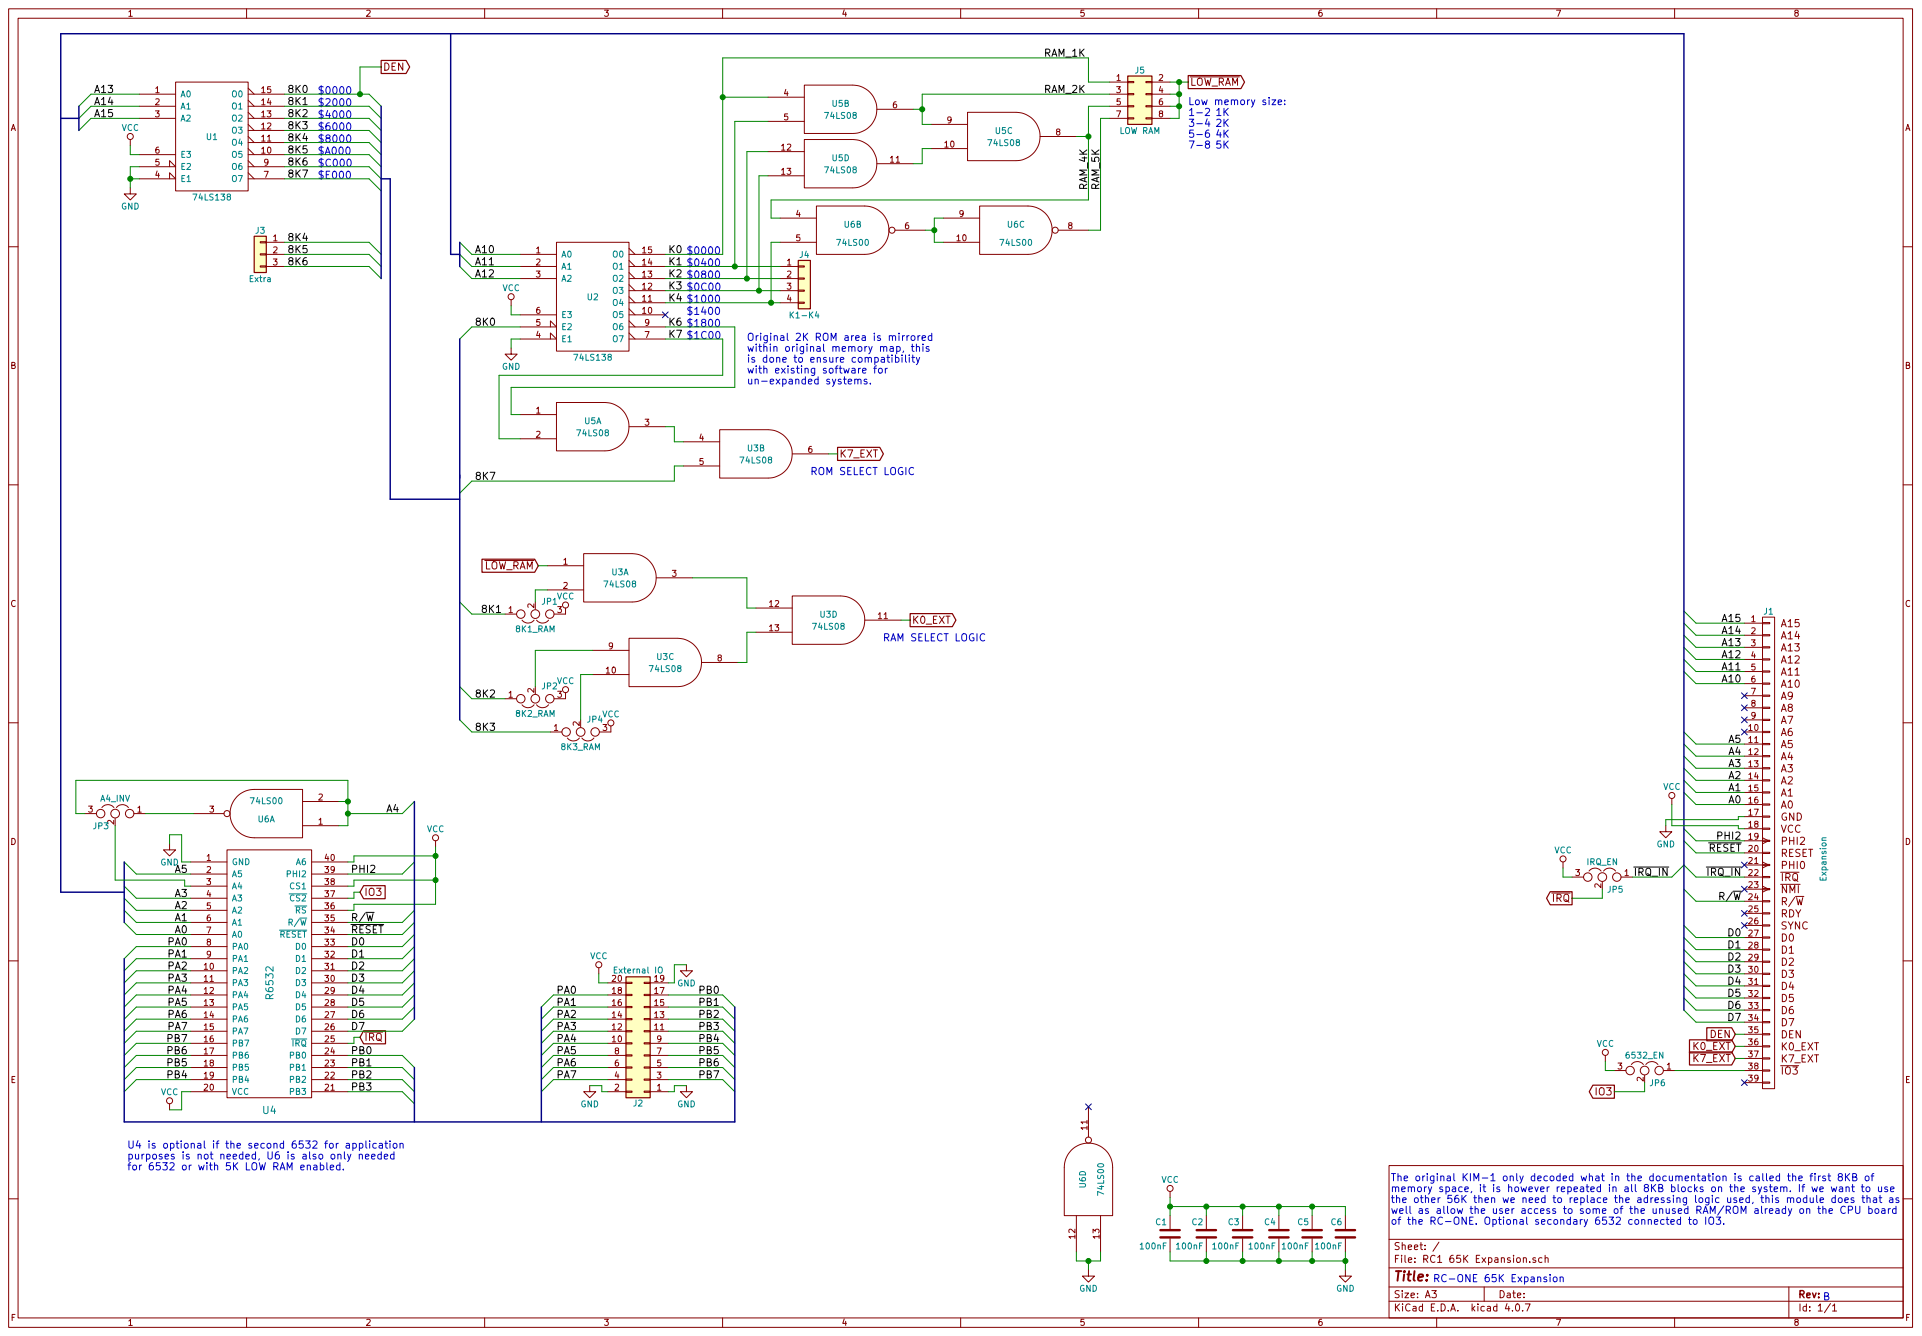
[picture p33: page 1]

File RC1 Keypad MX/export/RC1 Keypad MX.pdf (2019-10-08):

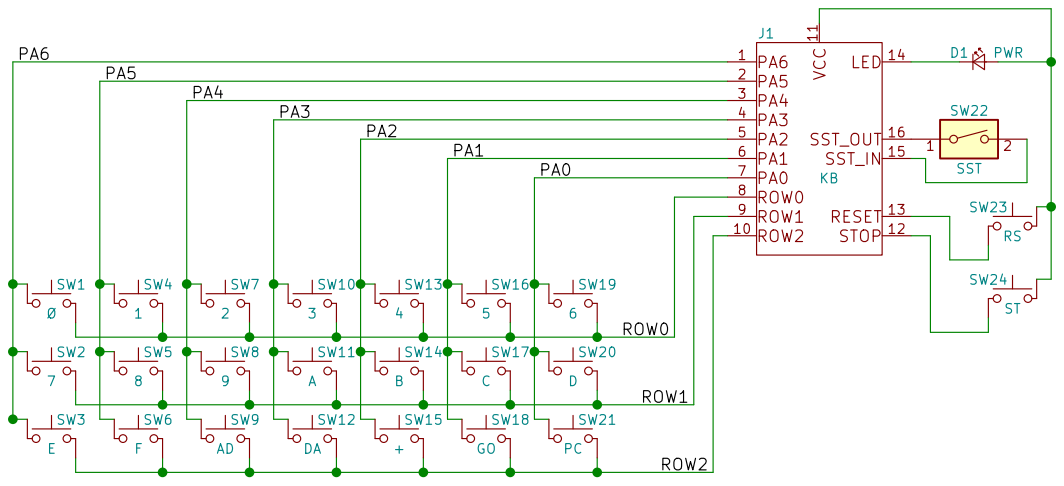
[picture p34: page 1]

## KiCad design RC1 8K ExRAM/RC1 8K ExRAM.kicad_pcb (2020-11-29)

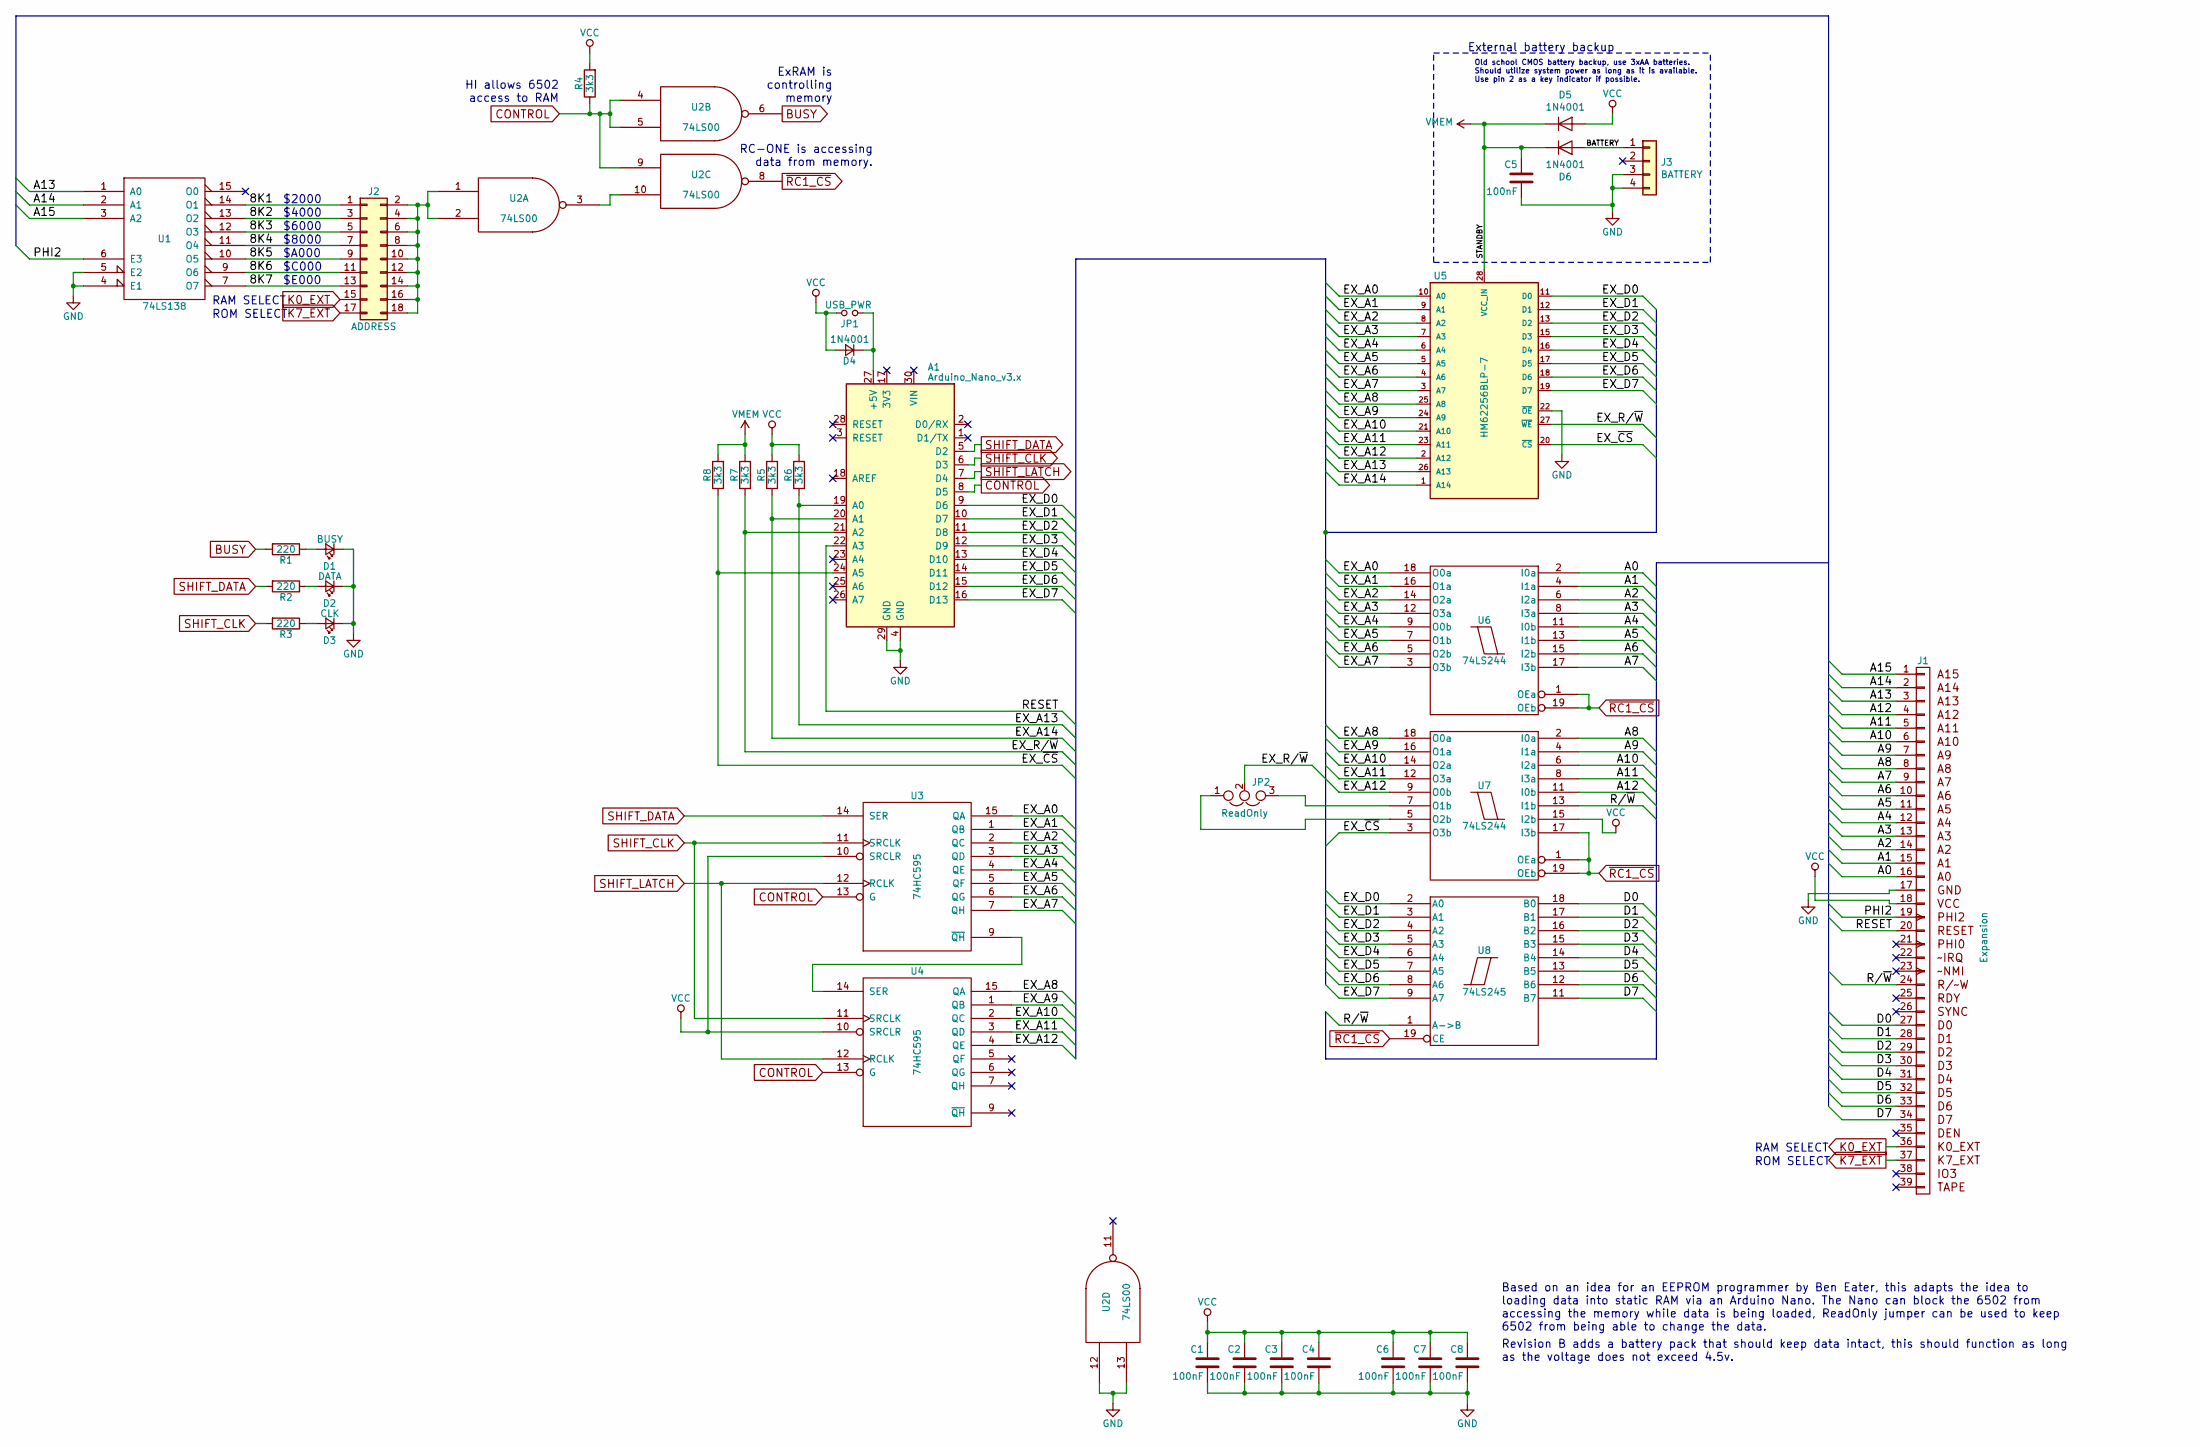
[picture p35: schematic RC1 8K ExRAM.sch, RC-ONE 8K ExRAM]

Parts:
A1: Arduino_Nano_v3.x; Arduino_Nano
C1, C2, C3, C4, C5, C6, C7, C8: 100nF; C_Disc_D4.7mm_W2.5mm_P5.00mm
D1: BUSY; LED_D5.0mm
D2: DATA; LED_D5.0mm
D3: CLK; LED_D5.0mm
D4: 1N4001; D_DO-35_SOD27_P7.62mm_Horizontal
D5, D6: 1N4001; D_DO-41_SOD81_P10.16mm_Horizontal
J1: Expansion; Pin_Header_Angled_1x39_Pitch2.54mm
J2: ADDRESS; Pin_Header_Straight_2x09_Pitch2.54mm
J3: BATTERY; Pin_Header_Angled_1x04_Pitch2.54mm
JP1: USB_PWR; Pin_Header_Straight_1x02_Pitch2.54mm
JP2: ReadOnly; Pin_Header_Straight_1x03_Pitch2.54mm
R1, R2, R3: 220; R_Axial_DIN0207_L6.3mm_D2.5mm_P10.16mm_Horizontal
R4, R5, R6, R7, R8: 3k3; R_Axial_DIN0207_L6.3mm_D2.5mm_P10.16mm_Horizontal
U1: 74LS138; DIP-16_W7.62mm_Socket
U2: 74LS00; DIP-14_W7.62mm_Socket
U3, U4: 74HC595; DIP-16_W7.62mm_Socket
U5: HM62256BLP-7; DIP-28_W15.24mm_Socket
U6, U7: 74LS244; DIP-20_W7.62mm_Socket
U8: 74LS245; DIP-20_W7.62mm_Socket

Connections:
/8K1: J2.1, U1.14 (O1)
/8K2: J2.3, U1.13 (O2)
/8K3: J2.5, U1.12 (O3)
/8K4: J2.7, U1.11 (O4)
/8K5: J2.9, U1.10 (O5)
/8K6: J2.11, U1.9 (O6)
/8K7: J2.13, U1.7 (O7)
/A0: J1.16 (A0), U6.2 (I0a)
/A1: J1.15 (A1), U6.4 (I1a)
/A2: J1.14 (A2), U6.6 (I2a)
/A3: J1.13 (A3), U6.8 (I3a)
/A4: J1.12 (A4), U6.11 (I0b)
/A5: J1.11 (A5), U6.13 (I1b)
/A6: J1.10 (A6), U6.15 (I2b)
/A7: J1.9 (A7), U6.17 (I3b)
/A8: J1.8 (A8), U7.2 (I0a)
/A9: J1.7 (A9), U7.4 (I1a)
/A10: J1.6 (A10), U7.6 (I2a)
/A11: J1.5 (A11), U7.8 (I3a)
/A12: J1.4 (A12), U7.11 (I0b)
/A13: J1.3 (A13), U1.1 (A0)
/A14: J1.2 (A14), U1.2 (A1)
/A15: J1.1 (A15), U1.3 (A2)
/BATTERY: D6.2 (A), J3.1
/D0: J1.27 (D0), U8.18 (B0)
/D1: J1.28 (D1), U8.17 (B1)
/D2: J1.29 (D2), U8.16 (B2)
/D3: J1.30 (D3), U8.15 (B3)
/D4: J1.31 (D4), U8.14 (B4)
/D5: J1.32 (D5), U8.13 (B5)
/D6: J1.33 (D6), U8.12 (B6)
/D7: J1.34 (D7), U8.11 (B7)
/EX_A0: U3.15 (QA), U5.10 (A0), U6.18 (O0a)
/EX_A1: U3.1 (QB), U5.9 (A1), U6.16 (O1a)
/EX_A2: U3.2 (QC), U5.8 (A2), U6.14 (O2a)
/EX_A3: U3.3 (QD), U5.7 (A3), U6.12 (O3a)
/EX_A4: U3.4 (QE), U5.6 (A4), U6.9 (O0b)
/EX_A5: U3.5 (QF), U5.5 (A5), U6.7 (O1b)
/EX_A6: U3.6 (QG), U5.4 (A6), U6.5 (O2b)
/EX_A7: U3.7 (QH), U5.3 (A7), U6.3 (O3b)
/EX_A8: U4.15 (QA), U5.25 (A8), U7.18 (O0a)
/EX_A9: U4.1 (QB), U5.24 (A9), U7.16 (O1a)
/EX_A10: U4.2 (QC), U5.21 (A10), U7.14 (O2a)
/EX_A11: U4.3 (QD), U5.23 (A11), U7.12 (O3a)
/EX_A12: U4.4 (QE), U5.2 (A12), U7.9 (O0b)
/EX_A13: A1.19 (A0), R6.1, U5.26 (A13)
/EX_A14: A1.20 (A1), R5.1, U5.1 (A14)
/EX_D0: A1.9 (D6), U5.11 (D0), U8.2 (A0)
/EX_D1: A1.10 (D7), U5.12 (D1), U8.3 (A1)
/EX_D2: A1.11 (D8), U5.13 (D2), U8.4 (A2)
/EX_D3: A1.12 (D9), U5.15 (D3), U8.5 (A3)
/EX_D4: A1.13 (D10), U5.16 (D4), U8.6 (A4)
/EX_D5: A1.14 (D11), U5.17 (D5), U8.7 (A5)
/EX_D6: A1.15 (D12), U5.18 (D6), U8.8 (A6)
/EX_D7: A1.16 (D13), U5.19 (D7), U8.9 (A7)
/EX_R/~W: A1.21 (A2), JP2.2, R7.1, U5.27 (~WE)
/EX_~CS: A1.24 (A5), R8.1, U5.20 (~CS), U7.3 (O3b)
/PHI2: J1.19 (PHI2), U1.6 (E3)
/R/~W: J1.24 (RW), U7.13 (I1b), U8.1 (A->B)
/RESET: A1.22 (A3), J1.20 (RESET)
BUSY: R1.2, U2.6
CONTROL: A1.8 (D5), R4.1, U2.4, U2.5, U2.9, U3.13 (G), U4.13 (G)
GND: A1.4 (GND), A1.29 (GND), C1.2, C2.2, C3.2, C4.2, C5.2, C6.2, C7.2, C8.2, D1.1 (K), D2.1 (K), D3.1 (K), J1.17, J3.3, J3.4, U1.4 (E1), U1.5 (E2), U1.8 (GND), U2.7 (GND), U2.12, U2.13, U3.8 (GND), U4.8 (GND), U5.14 (GND), U5.22 (~OE), U6.10 (GND), U7.10 (GND), U8.10 (GND)
K0_EXT: J1.36 (RX), J2.15
K7_EXT: J1.37 (NMI), J2.17
unnamed: A1.27 (+5V), D4.1 (K), JP1.1
unnamed: D1.2 (A), R1.1
unnamed: D2.2 (A), R2.1
unnamed: D3.2 (A), R3.1
unnamed: J2.2, J2.4, J2.6, J2.8, J2.10, J2.12, J2.14, J2.16, J2.18, U2.1, U2.2
unnamed: JP2.1, U7.5 (O2b)
unnamed: JP2.3, U7.7 (O1b)
unnamed: U2.3, U2.10
unnamed: U3.9 (~QH), U4.14 (SER)
SHIFT_CLK: A1.6 (D3), R3.2, U3.11 (SRCLK), U4.11 (SRCLK)
SHIFT_DATA: A1.5 (D2), R2.2, U3.14 (SER)
SHIFT_LATCH: A1.7 (D4), U3.12 (RCLK), U4.12 (RCLK)
VCC: C1.1, C2.1, C3.1, C4.1, C6.1, C7.1, C8.1, D4.2 (A), D5.2 (A), J1.18, JP1.2, R4.2, R5.2, R6.2, U1.16 (VCC), U2.14 (VCC), U3.10 (SRCLR), U3.16 (VCC), U4.10 (SRCLR), U4.16 (VCC), U6.20 (VCC), U7.15 (I2b), U7.20 (VCC), U8.20 (VCC)
VMEM: C5.1, D5.1 (K), D6.1 (K), R7.2, R8.2, U5.28 (VCC_IN)
~RC1_CS: U2.8, U6.1 (OEa), U6.19 (OEb), U7.1 (OEa), U7.17 (I3b), U7.19 (OEb), U8.19 (CE)

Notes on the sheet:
$E000
$2000
$4000
$6000
$8000
$A000
$C000
RAM SELECT
ROM SELECT
HI allows 6502 access to RAM
RC-ONE is accessing data from memory.
Based on an idea for an EEPROM programmer by Ben Eater, this adapts the idea to loading data into static RAM via an Arduino Nano. The Nano can block the 6502 from accessing the memory while data is being loaded, ReadOnly jumper can be used to keep 6502 from being able to change the data.
ExRAM is controlling memory
External battery backup
Old school CMOS battery backup, use 3xAA batteries. Should utilize system power as long as it is available. Use pin 2 as a key indicator if possible.
Revision B adds a battery pack that should keep data intact, this should function as long as the voltage does not exceed 4.5v.

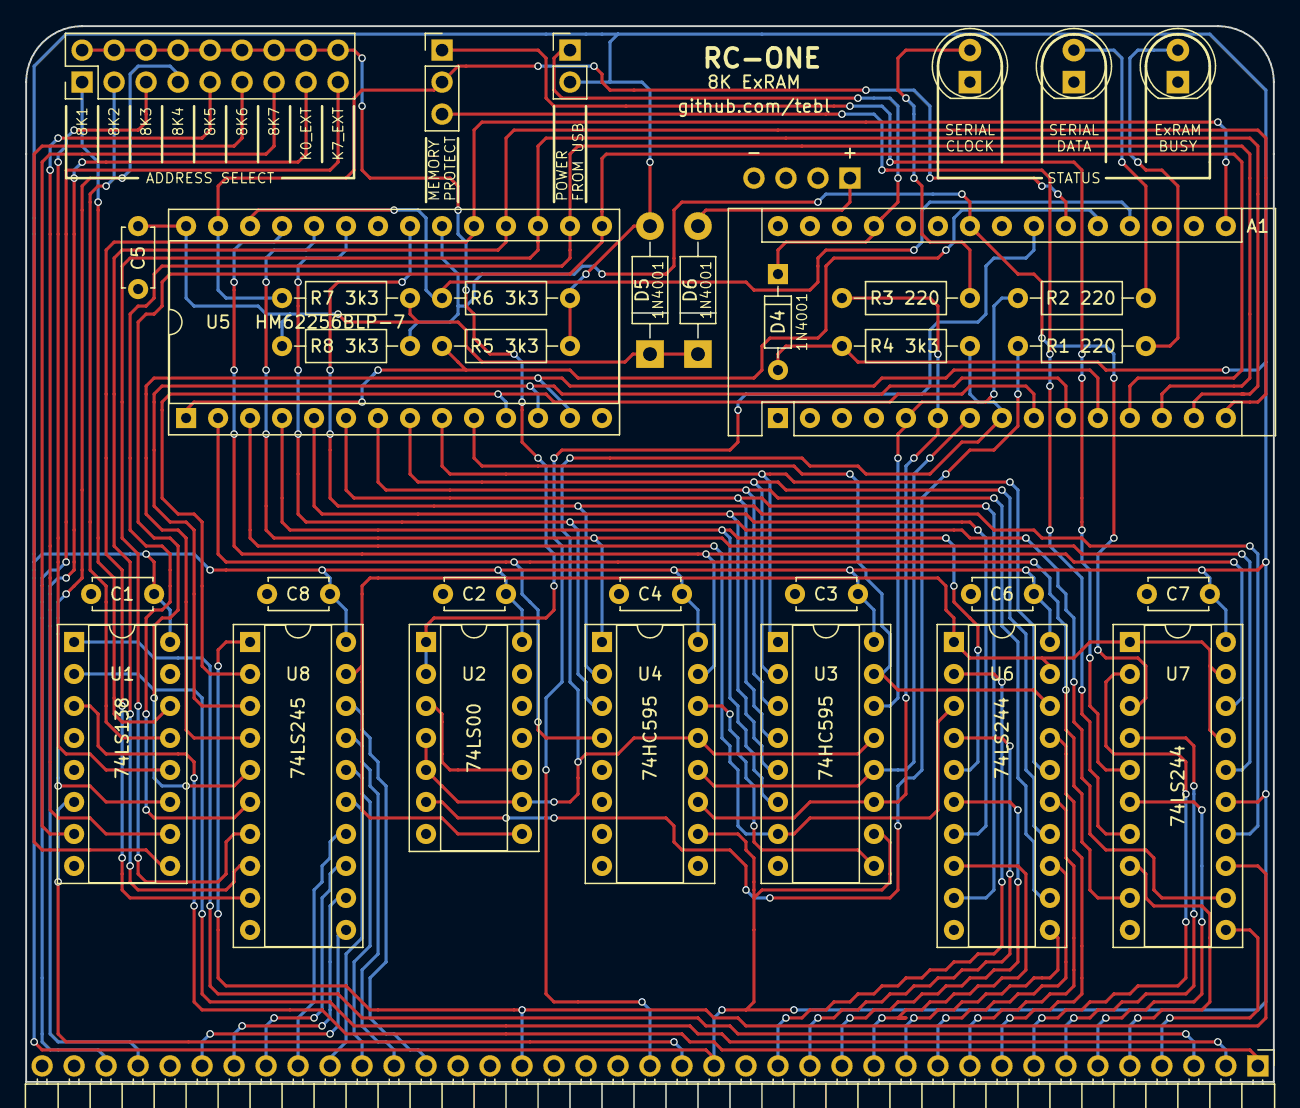
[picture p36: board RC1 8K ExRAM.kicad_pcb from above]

Board: 2 copper layers, 99.1 x 83.8 mm, 36 parts (1 on the bottom side), 80 nets.

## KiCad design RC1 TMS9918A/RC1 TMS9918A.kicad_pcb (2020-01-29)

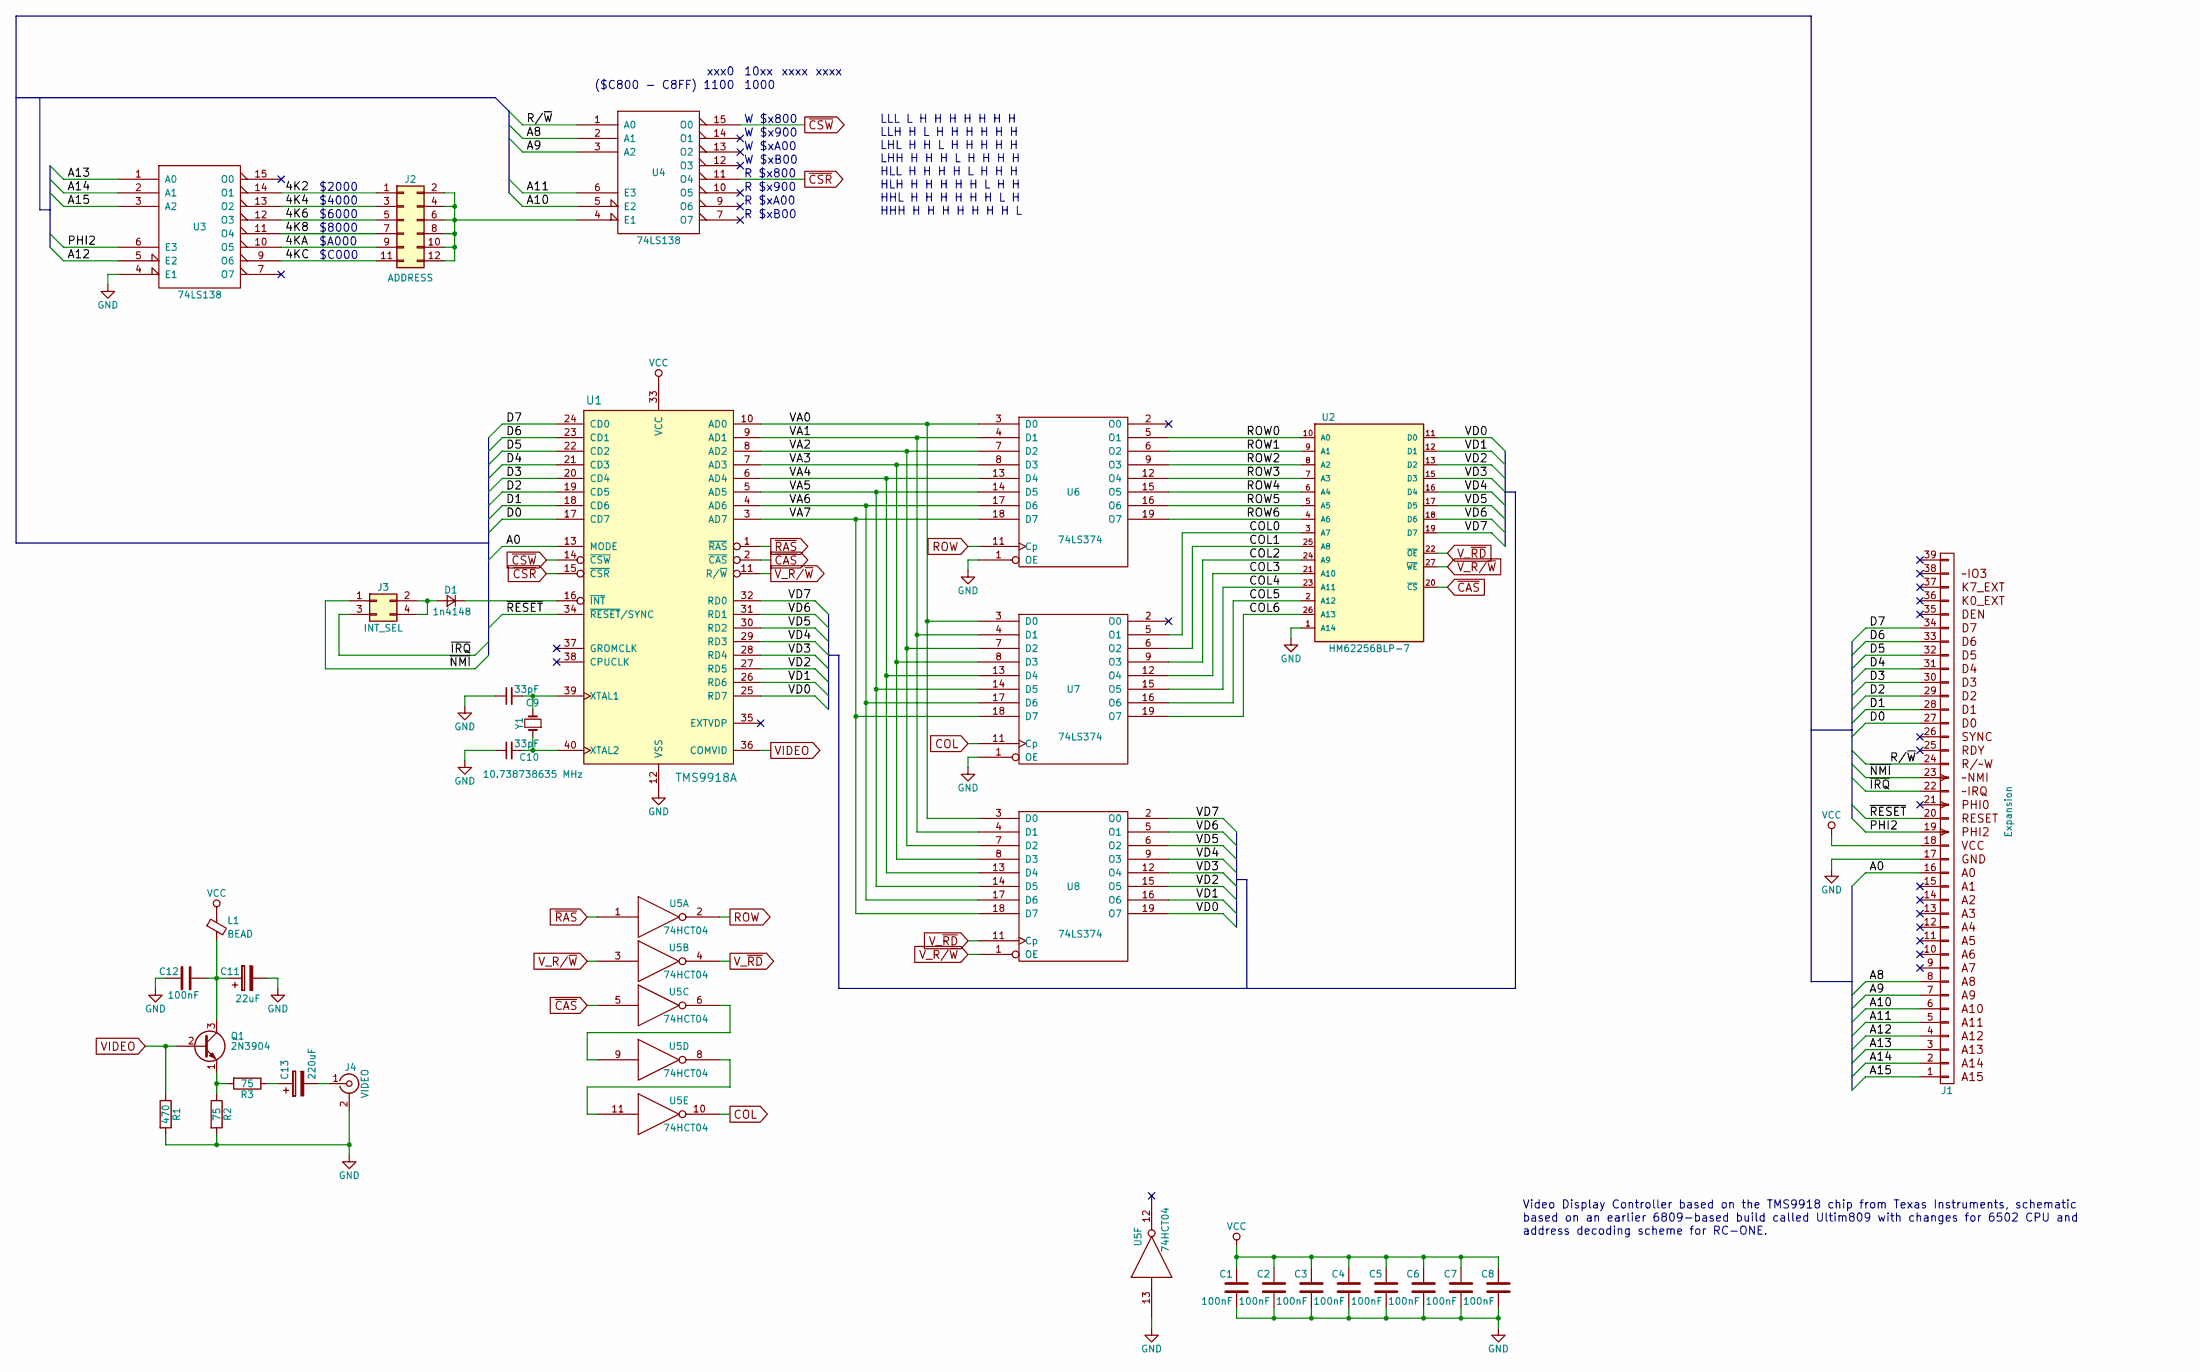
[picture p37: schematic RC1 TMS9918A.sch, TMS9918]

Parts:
C1, C2, C3, C4, C5, C6, C7, C8, C12: 100nF; C_Disc_D4.7mm_W2.5mm_P5.00mm
C9, C10: 33pF; C_Disc_D4.7mm_W2.5mm_P5.00mm
C11: 22uF; CP_Radial_D5.0mm_P2.50mm
C13: 220uF; CP_Radial_D5.0mm_P2.50mm
D1: 1n4148; D_DO-35_SOD27_P7.62mm_Horizontal
J1: Expansion; Pin_Header_Angled_1x39_Pitch2.54mm
J2: ADDRESS; Pin_Header_Straight_2x06_Pitch2.54mm
J3: INT_SEL; Pin_Header_Straight_2x02_Pitch2.54mm
J4: VIDEO; CUI_RCJ-013
L1: BEAD; L_Axial_L7.0mm_D3.3mm_P10.16mm_Horizontal_Fastron_MICC
Q1: 2N3904; TO-92_Molded_Narrow
R1: 470; R_Axial_DIN0207_L6.3mm_D2.5mm_P10.16mm_Horizontal
R2, R3: 75; R_Axial_DIN0207_L6.3mm_D2.5mm_P10.16mm_Horizontal
U1: TMS9918A; DIP-40_W15.24mm_Socket_LongPads
U2: HM62256BLP-7; DIP-28_W15.24mm_Socket_LongPads
U3, U4: 74LS138; DIP-16_W7.62mm_Socket
U5: 74HCT04; DIP-14_W7.62mm_Socket
U6, U7, U8: 74LS374; DIP-20_W7.62mm_Socket
Y1: 10.738738635 MHz; Crystal_HC49-4H_Vertical

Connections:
/4K2: J2.1, U3.14 (O1)
/4K4: J2.3, U3.13 (O2)
/4K6: J2.5, U3.12 (O3)
/4K8: J2.7, U3.11 (O4)
/4KA: J2.9, U3.10 (O5)
/4KC: J2.11, U3.9 (O6)
/A0: J1.16 (A0), U1.13 (MODE)
/A8: J1.8 (A8), U4.2 (A1)
/A9: J1.7 (A9), U4.3 (A2)
/A10: J1.6 (A10), U4.5 (E2)
/A11: J1.5 (A11), U4.6 (E3)
/A12: J1.4 (A12), U3.5 (E2)
/A13: J1.3 (A13), U3.1 (A0)
/A14: J1.2 (A14), U3.2 (A1)
/A15: J1.1 (A15), U3.3 (A2)
/COL0: U2.3 (A7), U7.5 (O1)
/COL1: U2.25 (A8), U7.6 (O2)
/COL2: U2.24 (A9), U7.9 (O3)
/COL3: U2.21 (A10), U7.12 (O4)
/COL4: U2.23 (A11), U7.15 (O5)
/COL5: U2.2 (A12), U7.16 (O6)
/COL6: U2.26 (A13), U7.19 (O7)
/D0: J1.27 (D0), U1.17 (CD7)
/D1: J1.28 (D1), U1.18 (CD6)
/D2: J1.29 (D2), U1.19 (CD5)
/D3: J1.30 (D3), U1.20 (CD4)
/D4: J1.31 (D4), U1.21 (CD3)
/D5: J1.32 (D5), U1.22 (CD2)
/D6: J1.33 (D6), U1.23 (CD1)
/D7: J1.34 (D7), U1.24 (CD0)
/PHI2: J1.19 (PHI2), U3.6 (E3)
/R/~W: J1.24 (RW), U4.1 (A0)
/ROW0: U2.10 (A0), U6.5 (O1)
/ROW1: U2.9 (A1), U6.6 (O2)
/ROW2: U2.8 (A2), U6.9 (O3)
/ROW3: U2.7 (A3), U6.12 (O4)
/ROW4: U2.6 (A4), U6.15 (O5)
/ROW5: U2.5 (A5), U6.16 (O6)
/ROW6: U2.4 (A6), U6.19 (O7)
/VA0: U1.10 (AD0), U6.3 (D0), U7.3 (D0), U8.3 (D0)
/VA1: U1.9 (AD1), U6.4 (D1), U7.4 (D1), U8.4 (D1)
/VA2: U1.8 (AD2), U6.7 (D2), U7.7 (D2), U8.7 (D2)
/VA3: U1.7 (AD3), U6.8 (D3), U7.8 (D3), U8.8 (D3)
/VA4: U1.6 (AD4), U6.13 (D4), U7.13 (D4), U8.13 (D4)
/VA5: U1.5 (AD5), U6.14 (D5), U7.14 (D5), U8.14 (D5)
/VA6: U1.4 (AD6), U6.17 (D6), U7.17 (D6), U8.17 (D6)
/VA7: U1.3 (AD7), U6.18 (D7), U7.18 (D7), U8.18 (D7)
/VD0: U1.25 (RD7), U2.11 (D0), U8.19 (O7)
/VD1: U1.26 (RD6), U2.12 (D1), U8.16 (O6)
/VD2: U1.27 (RD5), U2.13 (D2), U8.15 (O5)
/VD3: U1.28 (RD4), U2.15 (D3), U8.12 (O4)
/VD4: U1.29 (RD3), U2.16 (D4), U8.9 (O3)
/VD5: U1.30 (RD2), U2.17 (D5), U8.6 (O2)
/VD6: U1.31 (RD1), U2.18 (D6), U8.5 (O1)
/VD7: U1.32 (RD0), U2.19 (D7), U8.2 (O0)
/~IRQ: J1.22 (IRQ), J3.3
/~NMI: J1.23 (PHI1), J3.1
/~RESET: J1.20 (RESET), U1.34 (~RESET~/SYNC)
COL: U5.10, U7.11 (Cp)
GND: C1.2, C2.2, C3.2, C4.2, C5.2, C6.2, C7.2, C8.2, C9.1, C10.1, C11.2, C12.1, J1.17, J4.2 (Ext), R1.2, R2.2, U1.12 (VSS), U2.1 (A14), U2.14 (GND), U3.4 (E1), U3.8 (GND), U4.8 (GND), U5.7 (GND), U5.13, U6.1 (OE), U6.10 (GND), U7.1 (OE), U7.10 (GND), U8.10 (GND)
unnamed: C9.2, U1.39 (XTAL1), Y1.2
unnamed: C10.2, U1.40 (XTAL2), Y1.1
unnamed: C11.1, C12.2, L1.2, Q1.3 (C)
unnamed: C13.1, R3.1
unnamed: C13.2, J4.1 (In)
unnamed: D1.1 (K), U1.16 (~INT~)
unnamed: D1.2 (A), J3.2, J3.4
unnamed: J2.2, J2.4, J2.6, J2.8, J2.10, J2.12, U4.4 (E1)
unnamed: Q1.1 (E), R2.1, R3.2
unnamed: U5.6, U5.9
unnamed: U5.8, U5.11
ROW: U5.2, U6.11 (Cp)
VCC: C1.1, C2.1, C3.1, C4.1, C5.1, C6.1, C7.1, C8.1, J1.18, L1.1, U1.33 (VCC), U2.28 (VCC), U3.16 (VCC), U4.16 (VCC), U5.14 (VCC), U6.20 (VCC), U7.20 (VCC), U8.20 (VCC)
VIDEO: Q1.2 (B), R1.1, U1.36 (COMVID)
V_R/~W: U1.11 (R/~W~), U2.27 (~WE), U5.3, U8.1 (OE)
V_~RD: U2.22 (~OE), U5.4, U8.11 (Cp)
~CAS: U1.2 (~CAS~), U2.20 (~CS), U5.5
~CSR: U1.15 (~CSR~), U4.11 (O4)
~CSW: U1.14 (~CSW~), U4.15 (O0)
~RAS: U1.1 (~RAS~), U5.1

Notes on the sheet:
$2000
$4000
$6000
$8000
$A000
$C000
W $x800
LLL L H H H H H H H LLH H L H H H H H H LHL H H L H H H H H LHH H H H L H H H H HLL H H H H L H H H HLH H H H H H L H H HHL H H H H H H L H HHH H H H H H H H L
xxx0
10xx
xxxx
W $x900
W $xA00
W $xB00
R $x800
R $x900
R $xA00
R $xB00
1100
1000
($C800 - C8FF)
Video Display Controller based on the TMS9918 chip from Texas Instruments, schematic based on an earlier 6809-based build called Ultim809 with changes for 6502 CPU and address decoding scheme for RC-ONE.

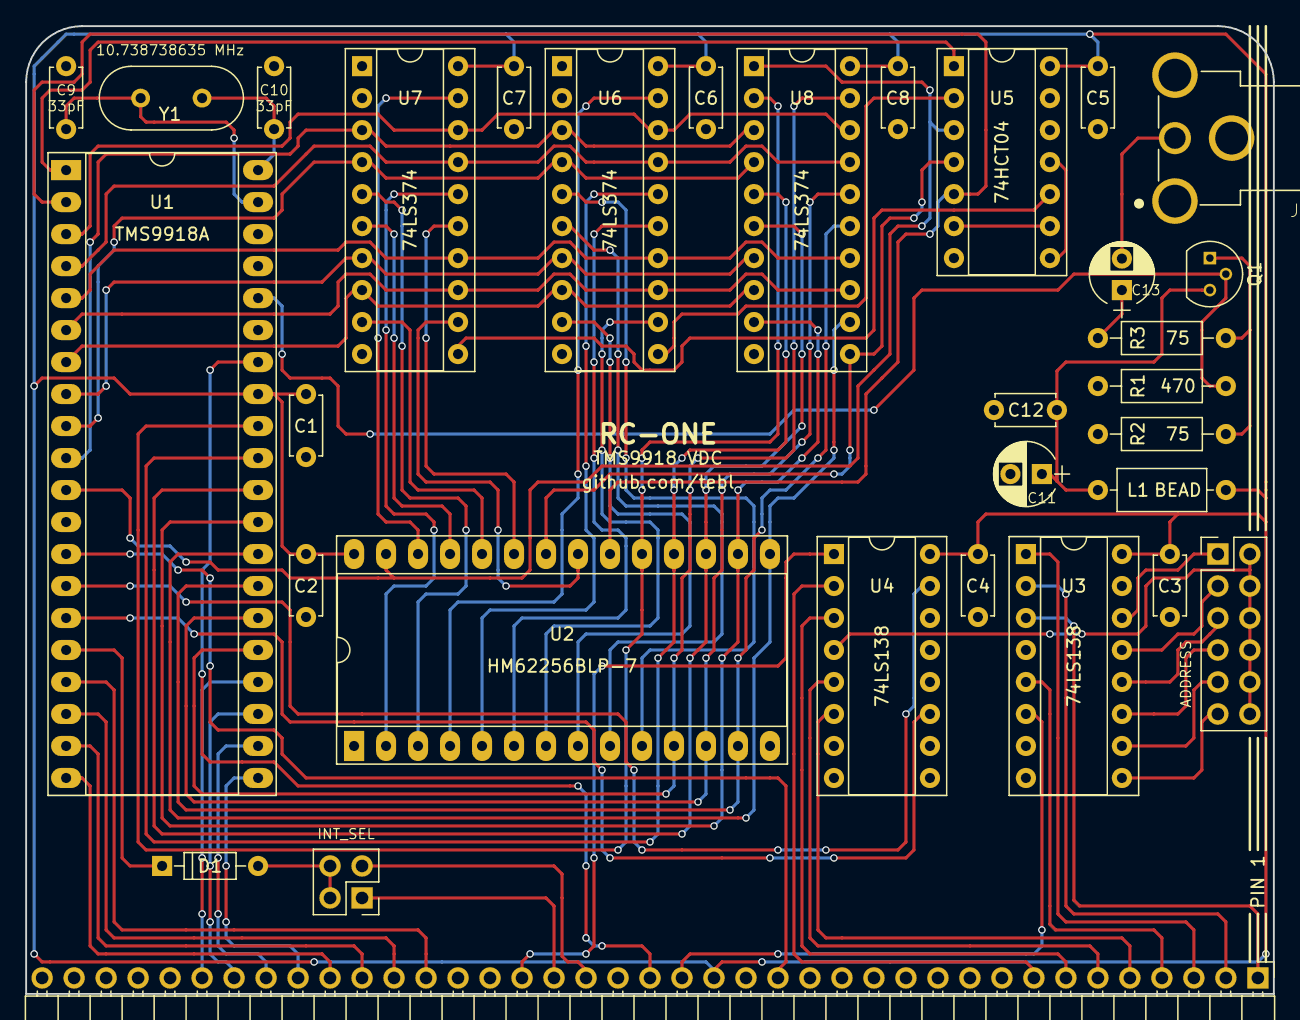
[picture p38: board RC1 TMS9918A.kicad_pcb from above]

Board: 2 copper layers, 99.1 x 76.8 mm, 32 parts (0 on the bottom side), 80 nets.

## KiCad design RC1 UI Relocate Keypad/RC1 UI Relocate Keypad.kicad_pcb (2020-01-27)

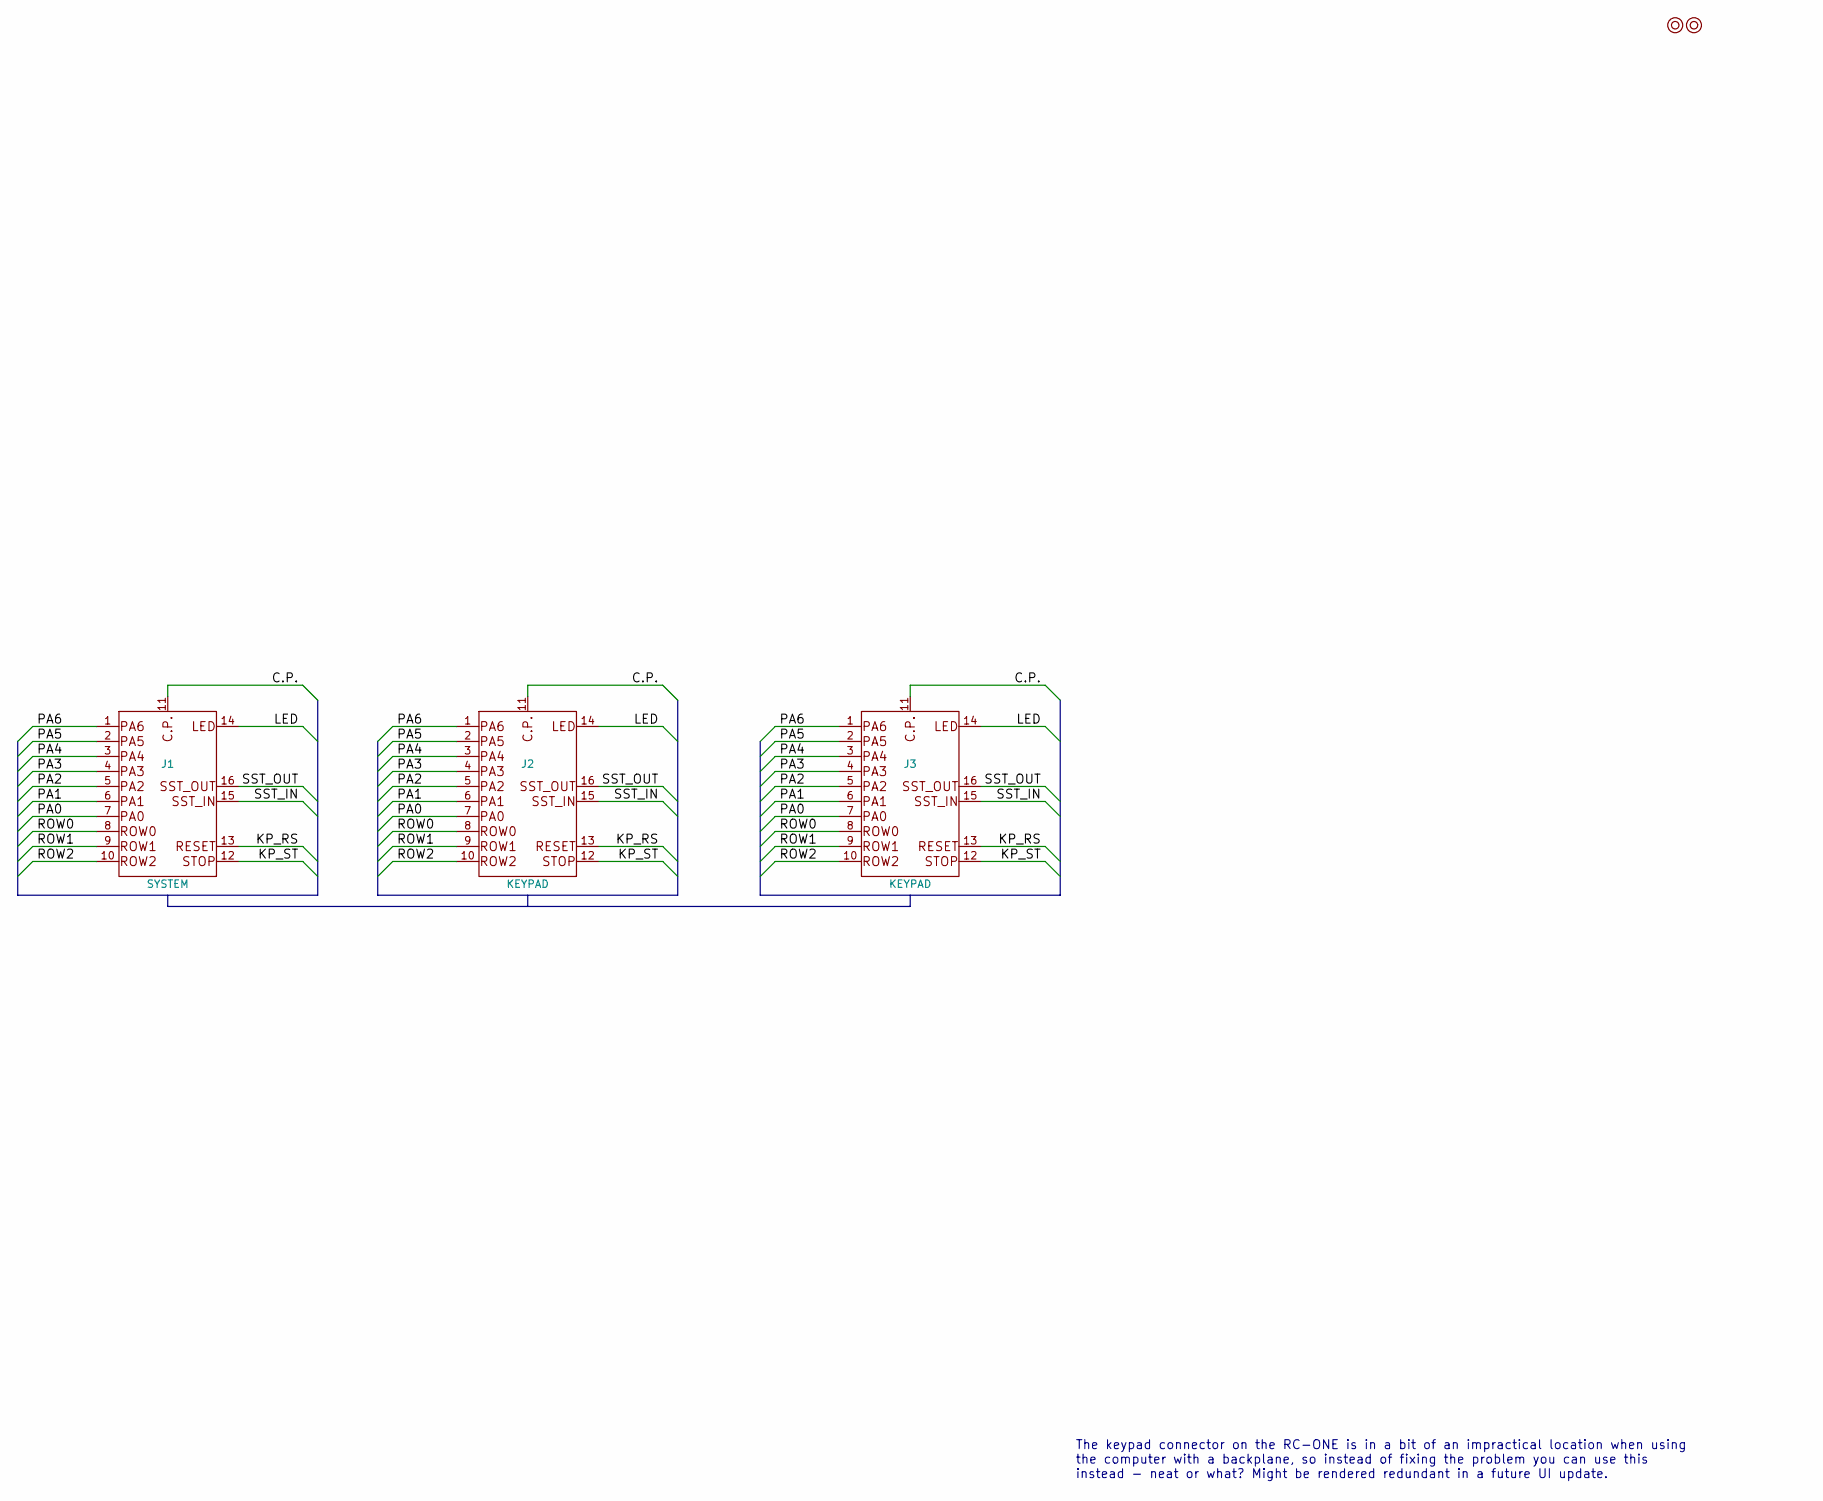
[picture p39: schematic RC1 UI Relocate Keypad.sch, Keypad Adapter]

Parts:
J1: SYSTEM; Pin_Header_Straight_2x08_Pitch2.54mm
J2, J3: KEYPAD; Pin_Header_Straight_2x08_Pitch2.54mm
M1, M4: Mounting; 1pin

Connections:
/C.P.: J1.11, J2.11, J3.11
/KP_RS: J1.13, J2.13, J3.13
/KP_ST: J1.12, J2.12, J3.12
/LED: J1.14, J2.14, J3.14
/PA0: J1.7, J2.7, J3.7
/PA1: J1.6, J2.6, J3.6
/PA2: J1.5, J2.5, J3.5
/PA3: J1.4, J2.4, J3.4
/PA4: J1.3, J2.3, J3.3
/PA5: J1.2, J2.2, J3.2
/PA6: J1.1, J2.1, J3.1
/ROW0: J1.8, J2.8, J3.8
/ROW1: J1.9, J2.9, J3.9
/ROW2: J1.10, J2.10, J3.10
/SST_IN: J1.15, J2.15, J3.15
/SST_OUT: J1.16, J2.16, J3.16

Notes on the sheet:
The keypad connector on the RC-ONE is in a bit of an impractical location when using the computer with a backplane, so instead of fixing the problem you can use this instead - neat or what? Might be rendered redundant in a future UI update.

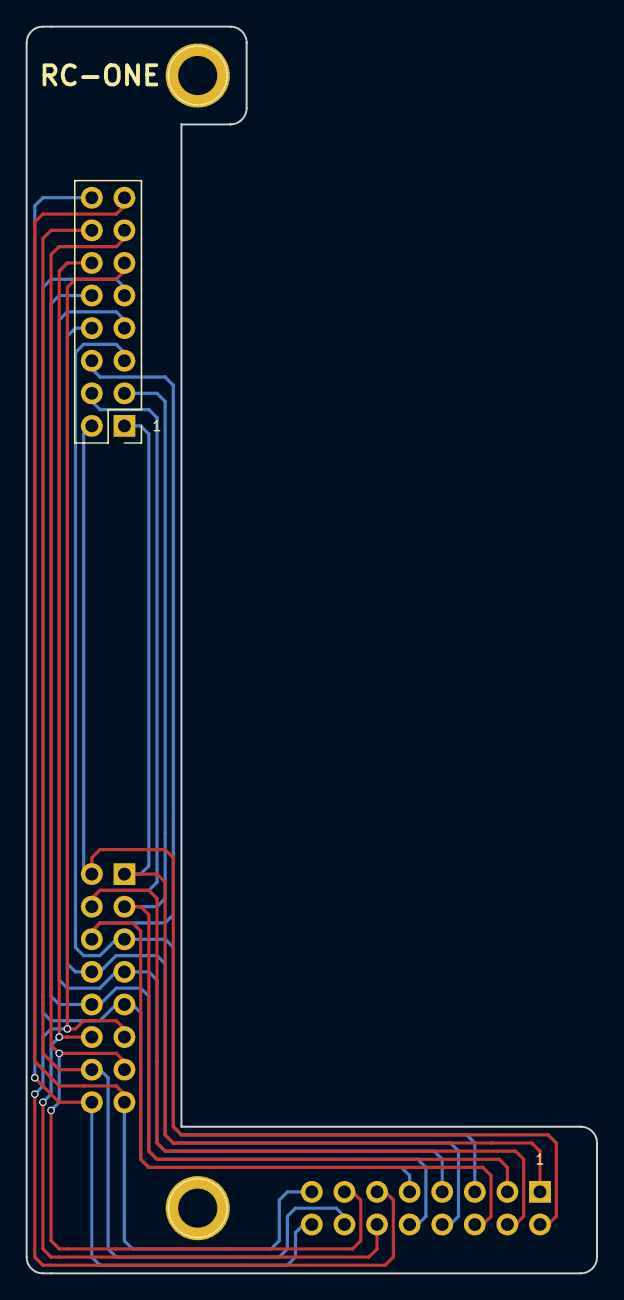
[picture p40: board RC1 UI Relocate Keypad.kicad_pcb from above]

Board: 2 copper layers, 44.5 x 97.2 mm, 5 parts (1 on the bottom side), 16 nets.

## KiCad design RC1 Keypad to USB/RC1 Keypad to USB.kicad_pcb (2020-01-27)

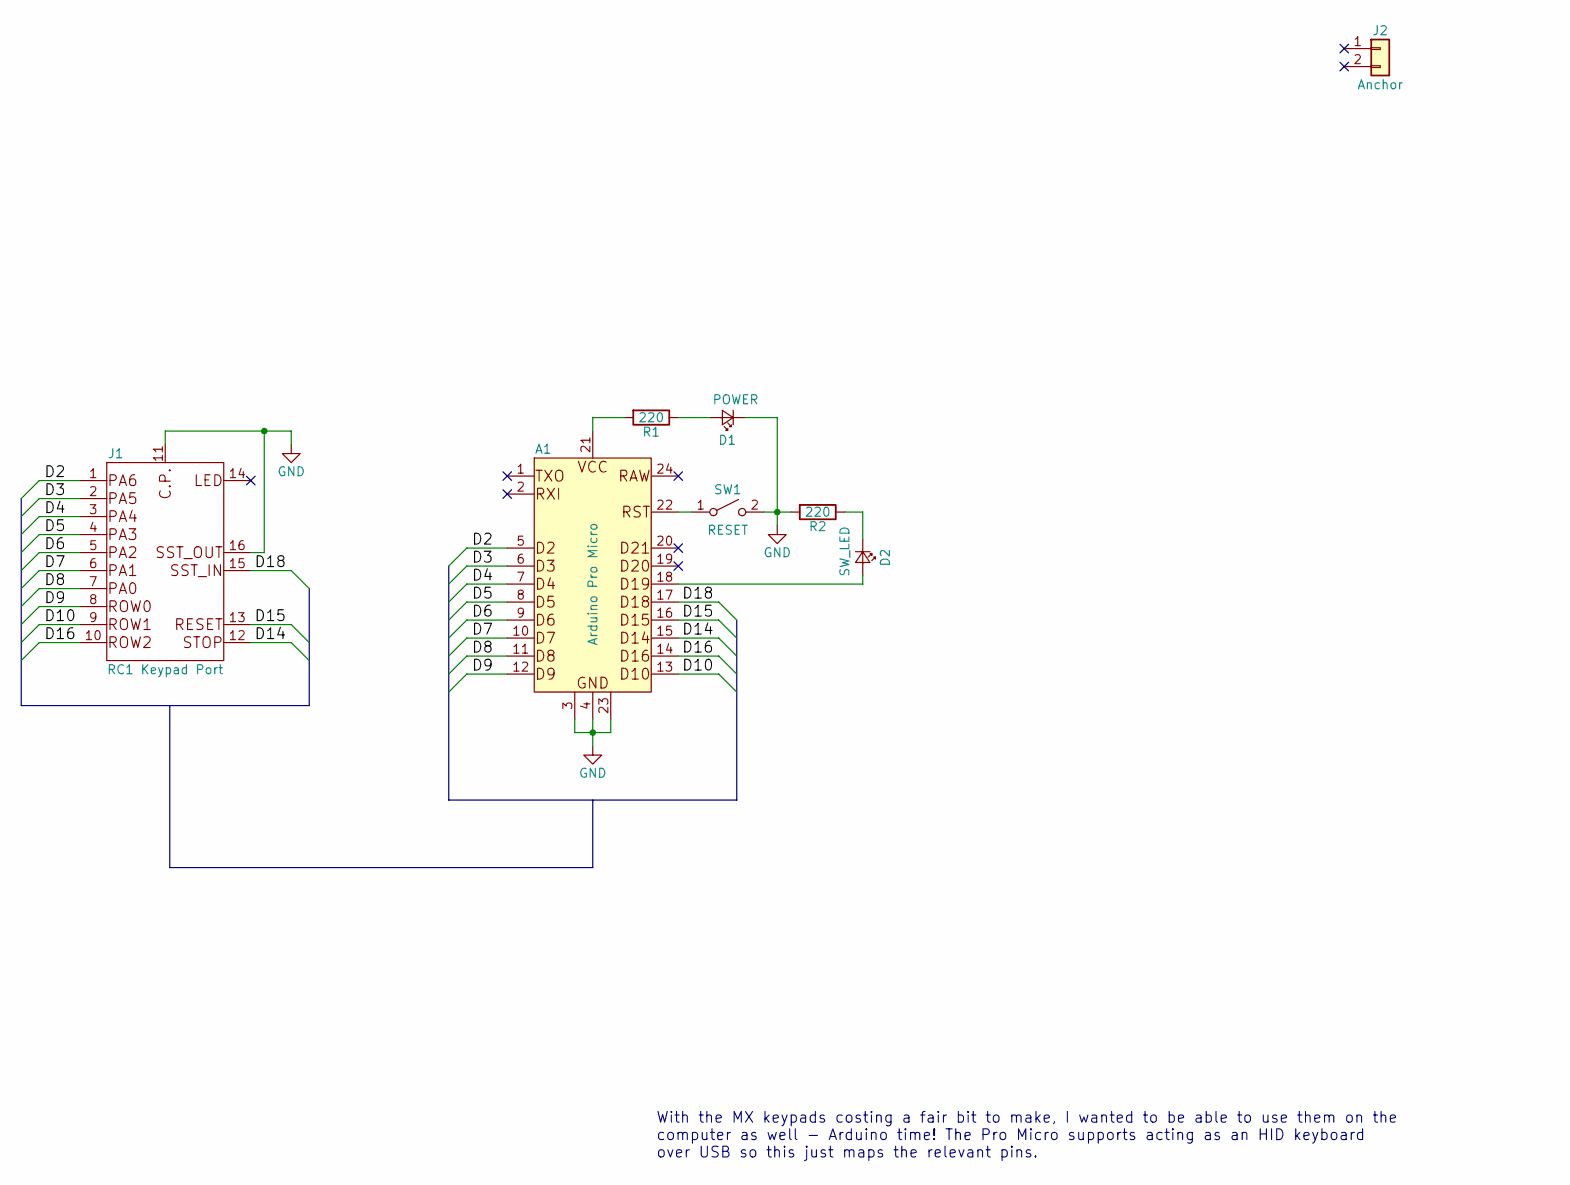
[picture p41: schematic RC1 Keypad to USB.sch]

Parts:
A1: Arduino Pro Micro; Arduino_Pro_Micro
D1: POWER; LED_D5.0mm
D2: SW_LED; LED_D5.0mm
J1: RC1 Keypad Port; Pin_Header_Straight_2x08_Pitch2.54mm
J2: Anchor; Pin_Header_Straight_1x02_Pitch2.54mm
R1, R2: 220; R_Axial_DIN0207_L6.3mm_D2.5mm_P10.16mm_Horizontal
SW1: RESET; SW_PUSH_6mm

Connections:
/D2: A1.5 (D2), J1.1
/D3: A1.6 (D3), J1.2
/D4: A1.7 (D4), J1.3
/D5: A1.8 (D5), J1.4
/D6: A1.9 (D6), J1.5
/D7: A1.10 (D7), J1.6
/D8: A1.11 (D8), J1.7
/D9: A1.12 (D9), J1.8
/D10: A1.13 (D10), J1.9
/D14: A1.15 (D14), J1.12
/D15: A1.16 (D15), J1.13
/D16: A1.14 (D16), J1.10
/D18: A1.17 (D18), J1.15
GND: A1.3 (GND), A1.4 (GND), A1.23 (GND), D1.1 (K), J1.11, J1.16, R2.2, SW1.2 (B)
unnamed: A1.18 (D19), D2.2 (A)
unnamed: A1.21 (VCC), R1.2
unnamed: A1.22 (RST), SW1.1 (A)
unnamed: D1.2 (A), R1.1
unnamed: D2.1 (K), R2.1

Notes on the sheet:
With the MX keypads costing a fair bit to make, I wanted to be able to use them on the computer as well - Arduino time! The Pro Micro supports acting as an HID keyboard over USB so this just maps the relevant pins.

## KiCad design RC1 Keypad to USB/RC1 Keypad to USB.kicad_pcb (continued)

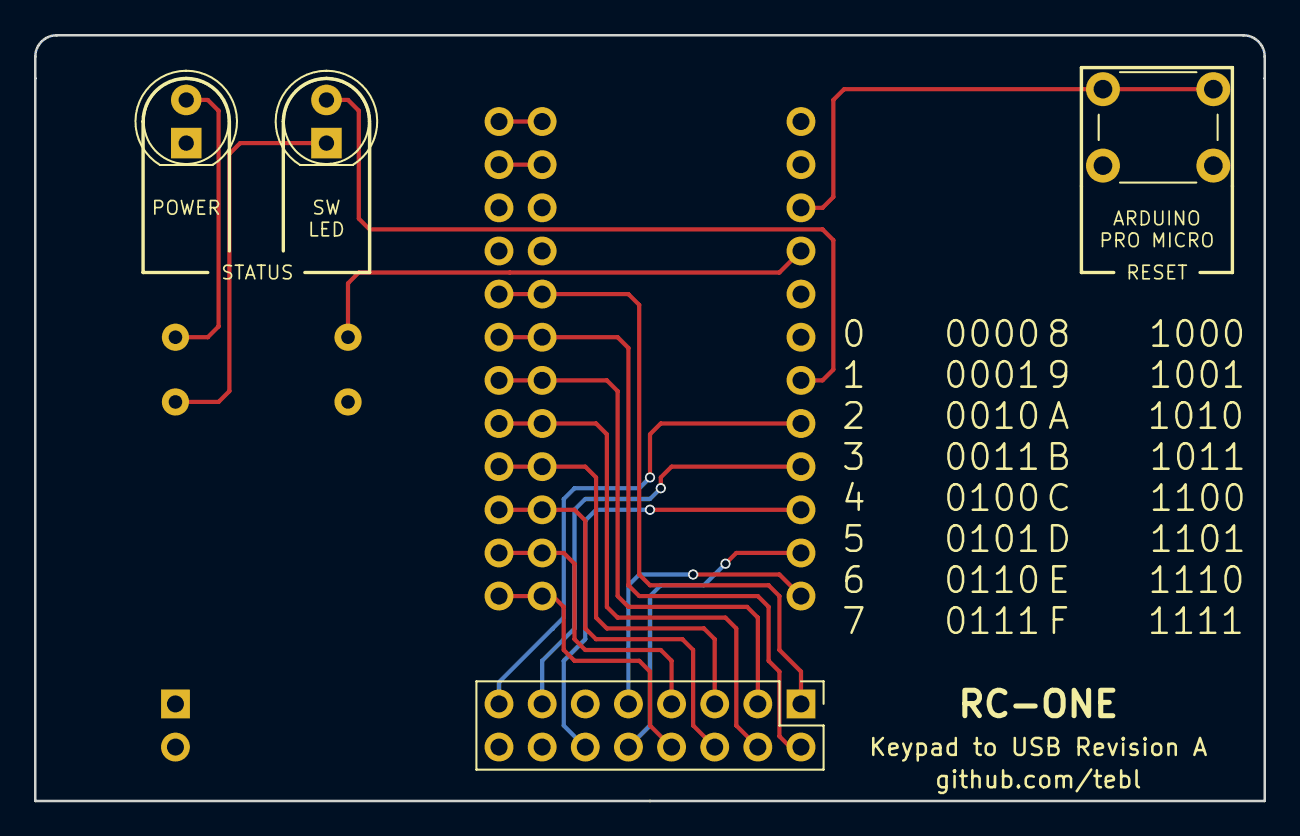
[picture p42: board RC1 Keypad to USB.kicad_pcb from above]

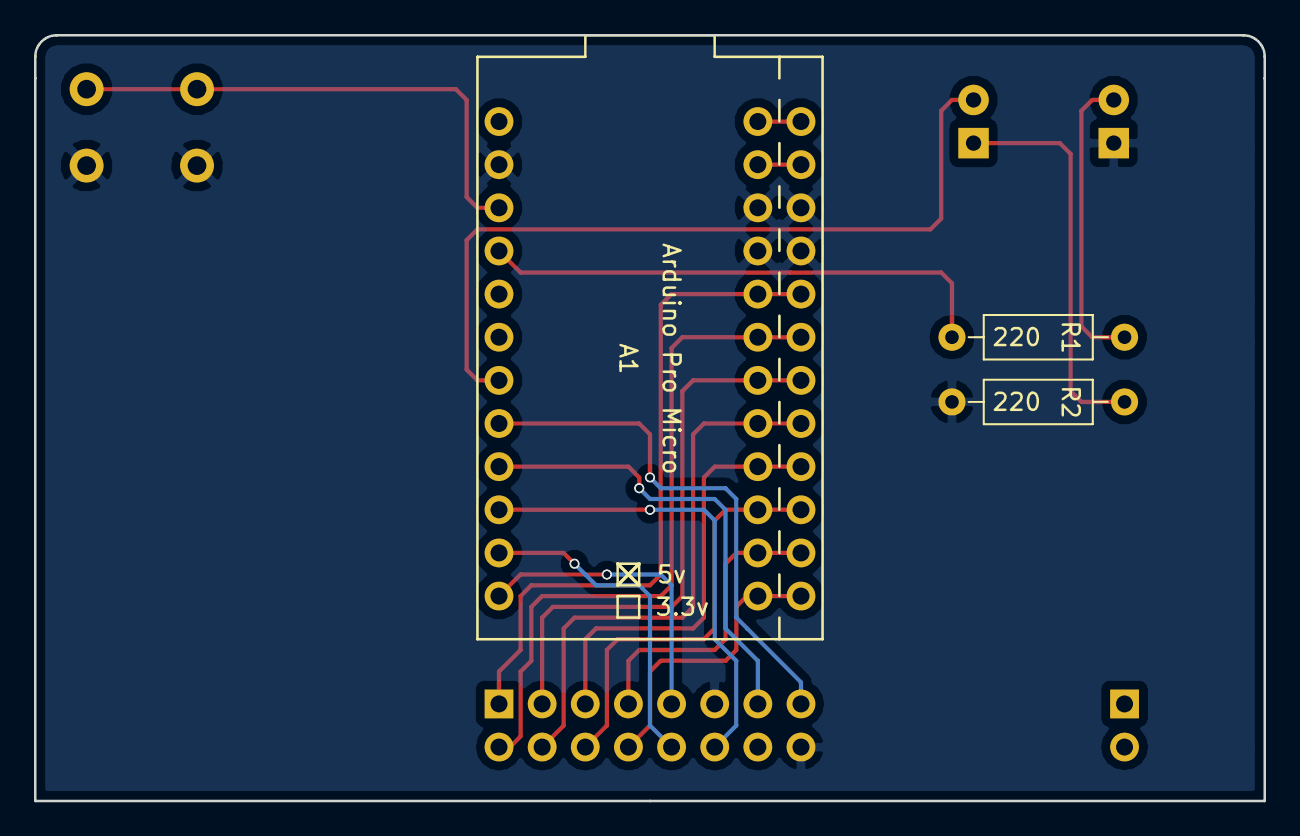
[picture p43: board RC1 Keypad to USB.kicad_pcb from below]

Board: 2 copper layers, 72.4 x 45.1 mm, 8 parts (2 on the bottom side), 19 nets.

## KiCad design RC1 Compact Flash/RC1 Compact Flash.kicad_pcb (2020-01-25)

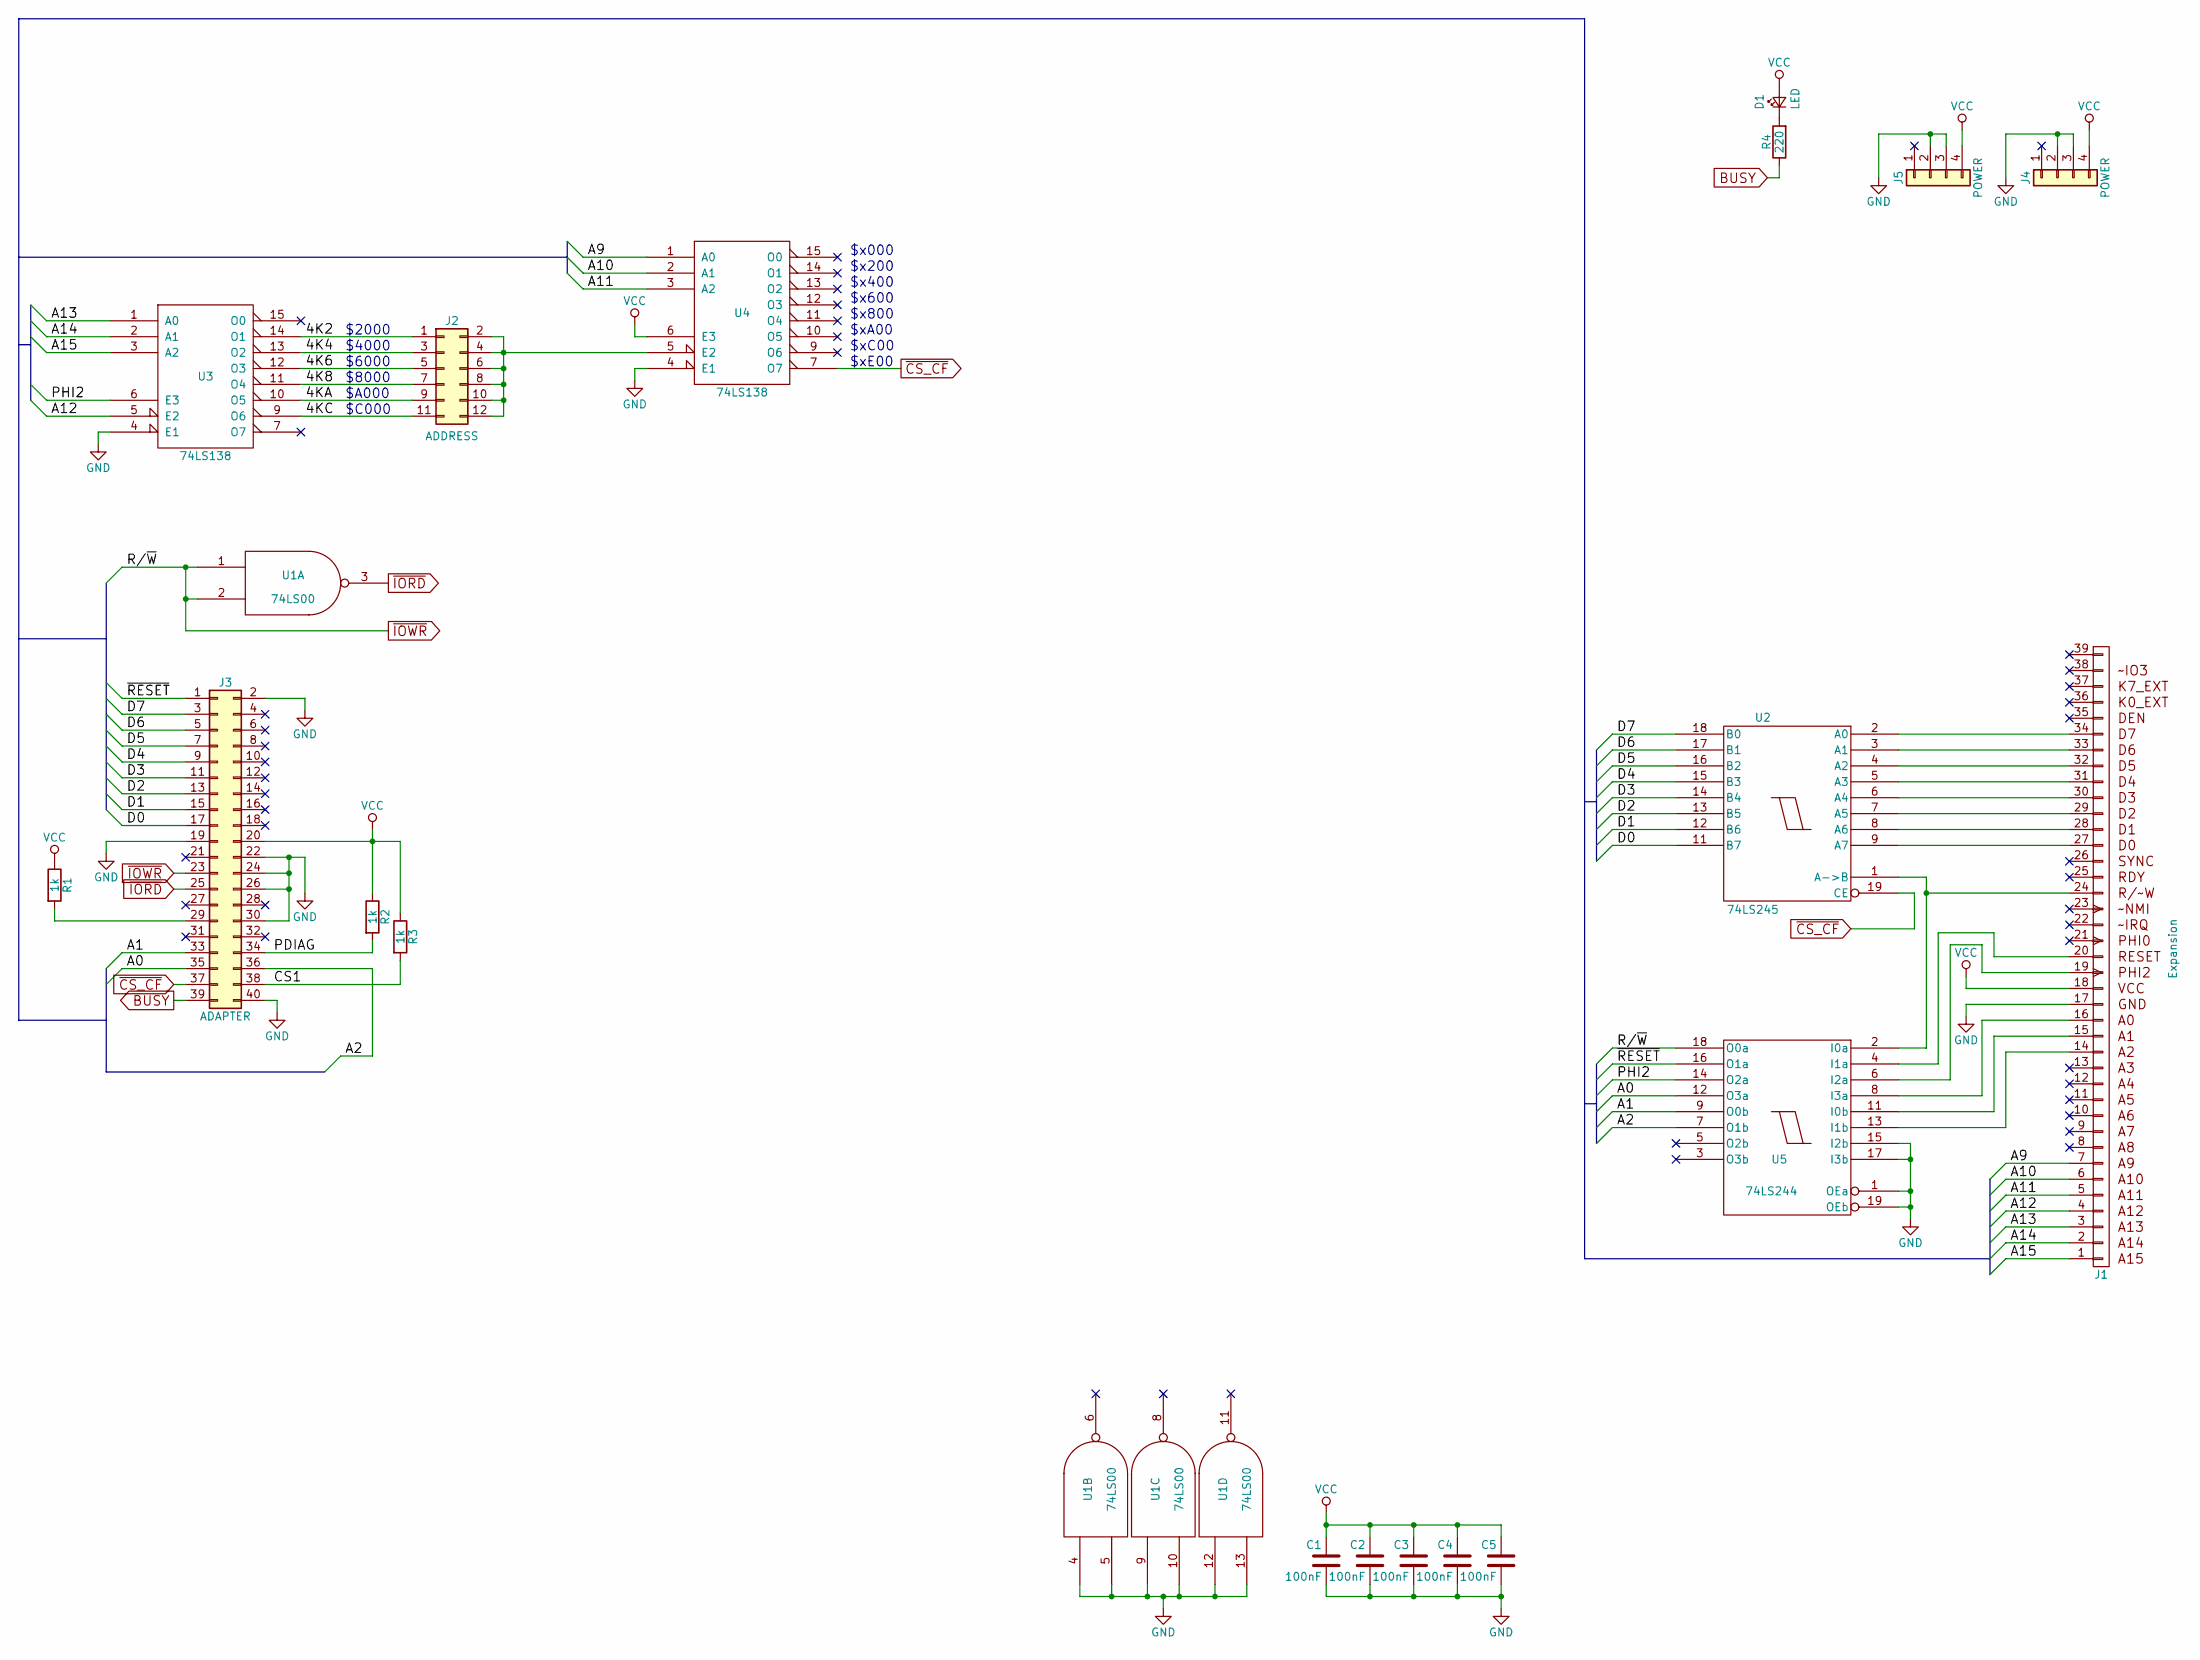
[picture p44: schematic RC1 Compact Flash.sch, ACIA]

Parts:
C1, C2, C3, C4, C5: 100nF; C_Disc_D4.7mm_W2.5mm_P5.00mm
D1: LED; LED_D5.0mm_Horizontal_O3.81mm_Z3.0mm
J1: Expansion; Pin_Header_Angled_1x39_Pitch2.54mm
J2: ADDRESS; Pin_Header_Straight_2x06_Pitch2.54mm
J3: ADAPTER; IDC-Header_2x20_P2.54mm_Horizontal
J4, J5: POWER; Pin_Header_Angled_1x04_Pitch2.54mm
R1, R2, R3: 1k; R_Axial_DIN0207_L6.3mm_D2.5mm_P10.16mm_Horizontal
R4: 220; R_Axial_DIN0207_L6.3mm_D2.5mm_P10.16mm_Horizontal
U1: 74LS00; DIP-14_W7.62mm_Socket_LongPads
U2: 74LS245; DIP-20_W7.62mm_Socket_LongPads
U3, U4: 74LS138; DIP-16_W7.62mm_Socket_LongPads
U5: 74LS244; DIP-20_W7.62mm_Socket_LongPads

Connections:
/4K2: J2.1, U3.14 (O1)
/4K4: J2.3, U3.13 (O2)
/4K6: J2.5, U3.12 (O3)
/4K8: J2.7, U3.11 (O4)
/4KA: J2.9, U3.10 (O5)
/4KC: J2.11, U3.9 (O6)
/A0: J3.35, U5.12 (O3a)
/A1: J3.33, U5.9 (O0b)
/A2: J3.36, U5.7 (O1b)
/A9: J1.7 (A9), U4.1 (A0)
/A10: J1.6 (A10), U4.2 (A1)
/A11: J1.5 (A11), U4.3 (A2)
/A12: J1.4 (A12), U3.5 (E2)
/A13: J1.3 (A13), U3.1 (A0)
/A14: J1.2 (A14), U3.2 (A1)
/A15: J1.1 (A15), U3.3 (A2)
/CS1: J3.38, R3.2
/D0: J3.17, U2.11 (B7)
/D1: J3.15, U2.12 (B6)
/D2: J3.13, U2.13 (B5)
/D3: J3.11, U2.14 (B4)
/D4: J3.9, U2.15 (B3)
/D5: J3.7, U2.16 (B2)
/D6: J3.5, U2.17 (B1)
/D7: J3.3, U2.18 (B0)
/PDIAG: J3.34, R2.2
/PHI2: U3.6 (E3), U5.14 (O2a)
/~RESET: J3.1, U5.16 (O1a)
BUSY: J3.39, R4.1
GND: C1.2, C2.2, C3.2, C4.2, C5.2, J1.17, J3.2, J3.19, J3.22, J3.24, J3.26, J3.30, J3.40, J4.2, J4.3, J5.2, J5.3, U1.4, U1.5, U1.7 (GND), U1.9, U1.10, U1.12, U1.13, U2.10 (GND), U3.4 (E1), U3.8 (GND), U4.4 (E1), U4.8 (GND), U5.1 (OEa), U5.10 (GND), U5.15 (I2b), U5.17 (I3b), U5.19 (OEb)
unnamed: D1.1 (K), R4.2
unnamed: J1.14 (A2), U5.13 (I1b)
unnamed: J1.15 (A1), U5.11 (I0b)
unnamed: J1.16 (A0), U5.8 (I3a)
unnamed: J1.19 (PHI2), U5.6 (I2a)
unnamed: J1.20 (RESET), U5.4 (I1a)
unnamed: J1.24 (RW), U2.1 (A->B), U5.2 (I0a)
unnamed: J1.27 (D0), U2.9 (A7)
unnamed: J1.28 (D1), U2.8 (A6)
unnamed: J1.29 (D2), U2.7 (A5)
unnamed: J1.30 (D3), U2.6 (A4)
unnamed: J1.31 (D4), U2.5 (A3)
unnamed: J1.32 (D5), U2.4 (A2)
unnamed: J1.33 (D6), U2.3 (A1)
unnamed: J1.34 (D7), U2.2 (A0)
unnamed: J2.2, J2.4, J2.6, J2.8, J2.10, J2.12, U4.5 (E2)
unnamed: J3.29, R1.2
VCC: C1.1, C2.1, C3.1, C4.1, C5.1, D1.2 (A), J1.18, J3.20, J4.4, J5.4, R1.1, R2.1, R3.1, U1.14 (VCC), U2.20 (VCC), U3.16 (VCC), U4.6 (E3), U4.16 (VCC), U5.20 (VCC)
~CS_CF: J3.37, U2.19 (CE), U4.7 (O7)
~IORD: J3.25, U1.3
~IOWR: J3.23, U1.1, U1.2, U5.18 (O0a)

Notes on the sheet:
$2000
$4000
$6000
$8000
$A000
$C000
$x000
$xE00
$x400
$x200
$x600
$x800
$xC00
$xA00

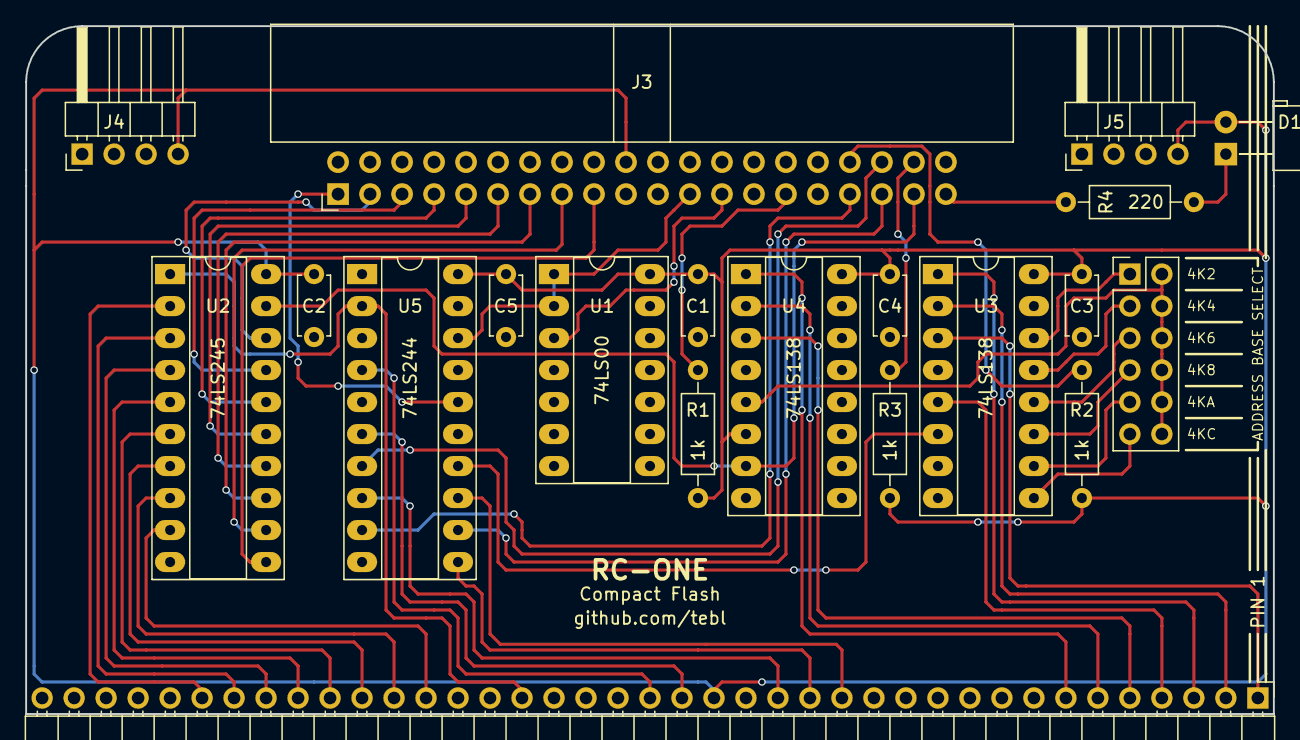
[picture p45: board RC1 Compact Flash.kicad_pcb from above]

Board: 2 copper layers, 99.1 x 54.6 mm, 20 parts (0 on the bottom side), 51 nets.

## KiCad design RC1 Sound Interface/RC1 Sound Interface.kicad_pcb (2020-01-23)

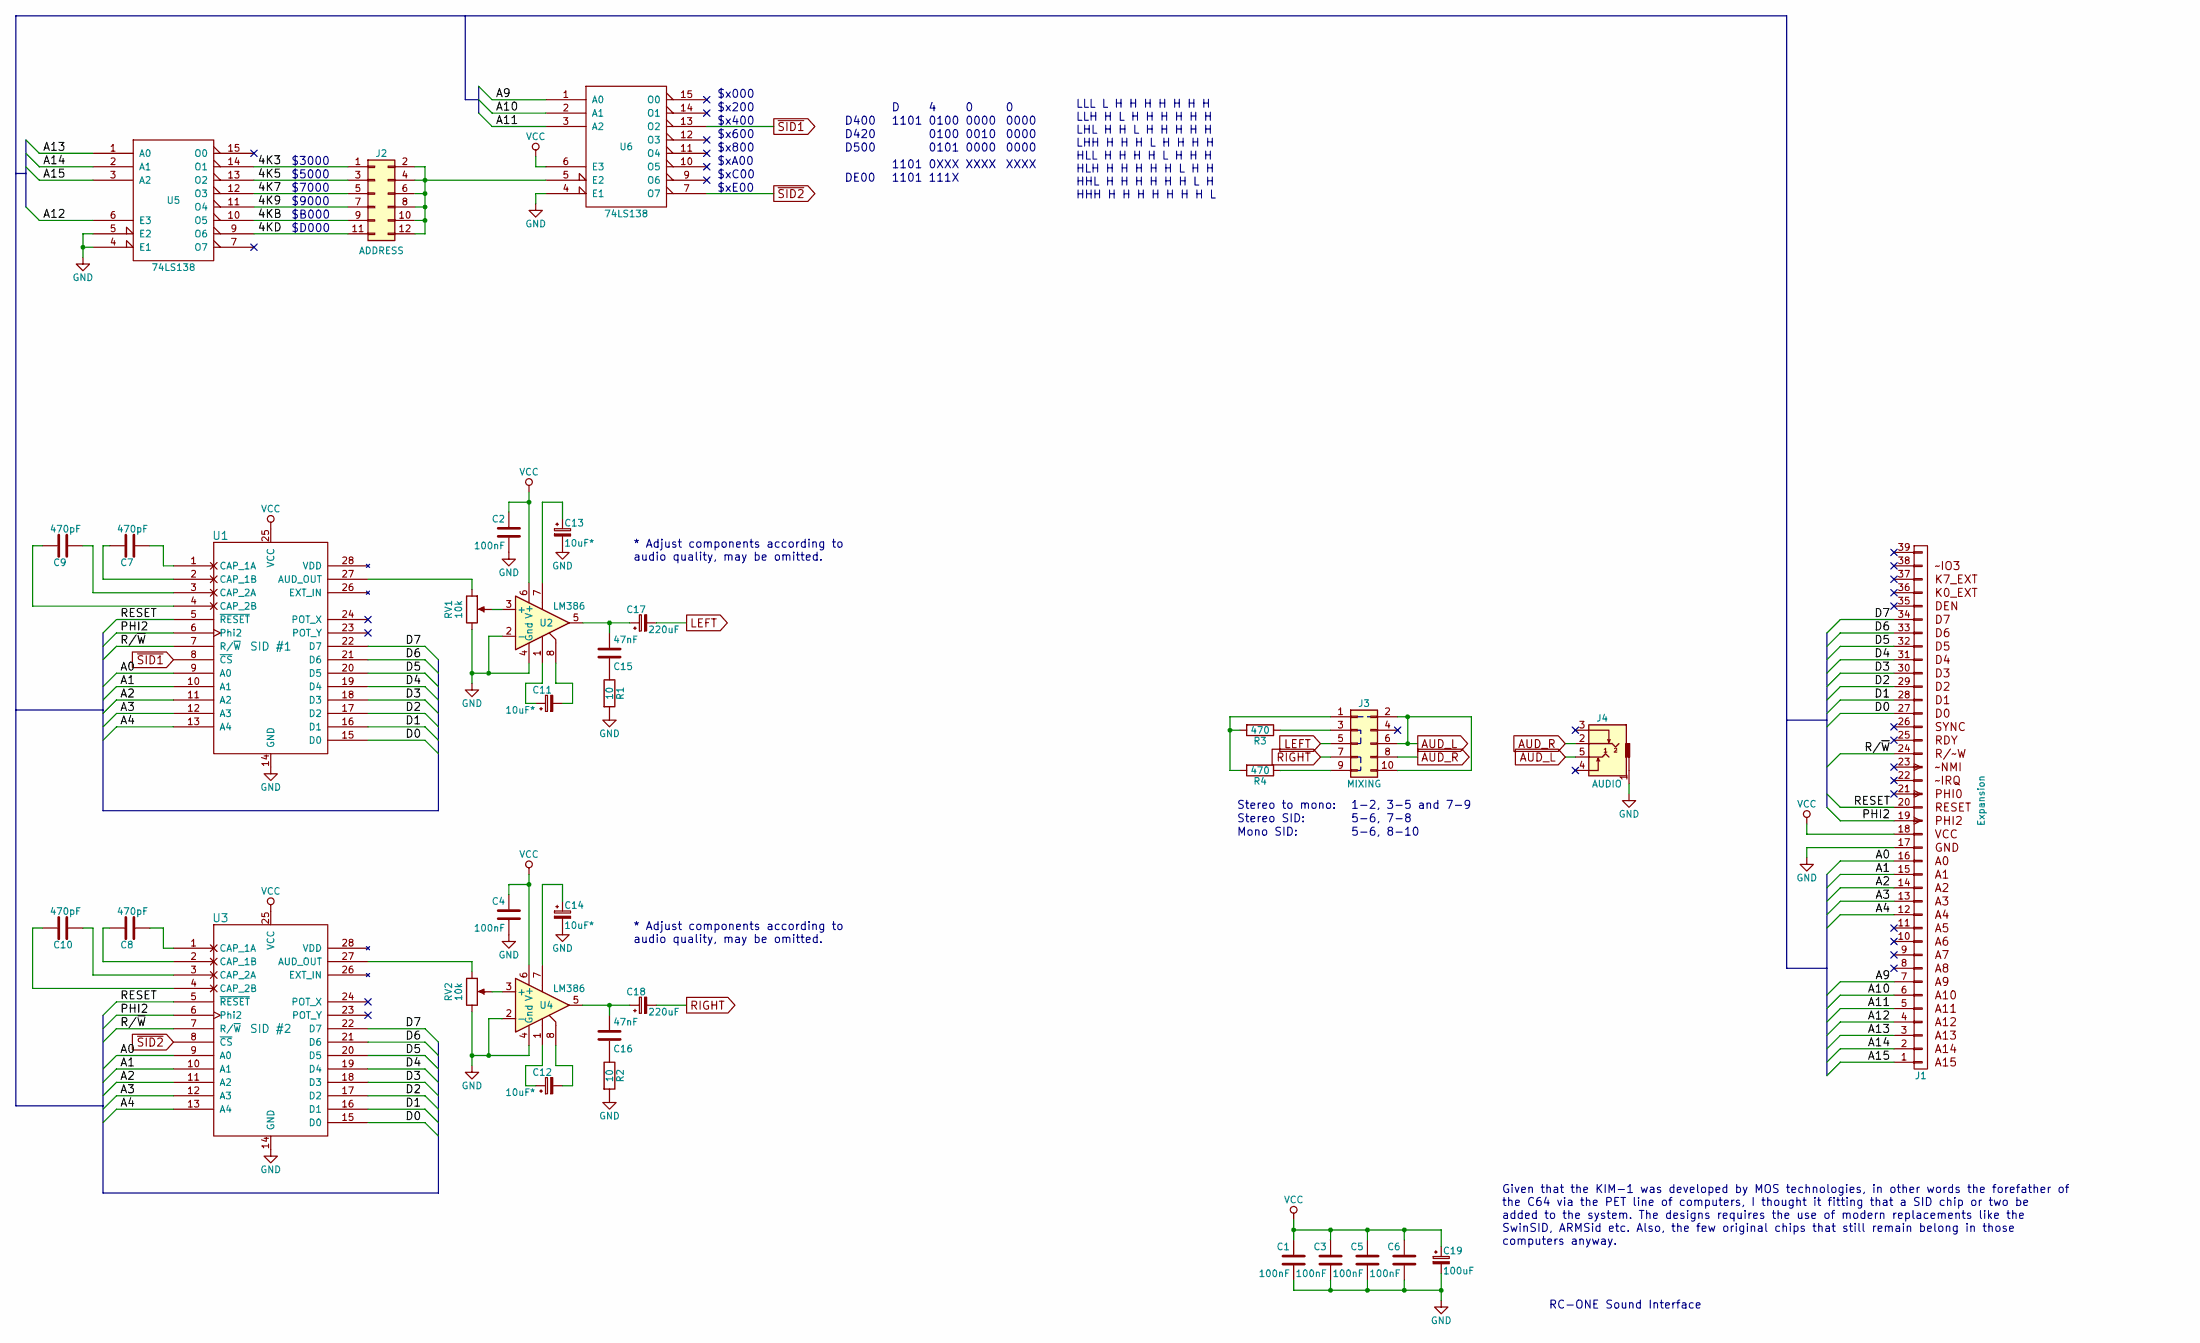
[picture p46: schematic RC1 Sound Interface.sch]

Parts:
C1, C2, C3, C4, C5, C6: 100nF; C_Disc_D4.7mm_W2.5mm_P5.00mm
C7, C8, C9, C10: 470pF; C_Disc_D4.7mm_W2.5mm_P5.00mm
C11, C12, C13, C14: 10uF*; CP_Radial_D5.0mm_P2.50mm
C15, C16: 47nF; C_Disc_D4.7mm_W2.5mm_P5.00mm
C17, C18: 220uF; CP_Radial_D5.0mm_P2.50mm
C19: 100uF; CP_Radial_D5.0mm_P2.50mm
J1: Expansion; Pin_Header_Angled_1x39_Pitch2.54mm
J2: ADDRESS; Pin_Header_Straight_2x06_Pitch2.54mm
J3: MIXING; Pin_Header_Straight_2x05_Pitch2.54mm
J4: AUDIO; Tayda_3.5mm_stereo_TRS_jack_A-853
R1, R2: 10; R_Axial_DIN0207_L6.3mm_D2.5mm_P10.16mm_Horizontal
R3, R4: 470; R_Axial_DIN0207_L6.3mm_D2.5mm_P10.16mm_Horizontal
RV1, RV2: 10k; Potentiometer_Trimmer_Bourns_3296W
U1: SID #1; DIP-28_W15.24mm_Socket
U2, U4: LM386; DIP-8_W7.62mm_Socket
U3: SID #2; DIP-28_W15.24mm_Socket
U5, U6: 74LS138; DIP-16_W7.62mm_Socket

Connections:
/4K3: J2.1, U5.14 (O1)
/4K5: J2.3, U5.13 (O2)
/4K7: J2.5, U5.12 (O3)
/4K9: J2.7, U5.11 (O4)
/4KB: J2.9, U5.10 (O5)
/4KD: J2.11, U5.9 (O6)
/A0: J1.16 (A0), U1.9 (A0), U3.9 (A0)
/A1: J1.15 (A1), U1.10 (A1), U3.10 (A1)
/A2: J1.14 (A2), U1.11 (A2), U3.11 (A2)
/A3: J1.13 (A3), U1.12 (A3), U3.12 (A3)
/A4: J1.12 (A4), U1.13 (A4), U3.13 (A4)
/A9: J1.7 (A9), U6.1 (A0)
/A10: J1.6 (A10), U6.2 (A1)
/A11: J1.5 (A11), U6.3 (A2)
/A12: J1.4 (A12), U5.6 (E3)
/A13: J1.3 (A13), U5.1 (A0)
/A14: J1.2 (A14), U5.2 (A1)
/A15: J1.1 (A15), U5.3 (A2)
/D0: J1.27 (D0), U1.15 (D0), U3.15 (D0)
/D1: J1.28 (D1), U1.16 (D1), U3.16 (D1)
/D2: J1.29 (D2), U1.17 (D2), U3.17 (D2)
/D3: J1.30 (D3), U1.18 (D3), U3.18 (D3)
/D4: J1.31 (D4), U1.19 (D4), U3.19 (D4)
/D5: J1.32 (D5), U1.20 (D5), U3.20 (D5)
/D6: J1.33 (D6), U1.21 (D6), U3.21 (D6)
/D7: J1.34 (D7), U1.22 (D7), U3.22 (D7)
/PHI2: J1.19 (PHI2), U1.6 (Phi2), U3.6 (Phi2)
/R/~W: J1.24 (RW), U1.7 (R/~W), U3.7 (R/~W)
/RESET: J1.20 (RESET), U1.5 (~RESET), U3.5 (~RESET)
AUD_L: J3.2, J3.6, J3.10, J4.5
AUD_R: J3.8, J4.2
GND: C1.2, C2.2, C3.2, C4.2, C5.2, C6.2, C13.2, C14.2, C19.2, J1.17, J4.1, R1.2, R2.2, RV1.3, RV2.3, U1.14 (GND), U2.2 (-), U2.4 (Gnd), U3.14 (GND), U4.2 (-), U4.4 (Gnd), U5.4 (E1), U5.5 (E2), U5.8 (GND), U6.4 (E1), U6.8 (GND)
LEFT: C17.2, J3.5
unnamed: C7.1, U1.1 (CAP_1A)
unnamed: C7.2, U1.2 (CAP_1B)
unnamed: C8.1, U3.1 (CAP_1A)
unnamed: C8.2, U3.2 (CAP_1B)
unnamed: C9.1, U1.3 (CAP_2A)
unnamed: C9.2, U1.4 (CAP_2B)
unnamed: C10.1, U3.3 (CAP_2A)
unnamed: C10.2, U3.4 (CAP_2B)
unnamed: C11.1, U2.1
unnamed: C11.2, U2.8
unnamed: C12.1, U4.1
unnamed: C12.2, U4.8
unnamed: C13.1, U2.7
unnamed: C14.1, U4.7
unnamed: C15.1, R1.1
unnamed: C15.2, C17.1, U2.5
unnamed: C16.1, R2.1
unnamed: C16.2, C18.1, U4.5
unnamed: J2.2, J2.4, J2.6, J2.8, J2.10, J2.12, U6.5 (E2)
unnamed: J3.1, R3.2, R4.2
unnamed: J3.3, R3.1
unnamed: J3.9, R4.1
unnamed: RV1.1, U1.27 (AUD_OUT)
unnamed: RV1.2, U2.3 (+)
unnamed: RV2.1, U3.27 (AUD_OUT)
unnamed: RV2.2, U4.3 (+)
RIGHT: C18.2, J3.7
VCC: C1.1, C2.1, C3.1, C4.1, C5.1, C6.1, C19.1, J1.18, U1.25 (VCC), U2.6 (V+), U3.25 (VCC), U4.6 (V+), U5.16 (VCC), U6.6 (E3), U6.16 (VCC)
~SID1: U1.8 (~CS), U6.13 (O2)
~SID2: U3.8 (~CS), U6.7 (O7)

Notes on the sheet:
RC-ONE Sound Interface
$3000
$5000
$7000
$9000
$B000
$D000
Given that the KIM-1 was developed by MOS technologies, in other words the forefather of the C64 via the PET line of computers, I thought it fitting that a SID chip or two be added to the system. The designs requires the use of modern replacements like the SwinSID, ARMSid etc. Also, the few origina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
$x000
$xE00
1101
0100
0010
0000
0101
D420
D400
D500
LLL L H H H H H H H LLH H L H H H H H H LHL H H L H H H H H LHH H H H L H H H H HLL H H H H L H H H HLH H H H H H L H H HHL H H H H H H L H HHH H H H H H H H L
0XXX
XXXX
DE00
111X
$x400
$x200
$x600
$x800
$xC00
$xA00
1-2, 3-5 and 7-9
Stereo to mono:
Stereo SID:
5-6, 7-8
Mono SID:
5-6, 8-10
* Adjust components according to audio quality, may be omitted.


Board: 2 copper layers, 99.1 x 67.9 mm, 35 parts (0 on the bottom side), 63 nets.

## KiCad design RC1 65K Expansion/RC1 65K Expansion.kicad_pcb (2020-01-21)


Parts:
C1, C2, C3, C4, C5, C6: 100nF; C_Disc_D4.7mm_W2.5mm_P5.00mm
J1: Expansion; Pin_Header_Angled_1x39_Pitch2.54mm
J2: External IO; Pin_Header_Straight_2x10_Pitch2.54mm
J3: Extra; Pin_Header_Straight_1x03_Pitch2.54mm
J4: K1-K4; Pin_Header_Straight_1x04_Pitch2.54mm
J5: LOW RAM; Pin_Header_Straight_2x04_Pitch2.54mm
JP1: 8K1_RAM; Pin_Header_Straight_1x03_Pitch2.54mm
JP2: 8K2_RAM; Pin_Header_Straight_1x03_Pitch2.54mm
JP3: A4_INV; Pin_Header_Straight_1x03_Pitch2.54mm
JP4: 8K3_RAM; Pin_Header_Straight_1x03_Pitch2.54mm
JP5: IRQ_EN; Pin_Header_Straight_1x03_Pitch2.54mm
JP6: 6532_EN; Pin_Header_Straight_1x03_Pitch2.54mm
U1, U2: 74LS138; DIP-16_W7.62mm_Socket
U3, U5: 74LS08; DIP-14_W7.62mm_Socket
U4: R6532; DIP-40_W15.24mm_Socket
U6: 74LS00; DIP-14_W7.62mm_Socket

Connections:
/8K1: JP1.1, U1.14 (O1)
/8K2: JP2.1, U1.13 (O2)
/8K3: JP4.1, U1.12 (O3)
/8K4: J3.1, U1.11 (O4)
/8K5: J3.2, U1.10 (O5)
/8K6: J3.3, U1.9 (O6)
/8K7: U1.7 (O7), U3.5
/A0: J1.16 (A0), U4.7 (A0)
/A1: J1.15 (A1), U4.6 (A1)
/A2: J1.14 (A2), U4.5 (A2)
/A3: J1.13 (A3), U4.4 (A3)
/A4: J1.12 (A4), JP3.3, U6.1, U6.2
/A5: J1.11 (A5), U4.2 (A5)
/A10: J1.6 (A10), U2.1 (A0)
/A11: J1.5 (A11), U2.2 (A1)
/A12: J1.4 (A12), U2.3 (A2)
/A13: J1.3 (A13), U1.1 (A0)
/A14: J1.2 (A14), U1.2 (A1)
/A15: J1.1 (A15), U1.3 (A2)
/D0: J1.27 (D0), U4.33 (D0)
/D1: J1.28 (D1), U4.32 (D1)
/D2: J1.29 (D2), U4.31 (D2)
/D3: J1.30 (D3), U4.30 (D3)
/D4: J1.31 (D4), U4.29 (D4)
/D5: J1.32 (D5), U4.28 (D5)
/D6: J1.33 (D6), U4.27 (D6)
/D7: J1.34 (D7), U4.26 (D7)
/K0: J5.1, U2.15 (O0), U5.4
/K1: J4.1, U2.14 (O1), U5.5
/K2: J4.2, U2.13 (O2), U5.12
/K3: J4.3, U2.12 (O3), U5.13
/K4: J4.4, U2.11 (O4), U6.5
/K6: U2.9 (O6), U5.1
/K7: U2.7 (O7), U5.2
/PA0: J2.18, U4.8 (PA0)
/PA1: J2.16, U4.9 (PA1)
/PA2: J2.14, U4.10 (PA2)
/PA3: J2.12, U4.11 (PA3)
/PA4: J2.10, U4.12 (PA4)
/PA5: J2.8, U4.13 (PA5)
/PA6: J2.6, U4.14 (PA6)
/PA7: J2.4, U4.15 (PA7)
/PB0: J2.17, U4.24 (PB0)
/PB1: J2.15, U4.23 (PB1)
/PB2: J2.13, U4.22 (PB2)
/PB3: J2.11, U4.21 (PB3)
/PB4: J2.9, U4.19 (PB4)
/PB5: J2.7, U4.18 (PB5)
/PB6: J2.5, U4.17 (PB6)
/PB7: J2.3, U4.16 (PB7)
/PHI2: J1.19 (PHI2), U4.39 (PHI2)
/R/~W: J1.24 (RW), U4.35 (R/~W)
/RAM_2K: J5.3, U5.6, U5.9
/RAM_4K: J5.5, U5.8, U6.4
/RAM_5K: J5.7, U6.8
/~IRQ_IN: J1.22 (IRQ), JP5.1
/~RESET: J1.20 (RESET), U4.34 (~RESET)
DEN: J1.35 (TX), U1.15 (O0), U2.5 (E2)
GND: C1.2, C2.2, C3.2, C4.2, C5.2, C6.2, J1.17, J2.1, J2.2, J2.19, U1.4 (E1), U1.5 (E2), U1.8 (GND), U2.4 (E1), U2.8 (GND), U3.7 (GND), U4.1 (GND), U5.7 (GND), U6.7 (GND), U6.12, U6.13
IO3: JP6.2, U4.37 (~CS2)
K0_EXT: J1.36 (RX), U3.11
K7_EXT: J1.37 (NMI), U3.6
unnamed: J1.38, JP6.1
unnamed: JP1.2, U3.2
unnamed: JP2.2, U3.9
unnamed: JP3.1, U6.3
unnamed: JP3.2, U4.3 (A4)
unnamed: JP4.2, U3.10
unnamed: U3.4, U5.3
unnamed: U3.3, U3.12
unnamed: U3.8, U3.13
unnamed: U5.10, U5.11
unnamed: U6.6, U6.9, U6.10
VCC: C1.1, C2.1, C3.1, C4.1, C5.1, C6.1, J1.18, J2.20, JP1.3, JP2.3, JP4.3, JP5.3, JP6.3, U1.6 (E3), U1.16 (VCC), U2.6 (E3), U2.16 (VCC), U3.14 (VCC), U4.20 (VCC), U4.36 (~RS), U4.38 (CS1), U4.40 (A6), U5.14 (VCC), U6.14 (VCC)
~IRQ: JP5.2, U4.25 (~IRQ)
~LOW_RAM: J5.2, J5.4, J5.6, J5.8, U3.1

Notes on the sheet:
RC-ONE 65K Expansion
The original KIM-1 only decoded what in the documentation is called the first 8KB of memory space, it is however repeated in all 8KB blocks on the system. If we want to use the other 56K then we need to replace the adressing logic used, this module does that as well as allow the user access to some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
$E000
$0000
$2000
$4000
$6000
$8000
$A000
$C000
RAM SELECT LOGIC
$0400
$0800
$0C00
$1000
$1400
$1800
$1C00
ROM SELECT LOGIC
Low memory size: 1-2 3-4 5-6 7-8
1K 2K 4K 5K
Original 2K ROM area is mirrored within original memory map, this is done to ensure compatibility with existing software for un-expanded systems.
U4 is optional if the second 6532 for application purposes is not needed, U6 is also only needed for 6532 or with 5K LOW RAM enabled.


Board: 2 copper layers, 99.1 x 55.2 mm, 23 parts (0 on the bottom side), 76 nets.

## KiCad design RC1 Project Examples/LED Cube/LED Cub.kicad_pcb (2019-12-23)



Board: 2 copper layers, 99.1 x 69.2 mm, 43 parts (3 on the bottom side), 58 nets.

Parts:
A1: LED_Cube_4x4
C1, C2: 100nF; C_Disc_D4.7mm_W2.5mm_P5.00mm
J1: Signals; Pin_Header_Straight_1x39_Pitch2.54mm
J5: Port A; Pin_Header_Straight_1x10_Pitch2.54mm
J6: Port B; Pin_Header_Straight_1x10_Pitch2.54mm
M1, M2, M3: Mounting; 1pin
Q1, Q2, Q3, Q4: PN2222A; TO-92_Molded_Narrow
R1, R2, R3, R4, R5, R6, R7, R8, R9, R10, R11, R12, R15, R16, R17, R18, R19, R20, R21, R22, R23, R24, R25, R26: 100; R_Axial_DIN0207_L6.3mm_D2.5mm_P10.16mm_Horizontal
R13, R14: 1k; R_Axial_DIN0207_L6.3mm_D2.5mm_P10.16mm_Horizontal
SW1, SW2: SW_Push; SW_PUSH_6mm
U1, U2: 74LS374; DIP-20_W7.62mm_Socket_LongPads

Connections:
/PA0: J5.1, U1.3, U2.3
/PA1: J5.2, U1.4, U2.4
/PA2: J5.3, U1.7, U2.7
/PA3: J5.4, U1.8, U2.8
/PA4: J5.5, U1.13, U2.13
/PA5: J5.6, U1.14, U2.14
/PA6: J5.7, U1.17, U2.17
/PA7: J5.8, U1.18, U2.18
/PB0: J6.1, U1.11
/PB1: J6.2, U2.11
/PB2: J6.3, R1.2
/PB3: J6.4, R2.2
/PB4: J6.5, R3.2
/PB5: J6.6, R4.2
/PB6: J6.7, R14.1, SW2.1
/PB7: J6.8, R13.1, SW1.1
GND: C1.2, C2.2, J1.17, Q1.1, Q2.1, Q3.1, Q4.1, SW1.2, SW2.2, U1.1, U1.10, U2.1, U2.10
unnamed: A1.1, R8.1
unnamed: A1.2, R10.1
unnamed: A1.3, R11.1
unnamed: A1.4, R12.1
unnamed: A1.5, R15.1
unnamed: A1.6, R16.1
unnamed: A1.7, R17.1
unnamed: A1.8, R18.1
unnamed: A1.9, R19.1
unnamed: A1.10, R20.1
unnamed: A1.11, R21.1
unnamed: A1.12, R22.1
unnamed: A1.13, R23.1
unnamed: A1.14, R24.1
unnamed: A1.15, R25.1
unnamed: A1.16, R26.1
unnamed: A1.17, Q1.3, R9.1
unnamed: A1.18, Q2.3, R5.1
unnamed: A1.19, Q3.3, R6.1
unnamed: A1.20, Q4.3, R7.1
unnamed: Q1.2, R1.1
unnamed: Q2.2, R2.1
unnamed: Q3.2, R3.1
unnamed: Q4.2, R4.1
unnamed: R8.2, U1.2
unnamed: R10.2, U1.5
unnamed: R11.2, U1.6
unnamed: R12.2, U1.9
unnamed: R15.2, U1.12
unnamed: R16.2, U1.15
unnamed: R17.2, U1.16
unnamed: R18.2, U1.19
unnamed: R19.2, U2.2
unnamed: R20.2, U2.5
unnamed: R21.2, U2.6
unnamed: R22.2, U2.9
unnamed: R23.2, U2.12
unnamed: R24.2, U2.15
unnamed: R25.2, U2.16
unnamed: R26.2, U2.19
VCC: C1.1, C2.1, J1.18, R5.2, R6.2, R7.2, R9.2, R13.2, R14.2, U1.20, U2.20

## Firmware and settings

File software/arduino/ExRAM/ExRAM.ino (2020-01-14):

/*
 * Originally based on the Arduino EEPROM programmer as
 * featured in a video by Ben Eater. I started with his
 * code, then adapted it to serve as a way to load data
 * into a 62256 static RAM chip before adding functions
 * for handling Intel HEX and papertape formats.
 */
#define SHIFT_DATA 2
#define SHIFT_CLK 3
#define SHIFT_LATCH 4

#define EX_D0 6
#define EX_D7 13
#define EX_A13 14
#define EX_A14 15
#define EX_RnW 16

#define EX_CONTROL 5
#define EX_RESET 17

#define COLORIZE /* Comment out to remove ANSI-styling */
#define BAUD_RATE 115200
#define MAX_MEMORY_SIZE 8192
#define MAX_INPUT_SIZE 100

/* Variables */
int memory_bank = 0;
int memory_base = 0x2000;
int memory_size = MAX_MEMORY_SIZE;
bool colorize = true;
String command;

void setup() {
  pinMode(SHIFT_DATA, OUTPUT);
  pinMode(SHIFT_CLK, OUTPUT);
  pinMode(SHIFT_LATCH, OUTPUT);
  pinMode(EX_CONTROL, OUTPUT);

  Serial.begin(BAUD_RATE);
  disable();
  
  pinMode(EX_A13, OUTPUT);
  pinMode(EX_A14, OUTPUT);
  pinMode(EX_RESET, INPUT);
  
  print_welcome();
  bank0();
  base_8k1();
  memory_2k();

  Serial.println();
  print_help();
}

#ifdef COLORIZE
void ansi_on() {
  colorize = true;
  Serial.print(F("\033[1;31mA\033[1;32mN\033[1;33mS\033[1;34mI"));
  ansi_default();
  Serial.print(F(" terminal codes "));
  ansi_bright();
  Serial.print(F("ON"));
  ansi_default();
  Serial.println(F("!"));
}

void ansi_off() {
  colorize = false;
  Serial.println(F("ANSI terminal codes OFF!"));
}
#endif

void ansi_bright() {
  #ifdef COLORIZE
  if (colorize) Serial.print(F("\033[1;37m"));
  #endif
}

void ansi_weak() {
  #ifdef COLORIZE
  if (colorize) Serial.print(F("\033[34m"));
  #endif
}

void ansi_notice() {
  #ifdef COLORIZE
  if (colorize) Serial.print(F("\033[36m"));
  #endif
}

void ansi_error() {
  #ifdef COLORIZE
  if (colorize) Serial.print(F("\033[1;31m"));
  #endif  
}

void ansi_default() {
  #ifdef COLORIZE
  if (colorize) Serial.print(F("\033[0m"));
  #endif
}

/*
 * Assert control, locking out the 6502-system from
 * being able to access the memory.
 */
void enable() {
  digitalWrite(EX_CONTROL, LOW);
  
  digitalWrite(EX_RnW, HIGH);
  pinMode(EX_RnW, OUTPUT);

  for (int pin = EX_D0; pin <= EX_D7; pin += 1) {
    pinMode(pin, OUTPUT);
  }
}

/*
 * Release control, allowing the 6502-system
 * access to the memory again.
 */
void disable() {
  for (int pin = EX_D0; pin <= EX_D7; pin += 1) {
    pinMode(pin, INPUT);
  }

  pinMode(EX_RnW, INPUT);
  digitalWrite(EX_CONTROL, HIGH);

  /* ensure serial LEDs stay off */
  digitalWrite(SHIFT_CLK, LOW);
  digitalWrite(SHIFT_DATA, LOW);
}

/*
 * Shift out the specified 16-bit address.
 */
void set_address(int address) {
  shiftOut(SHIFT_DATA, SHIFT_CLK, MSBFIRST, (address >> 8));
  shiftOut(SHIFT_DATA, SHIFT_CLK, MSBFIRST, address);

  digitalWrite(SHIFT_LATCH, LOW);
  digitalWrite(SHIFT_LATCH, HIGH);
  digitalWrite(SHIFT_LATCH, LOW);
}

void set_read() {
  for (int pin = EX_D0; pin <= EX_D7; pin += 1) {
    pinMode(pin, INPUT);
  }
  digitalWrite(EX_RnW, HIGH);
}

/*
 * Read a byte from the data pins, use set_direction
 * to perform sequential steps without setting up every
 * time.
 */
byte read_byte(bool set_direction = false) {
  if (set_direction) set_read();
  
  byte value = 0;
  for (int pin = EX_D7; pin >= EX_D0; pin -= 1) {
    value = (value << 1) + digitalRead(pin);
  }
  return value;
}

void set_write() {
  digitalWrite(EX_RnW, HIGH);
  for (int pin = EX_D0; pin <= EX_D7; pin += 1) {
    pinMode(pin, OUTPUT);
  }
}

/*
 * Write a byte to the data pins, use set_direction
 * to perform sequential steps without setting up every
 * time.
 */
void write_byte(byte value, bool set_direction = false) {
  if (set_direction) set_write();
  
  for (int pin = EX_D0; pin <= EX_D7; pin += 1) {
    digitalWrite(pin, value & 1);
    value = value >> 1;
  }
  digitalWrite(EX_RnW, LOW);
  delayMicroseconds(1);
  digitalWrite(EX_RnW, HIGH);
}

/*
 * Prints the welcome message to serial output, essentially
 * program version followed by the help message.
 */
void print_welcome() {
  ansi_bright();
  print_version();
  ansi_default();
  ansi_notice();
  Serial.println(F("\nConfiguration:"));
  ansi_default();
}

void print_version() {
  Serial.println(F("ExRAM 0.2"));
}

/*
 * Prints out the status of the 6502-system, this is done
 * by checking wether the reset lines has been pulled up.
 * Might not be reliable as it'd be floating though it
 * seems to be working anyway (famous last words).
 */
void print_status() {
  int val = digitalRead(EX_RESET);
  Serial.print(F("Host system "));
  if (val == 0) {
    ansi_error();
    Serial.print(F("offline"));
  }
  else {
    ansi_bright();
    Serial.print(F("powered"));
  }
  ansi_default();
  Serial.println();
}

void print_bank() {
  Serial.print(F("Bank "));
  Serial.print(memory_bank);
  Serial.println(F(" enabled"));
}

void bank0() {
  set_bank(0);
}

void bank1() {
  set_bank(1);
}

void bank2() {
  set_bank(2);
}

void bank3() {
  set_bank(3);
}

void set_bank(int num) {
  memory_bank = num;
  switch (memory_bank) {
    case 0:
      digitalWrite(EX_A13, LOW);
      digitalWrite(EX_A14, LOW);
      Serial.println(F("Bank 0 enabled"));
      break;
    case 1:
      digitalWrite(EX_A13, HIGH);
      digitalWrite(EX_A14, LOW);
      Serial.println(F("Bank 1 enabled"));
      break;
    case 2:
      digitalWrite(EX_A13, LOW);
      digitalWrite(EX_A14, HIGH);
      Serial.println(F("Bank 2 enabled"));
      break;
    case 3:
      digitalWrite(EX_A13, HIGH);
      digitalWrite(EX_A14, HIGH);
      Serial.println(F("Bank 3 enabled"));
      break;
  }
}

void print_memory() {
  Serial.print(memory_size / 1024);
  Serial.println("K");
}

void memory_1k() {
  set_memory(1024 * 1);
}

void memory_2k() {
  set_memory(1024 * 2);
}

void memory_4k() {
  set_memory(1024 * 4);
}

void memory_8k() {
  set_memory(1024 * 8);
}

void set_memory(int num_bytes) {
  memory_size = num_bytes;
  Serial.print(num_bytes / 1024);
  Serial.println("K");
}

void print_max_memory() {
  Serial.print(MAX_MEMORY_SIZE / 1024);
  Serial.println("K");
}

void print_memory_base() {
  print_address(memory_base);
  Serial.print(" - ");
  print_address(memory_base + 0x1FFF);
  Serial.println();
}

void print_address(int number) {
  char tmp[10];
  sprintf(tmp, "$%04X", number);
  Serial.print(tmp);
}

void base_8k0() { set_base(0x0000); }
void base_8k1() { set_base(0x2000); }
void base_8k2() { set_base(0x4000); }
void base_8k3() { set_base(0x6000); }
void base_8k4() { set_base(0x8000); }
void base_8k5() { set_base(0xA000); }
void base_8k6() { set_base(0xC000); }
void base_8k7() { set_base(0xE000); }

void set_base(int value){
  memory_base = value;
  print_memory_base();
}

/*
 * Perform a test of the configured amount of memory, this
 * section of memory has different patterns written to it
 * in 16 byte blocks before comparing the value to what is
 * read back.
 */
void memory_test() {
  unsigned char patterns[] = {0x00, 0xFF, 0x55, 0xAA};

  enable();
  Serial.print(F("Testing "));
  ansi_bright();
  Serial.print(memory_size / 1024);
  Serial.print('K');
  ansi_default();
  Serial.println(F(" of memory:"));
  for (char i = 0; i < (sizeof(patterns) / sizeof(patterns[0])); i++) {
    if (memory_test_pattern(i, patterns[i])) {
      ansi_notice();
      Serial.println(F(" OK!"));
      ansi_default();
    } else {
      ansi_error();
      Serial.println(F(" failed!"));
      ansi_default();
      break;
    }
  }
  Serial.println(F("Testing completed!"));
  disable();
}

bool memory_test_pattern(char pass, unsigned char pattern) {
  char tmp[10];
  ansi_notice();
  Serial.print("Pass ");
  sprintf(tmp, "%d (0x%02X) ", pass, pattern);
  Serial.print(tmp);
  ansi_default();

  bool passed = true;
  for (int base = 0; base < memory_size; base += 16) {
    set_write();
    for (int offset = 0; offset <= 15; offset += 1) {
      set_address(base + offset);
      write_byte(pattern);
    }
    
    set_read();
    bool block_passed = true;
    for (int offset = 0; offset <= 15; offset += 1) {
      set_address(base + offset);
      if (read_byte() != pattern) {
        passed = false;
        block_passed = false;
      }
    }
       
    if (block_passed) {
      Serial.print(".");
    } else {
      Serial.print("x");
    }
  }

  return passed;
}

/*
 * Zero out the contents of memory, this is handy when it has
 * been filled with unknown data or simply junk.
 */
void memory_zero() {
  Serial.print(F("Zeroing "));
  ansi_bright();
  Serial.print(memory_size / 1024);
  Serial.print('K');
  ansi_default();
  Serial.print(F(" of memory "));

  enable();
  set_write();

  for (int pin = EX_D0; pin <= EX_D7; pin += 1) digitalWrite(pin, 0);
  for (int base = 0; base < memory_size; base += 16) {
    for (int offset = 0; offset <= 15; offset += 1) {
      set_address(base + offset);
      digitalWrite(EX_RnW, LOW);
      delayMicroseconds(1);
      digitalWrite(EX_RnW, HIGH);
  }

    Serial.print(".");
  }
  disable();

  ansi_notice();
  Serial.println(F(" done!"));
  ansi_default();
}

/*
 * Dumps memory contents to the console, formatting it similarly to
 * the hex dumps found in the book "The First Book of KIM".
 */
void dump() {
  enable();
  set_read();

  ansi_notice();
  Serial.println(F("        0  1  2  3  4  5  6  7    8  9  A  B  C  D  E  F "));
  ansi_default();
  for (int base = 0; base < memory_size; base += 16) {
    byte data[16];
    int sum = 0;
    for (int offset = 0; offset <= 15; offset += 1) {
      set_address(base + offset);
      data[offset] = read_byte();
      sum += data[offset];
    }

    char buf[80];
    ansi_notice();
    sprintf(buf, "$%.4X- ", base + memory_base);
    Serial.print(buf);
    ansi_default();

    sprintf(buf, "%02X %02X %02X %02X %02X %02X %02X %02X   %02X %02X %02X %02X %02X %02X %02X %02X",
            data[0], data[1], data[2], data[3], data[4], data[5], data[6], data[7],
            data[8], data[9], data[10], data[11], data[12], data[13], data[14], data[15]);

    if (sum == 0 || sum == 4080) ansi_weak();
    Serial.println(buf);
    if (sum == 0 || sum == 4080) ansi_default();
  }

  disable();
}

/*
 * Handle exporting of data to Intel HEX format, this data is printed 
 * to serial directly with a 16 byte record length along with the
 * correct checksum.
 */
void dump_intel() {
  enable();
  set_read();
  int byte_count = 16;
  for (int base = 0; base < memory_size; base += byte_count) {
    byte data[byte_count];
    int hi = ((memory_base + base) & 0xFF00) >> 8;
    int lo = (memory_base + base) & 0x00FF;

    int sum = 0;
    for (int offset = 0; offset < byte_count; offset += 1) {
      set_address(base + offset);
      data[offset] = read_byte();
      sum += data[offset];
    }

    int checksum = intel_checksum(
      0x10, 
      hi,
      lo,
      0x00,
      sum
    );

    char buf[80];
    sprintf(buf, ":%02X%02X%02X%02X%02X%02X%02X%02X%02X%02X%02X%02X%02X%02X%02X%02X%02X%02X%02X%02X%02X",
            byte_count, hi, lo, 0x00,
            data[0], data[1], data[2], data[3], data[4], data[5], data[6], data[7],
            data[8], data[9], data[10], data[11], data[12], data[13], data[14], data[15], checksum);

    Serial.println(buf);
  }
  
  disable();
}

int intel_checksum(int byte_count, int hi, int lo, int record_type, int data_sum) {
  int x = byte_count + hi + lo + record_type + data_sum;
  x = x % 256;
  x = ~x;
  x = x + 1;
  x = x & 0xFF;
  return x;
}

/*
 * Handle importing of Intel HEX files. Data is read and loaded
 * on a line by line basis, the maximum supported byte count for
 * each is 0x20 (32 in decimal). The only record type recognized
 * is the one for data.
 */
bool handle_intel(String c) {
  if (c.length() < 11) return handle_record_error(c, F("record too short"));

  int byte_count = convert_hex_pair(c[1], c[2]);
  if (c.length() != (11 + (byte_count * 2))) return handle_record_error(c, F("length does not match data"));
  if (byte_count > 32) return handle_record_error(c, F("buffer overflow"));

  int address = convert_hex_address(c[3], c[4], c[5], c[6]);
  int hi = (address & 0xFF00) >> 8;
  int lo = address & 0x00FF;
  int record_type = convert_hex_pair(c[7], c[8]);

  byte data[32];
  int data_sum = 0;
  int d = 0;
  for (int i = 0; i < (byte_count * 2); i+=2) {
      data[d] = convert_hex_pair(
        c.charAt(9 + i),
        c.charAt(10 + i)
      );
      
      data_sum += data[d];
      d++;
  }

  int checksum = convert_hex_pair(c[9 + (byte_count * 2)], c[10 + (byte_count * 2)]);
  if (0x00 != ((byte_count + hi + lo + record_type + data_sum + checksum) & 0xFF)) {
    return handle_record_error(c, F("checksum error"));
  } else {
    switch (record_type) {
      case 0x00: /* data */
        enable();
        set_write();
        for (int i = 0; i < byte_count; i++) {
          set_address(address + i);
          write_byte(data[i]);
        }
        disable();
      case 0x01: /* end of file */
      case 0x04: /* extended linear address */
        echo_command(c);
        return true;
      default:
        return handle_record_error(c, F("unknown record type"));
    }
  }
}

int convert_hex_pair(char a1, char a0) {
  return (
      (convert_hex_digit(a1) << 4) +
      (convert_hex_digit(a0))
  );
}

int convert_hex_digit(char digit) {
  digit = (digit > '9' ? digit - 87 : digit - 48);
  if (digit < 0) return digit + 32;
  if (digit > 15) return 15;
  return digit;
}

int convert_hex_address(char a3, char a2, char a1, char a0) {
  return (
      (convert_hex_digit(a3) << 12) +
      (convert_hex_digit(a2) << 8) +
      (convert_hex_digit(a1) << 4) +
      (convert_hex_digit(a0))
   );
}

bool handle_record_error(String c, String e) {
  Serial.print(c);
  Serial.print(" (");
  Serial.print(e);
  Serial.println(")");
  return false;
}

/*
 * Handle exporting of data to Intel HEX format, this data is printed 
 * to serial directly with a 16 byte record length along with the
 * correct checksum.
 * 
 * KIM-1 paper tape format:
 *  Data record:
 *    ;bbaaaaddcccc
 *    ;             = record start
 *     bb           = byte count
 *       aaaa       = address (HI/LO)
 *           dd     = data byte(2 characters per byte)
 *             cccc = record checksum
 *    
 *  Last record:
 *    ;0000040004
 *    ;bbaaaacccc
 *    ;             = record start
 *     bb           = 00
 *       aaaa       = total records
 *           cccc   = record checksum
 */
void dump_paper() {
  enable();
  set_read();

  int byte_count = 16;
  for (int base = 0; base < memory_size; base += byte_count) {
    byte data[byte_count];
    int hi = ((memory_base + base) & 0xFF00) >> 8;
    int lo = (memory_base + base) & 0x00FF;

    int data_sum = 0;
    for (int offset = 0; offset < byte_count; offset += 1) {
      set_address(base + offset);
      data[offset] = read_byte();
      data_sum += data[offset];
    }
    int checksum = paper_checksum(byte_count, hi, lo, data_sum);

    char buf[80];
    ansi_notice();
    sprintf(buf, ";%02X%02X%02X", byte_count, hi, lo);
    Serial.print(buf);
    ansi_default();
    
    sprintf(buf, "%02X%02X%02X%02X%02X%02X%02X%02X%02X%02X%02X%02X%02X%02X%02X%02X",
            data[0], data[1], data[2], data[3], data[4], data[5], data[6], data[7],
            data[8], data[9], data[10], data[11], data[12], data[13], data[14], data[15]);
    Serial.print(buf);

    ansi_notice();
    sprintf(buf, "%04X", checksum);
    Serial.println(buf);
    ansi_default();
}
  
  disable();
}

int paper_checksum(int byte_count, int hi, int lo, int data_sum) {
  return byte_count + hi + lo + data_sum;
}

/* Handle importing of paper tape files. Data is read and loaded
 * on a line by line basis, so as far as error checking there is
 * almost none implemented. For a description of the record format
 * see dump_paper().
  */
bool handle_paper(String c) {
  if (c.length() < 11) return handle_record_error(c, F("record too short"));

  int byte_count = convert_hex_pair(c[1], c[2]);
  if (c.length() != (11 + (byte_count * 2))) return handle_record_error(c, F("length does not match data"));
  if (byte_count > 24) return handle_record_error(c, F("buffer overflow"));

  int address = convert_hex_address(c[3], c[4], c[5], c[6]);
  int hi = (address & 0xFF00) >> 8;
  int lo = address & 0x00FF;

  byte data[24];
  int data_sum = 0;
  int d = 0;

  for (int i = 0; i < (byte_count * 2); i+=2) {
    data[d] = convert_hex_pair(
      c.charAt(7 + i),
      c.charAt(8 + i)
    );
    
    data_sum += data[d];
    d++;
  }

  int checksum = convert_hex_address(
    c[7 + (byte_count * 2)], 
    c[8 + (byte_count * 2)],
    c[9 + (byte_count * 2)],
    c[10 + (byte_count * 2)]
  );
  if (checksum == (byte_count + hi + lo + data_sum)) {
    enable();
    set_write();
    for (int i = 0; i < byte_count; i++) {
      set_address(address + i);
      write_byte(data[i]);
    }
    disable();

    echo_command(c);
    return true;
  } else {
    return handle_record_error(c, F("checksum error"));
  }
}

void lock_on() {
  enable();
  Serial.print(F("ExRAM "));
  ansi_error();
  Serial.print(F("locked"));
  ansi_default();
  Serial.println();
}

void lock_off() {
  disable();
  Serial.print(F("ExRAM "));
  ansi_bright();
  Serial.print(F("unlocked"));
  ansi_default();
  Serial.println();
}

void print_help() {
  ansi_notice();
  Serial.println(F("Commands supported:"));
  ansi_default();
  #ifdef COLORIZE
  Serial.println(F("ansi <on|off>  Enable or disable ANSI terminal codes"));
  #endif
  Serial.println(F("bank           Prints bank selection"));
  Serial.println(F("bank <num>     Select 8k bank"));
  Serial.println(F("base           Prints memory offset used"));
  Serial.println(F("base <block>   8k0-8k7 memory offset"));
  Serial.println(F("dump           Dump memory"));
  Serial.println(F("dump intel     Intel HEX dump"));
  Serial.println(F("dump paper     Paper tape memory dump"));
  Serial.println(F("help           Prints this screen"));
  Serial.println(F("lock <on|off>  Lock 6502 ExRAM access"));
  Serial.println(F("memory         Print memory dump size"));
  Serial.println(F("memory <size>  1k/2k/4k/8k memory dump size"));
  Serial.println(F("memory test    Test set memory"));
  Serial.println(F("memory zero    Zero out set memory"));
  Serial.println(F("status         Prints system status"));
  Serial.println(F("version        Prints ExRAM software version"));
  Serial.println(F(":<data>        Load Intel HEX data"));
  Serial.println(F(";<data>        Load paper tape data"));
}

/*
 * Process a single received byte that was received over
 * the serial connection to the Arduino Nano, the byte
 * will be automatically echoed back to the terminal
 * application. 
 * 
 * Each line will be processed by its own function, EOL
 * will be interpreted as CR or NL as long as data has
 * previously been received. Any leading spaces will be
 * ignored.
 */
void process_serial(const byte byte_in) {
  static char input_line[MAX_INPUT_SIZE];
  static unsigned int input_pos = 0;

  Serial.print((char) byte_in);
  switch (byte_in) {
    /* Handle backspace character. Echoing will already have
     * moved the cursor back one position, but we'll need to
     * output a space and then move cursor back  again to
     * actually clear the character that was rubbed out.
     */
    case '\b':
      if (input_pos > 0) {
        input_pos--;
        Serial.print(F(" \b"));
      }
      break;

    /* Handle end-of-line, ignore when one of them comes at the
     * start of a line to gracefully handle differences between
     * client platforms differences.
     */
    case '\n':
    case '\r':
      if (input_pos > 0) {
        input_line[input_pos] = 0;
        select_command(input_line);
        input_pos = 0;
      }
      break;

    /* Ignore any leading zeroes */
    case ' ':
      if (input_pos == 0) break;
      
    /* Add character to current command */
    default:
      if (input_pos < (MAX_INPUT_SIZE - 1)) {
        input_line[input_pos++] = byte_in;
      }
      break;
  }
}
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
void loop() {
  while(Serial.available() > 0) {
    process_serial(Serial.read());
  }
}

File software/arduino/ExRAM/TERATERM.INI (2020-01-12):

[BG]
; Use Eterm look-feel Background extension (on/off)
BGEnable=off

; Use AlphaBlend API (on/off)
BGUseAlphaBlendAPI=on

; Susie plugin path
BGSPIPath=plugin

; Fast window sizing/moving
BGFastSizeMove=on

; Flickerless window moving
BGFlickerlessMove=on

; If HideTitle=on and BGNoFrame=on, use window without frame
; you can resize window with Alt + Shift + LeftDrag
BGNoFrame=on

; wildcard => random select
BGThemeFile=theme\*.INI


[Tera Term]
;	Tera Term version number
Version=2.3

;	Language (English/Japanese/Russian/Korean/UTF-8)
Language=English

; User interface language file that includes message strings.
; Tera Term uses built-in English message when the file or message is not found.
UILanguageFile=lang\Default.lng

; Connecting timeout value(per seconds). No action if the value is zero.
; Connecting socket could be canceled after the value timeout if the value is greater than zero.
; The default value is zero(depends on Windows TCP/IP stack implementation).
ConnectingTimeout=0

; pasting string by clicking mouse right button disabled
DisablePasteMouseRButton=off

; pasting string by clicking mouse middle button disabled
DisablePasteMouseMButton=on

; confirm pasting string by clicking mouse right button
ConfirmPasteMouseRButton=off

; confirm changing clipboard string by clicking mouse right button
ConfirmChangePaste=on
ConfirmChangePasteCR=on
PasteDialogSize=340,254
ConfirmChangePasteStringFile=

; Scroll out the current buffer when the clear screen does.
ScrollWindowClearScreen=on

; Reset scrollback on display activity
AutoScrollOnlyInBottomLine=on

; Starting the selection only by a left button.
SelectOnlyByLButton=on

; New connection by Alt-N Accelerator key
AcceleratorNewConnection=on

; Duplicate session by Alt-D Accelerator key disabled
DisableAcceleratorDuplicateSession=off

; Cygwin connection by Alt-G Accelerator key
AcceleratorCygwinConnection=on

; Send break by Alt-B Accelerator key disabled
DisableAcceleratorSendBreak=off

; New connection Menu disabled
DisableMenuNewConnection=off

; Duplicate session Menu disabled
DisableMenuDuplicateSession=off

; Send break Menu disabled
DisableMenuSendBreak=off

;	ANSI color definition (in the case FullColor=on)
;	* UseTextColor should be off, or the background and foreground color of
;	  VTColor are assigned to color-number 0 and 7 respectively, even if
;	  they are specified in ANSIColor.
;	* ANSIColor is a set of 4 values that are color-number(0--15),
;	  red-value(0--255), green-value(0--255) and blue-value(0--255).
ANSIColor=0,0,0,0, 1,255,0,0, 2,0,255,0, 3,255,255,0, 4,128,128,255, 5,255,0,255, 6,0,255,255, 7,255,255,255, 8,64,64,64, 9,192,0,0, 10,0,192,0, 11,192,192,0, 12,64,64,192, 13,192,0,192, 14,0,192,192, 15,192,192,192
; xterm
; ANSIColor=0,0,0,0, 1,255,0,0, 2,0,255,0, 3,255,255,0, 4,92,92,255, 5,255,0,255, 6,0,255,255, 7,255,255,255, 8,127,127,127, 9,205,0,0, 10,0,205,0, 11,205,205,0, 12,0,0,238, 13,205,0,205, 14,0,205,205, 15,229,229,229
; PuTTY
;ANSIColor=0,0,0,0, 1,255,85,85, 2,85,255,85, 3,255,255,85, 4,85,85,255, 5,255,85,255, 6,85,255,255, 7,255,255,255, 8,85,85,85, 9,187,0,0, 10,0,187,0, 11,187,187,0, 12,0,0,187, 13,187,0,187, 14,0,187,187, 15,187,187,187
; Tera Term Pro 2.3
;ANSIColor=0,0,0,0, 1,255,0,0, 2,0,255,0, 3,255,255,0, 4,0,0,255, 5,255,0,255, 6,0,255,255, 7,255,255,255, 8,128,128,128, 9,128,0,0, 10,0,128,0, 11,128,128,0, 12,0,0,128, 13,128,0,128, 14,0,128,128, 15,192,192,192
; Solarized (http://ethanschoonover.com/solarized)
;ANSIColor=0,7,54,66, 1,203,75,22, 2,88,110,117, 3,101,123,131, 4,131,148,150, 5,108,113,196, 6,147,161,161, 7,253,246,227, 8,0,43,54, 9,220,50,47, 10,133,153,0, 11,181,137,0, 12,38,139,210, 13,211,54,130, 14,42,161,152, 15,238,232,213

;	Enable continued-line copy
EnableContinuedLineCopy=on

; Mouse cursor type (arrow/ibeam/cross/hand)
MouseCursor=IBEAM

; Translucent window (0 - 255: transparency value)
AlphaBlend=255

; Cygwin install path
CygwinDirectory=

; Viewlog Editor path
ViewlogEditor=C:\WINDOWS\notepad.exe

; Locale for Unicode
;Locale=chs
Locale=english

; CodePage for Unicode
CodePage=1252

; Background color of text uses background color of screen (on/off)
UseNormalBGColor=on

;	Port type (serial/tcpip)
Port=serial

;	Window positions
VTPos=-2147483648,-2147483648
TEKPos=-2147483648,-2147483648

;	Terminal size
TerminalSize=100,28
;	Terminal size=window size (on/off)
TermIsWin=on
;	Auto window resizing option (on/off)
AutoWinResize=off

;	Convert a received new-line (CR) char to CR/CRLF/LF/AUTO
CRReceive=CR
;	New-line code to be transmitted (CR/CRLF/LF)
CRSend=CR

;	Terminal ID
TerminalID=VT100

;	Local echo (on/off)
LocalEcho=off

;	Answerback
Answerback=

;	Auto window switching (VT<->TEK; on/off)
AutoWinSwitch=off

;	Kanji code to be received (SJIS/EUC/JIS)
KanjiReceive=UTF-8
;	JIS Katakana code to be received (7/8)
KatakanaReceive=8
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

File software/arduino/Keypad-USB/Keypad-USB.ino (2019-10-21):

#include "Keyboard.h"

#define ROW0 0
#define ROW0_0 0
#define ROW0_1 1
#define ROW0_2 2
#define ROW0_3 3
#define ROW0_4 4
#define ROW0_5 5
#define ROW0_6 6
#define ROW1 1
#define ROW1_7 0 
#define ROW1_8 1
#define ROW1_9 2 
#define ROW1_A 3 
#define ROW1_B 4 
#define ROW1_C 5 
#define ROW1_D 6 
#define ROW2 2
#define ROW2_E 0 
#define ROW2_F 1 
#define ROW2_AD 2 
#define ROW2_DA 3 
#define ROW2_PLUS 4 
#define ROW2_GO 5 
#define ROW2_PC 6
#define ROW3 3 /* virtual row for debouncing */
#define ROW3_RS 0
#define ROW3_ST 1
#define ROW3_SST 2

#define ST_PIN 14
#define RS_PIN 15
#define SST_PIN 18
#define LED_PIN 19
#define NUM_COLS 7
#define NUM_ROWS 3
byte colPins[NUM_COLS] = {2, 3, 4, 5, 6, 7, 8};
byte rowPins[NUM_ROWS] = {9, 10, 16};

#define DEBOUNCE_VALUE 250
#define REPEAT_DELAY 1200
int debounceCount[NUM_ROWS + 1][NUM_COLS];

bool SST_EN = false;

void setup() {
  Serial.begin(115200);

  pinMode(ST_PIN, INPUT_PULLUP);
  pinMode(RS_PIN, INPUT_PULLUP);
  pinMode(SST_PIN, INPUT_PULLUP);
  pinMode(LED_PIN, OUTPUT);

  // set all pins as inputs and activate pullups
  for (byte c = 0; c < NUM_COLS; c++) {
    pinMode(colPins[c], INPUT);
    digitalWrite(colPins[c], HIGH);

    // clear debounce counts
    for (byte r = 0; r < NUM_ROWS; r++) {
      debounceCount[r][c] = 0;
    }
  }

  // set all pins as inputs
  for (byte r = 0; r < NUM_ROWS; r++) {
    pinMode(rowPins[r], INPUT);
  }

  Keyboard.begin();
}

void loop() {
  if (check_debounced(RS_PIN, 3, ROW3_RS, false)) handle_key(ROW3, ROW3_RS);
  if (check_debounced(ST_PIN, 3, ROW3_ST, false)) handle_key(ROW3, ROW3_ST);
  check_sst();

  for (byte row = 0; row < NUM_ROWS; row++) {
    // turn the row on
    pinMode(rowPins[row], OUTPUT);
    digitalWrite(rowPins[row], LOW);

    for (byte col = 0; col < NUM_COLS; col++) {
      if (check_debounced(
          colPins[col], 
          row, 
          col, 
          is_repeatable(row, col)
        )) {
        handle_key(row, col);
      }
    }

    // turn the row back off
    pinMode(rowPins[row], INPUT);
  }
}

/*
 * Reads the specified digital pins, debouncing is performed in order
 * to ignore erroneous key-presses due to the mechanical nature of the
 * switches themselves. d_row/d_col is indexes used to keep track of how
 * long a key has been depressed, a key will normally only register as
 * pressed as long as the reading has been stable for a reasonable amount
 * of time. allow_repeat specifies wether a key held down will register as
 * subsequent presses, or if it should be ignored until key has been
 * released.
 */
bool check_debounced(byte pin, byte d_row, byte d_col, bool allow_repeat) {
  if (digitalRead(pin) == LOW) {
    debounceCount[d_row][d_col]++;

    // has the switch been pressed continually for long enough?
    int count = debounceCount[d_row][d_col];
    if (count == DEBOUNCE_VALUE) {
      return true;
    } else if (count > DEBOUNCE_VALUE) {
      if (count == (DEBOUNCE_VALUE + REPEAT_DELAY)) {
        debounceCount[d_row][d_col] = DEBOUNCE_VALUE + 1;

        if (allow_repeat) return true;
        else return false;
      }
    }
  } else {
    // not pressed, reset debounce count
    debounceCount[d_row][d_col] = 0;
  }
  
  return false;
}

/*
 * Evaluates wether a key should be directly repeatable, a key
 * that is not repeatable will not recognize any further presses
 * until it has been released.
 */
bool is_repeatable(byte row, byte col) {
  if (row == ROW2) {
    switch (col) {
      case ROW2_AD:
      case ROW2_DA:
      case ROW2_GO:
      case ROW2_PC:
        return false;
      default:
        return true;
    }
  }
  return true;
}

/*
 * Monitor SST switch for changes, both state transitions are
 * debounced like the rest of the keys. Handled separately as
 * it is a locking key, something not normally found on a
 * keyboard.
 */
void check_sst() {
  if (SST_EN) {
    if (digitalRead(SST_PIN) == HIGH) {
      debounceCount[ROW3][ROW3_SST]++;
      int count = debounceCount[ROW3][ROW3_SST];
      if (count == DEBOUNCE_VALUE) {
        SST_EN = false;
        handle_sst_off();
      }
    }
  } else {
    if (check_debounced(SST_PIN, 3, 2, false)) {
      debounceCount[ROW3][ROW3_SST] = 0;
      SST_EN = true;
      handle_sst_on();
    }
  }
}

void handle_sst_on() {
  handle_key(ROW3, ROW3_SST);
  Serial.println("SST enabled!");
  digitalWrite(LED_PIN, HIGH);
}

void handle_sst_off() {
  handle_key(ROW3, ROW3_SST);
  Serial.println("SST disabled!");
  digitalWrite(LED_PIN, LOW);
}

/*
 * Translate keypad keys to their equivalents found on a modern
 * keyboard.
 */
void handle_key(byte row, byte col) {
  if (row == ROW0) {
    switch(col) {
      case ROW0_0: Keyboard.write('0'); return;
      case ROW0_1: Keyboard.write('1'); return;
      case ROW0_2: Keyboard.write('2'); return;
      case ROW0_3: Keyboard.write('3'); return;
      case ROW0_4: Keyboard.write('4'); return;
      case ROW0_5: Keyboard.write('5'); return;
      case ROW0_6: Keyboard.write('6'); return;
    }
  }

  if (row == ROW1) {
    switch(col) {
      case ROW1_7: Keyboard.write('7'); return;
      case ROW1_8: Keyboard.write('8'); return;
      case ROW1_9: Keyboard.write('9'); return;
      case ROW1_A: Keyboard.write('A'); return;
      case ROW1_B: Keyboard.write('B'); return;
      case ROW1_C: Keyboard.write('C'); return;
      case ROW1_D: Keyboard.write('D'); return;
    }
  }

  if (row == ROW2) {
    switch(col) {
      case ROW2_E: Keyboard.write('E'); return;
      case ROW2_F: Keyboard.write('F'); return;
      case ROW2_AD: Keyboard.write('/'); return;
      case ROW2_DA: Keyboard.write('*'); return;
      case ROW2_PLUS: Keyboard.write('+'); return;
      case ROW2_GO: Keyboard.write('F'); return;
      case ROW2_PC: Keyboard.write('F'); return;
    }
  }

  if (row == ROW3) {
    switch(col) {
      case ROW3_RS: Keyboard.write(0xB1); return;
      case ROW3_ST: Keyboard.write('S'); return;
      case ROW3_SST: Keyboard.write(0x2A); return;
    }
  }
}

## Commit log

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2019-08-25 Added RS/ST/SST to schematic
    [RC1 Keypad.sch]
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2019-08-27 Added bypass caps and leftover gates
    [RC1 CPU.sch]
2019-08-27 Routed most signals on CPU board
    [RC1 CPU.kicad_pcb, RC1 CPU.sch]
2019-09-04 Added UI signals to CPU board
    [RC1 CPU.kicad_pcb, RC1 CPU.sch, RC1 Keypad.sch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]
2019-09-04 Added serial to UI schematic
    [RC1 UI.kicad_pcb, RC1 UI.sch]
2019-09-04 Added phi1 to UI connector
    [RC1 CPU.kicad_pcb, RC1 CPU.sch, RC1 UI.sch]
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2019-09-06 Keypad MX layout tweaked
    [RC1 Keypad MX-B.Cu.gbl, RC1 Keypad MX-B.Mask.gbs, RC1 Keypad MX-B.Paste.gbp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]
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2019-09-06 Keypad SX layout done
    [RC1 Keypad-B.Cu.gbl, RC1 Keypad-B.Mask.gbs, RC1 Keypad-B.Paste.gbp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]
2019-09-06 Tweaked silkscreens and exported gerbers for CPU/UI
    [RC1 CPU-B.Cu.gbl, RC1 CPU-B.Mask.gbs, RC1 CPU-B.Paste.gbp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]
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2019-09-07 Added ability to override K0/K7
    [RC1 CPU.kicad_pcb, RC1 CPU.sch]
2019-09-07 Added RAM A13/A14 reconnects for external RAM logic
    [RC1 CPU-B.Cu.gbl, RC1 CPU-B.Mask.gbs, RC1 CPU-B.Paste.gbp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]
2019-09-08 Decided to connect remaining RAM address lines for external logic.
    [RC1 CPU-B.Cu.gbl, RC1 CPU-B.Mask.gbs, RC1 CPU-B.Paste.gbp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]
2019-09-13 Keypad MX SST moved to match original keypad layout
    [RC1 Keypad MX-B.Cu.gbl, RC1 Keypad MX-B.Mask.gbs, RC1 Keypad MX-B.Paste.gbp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]
2019-09-13 Keypad SST moved to match original keypad layout
    [RC1 Keypad MX.kicad_pcb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]
2019-09-13 65K Expansion schematic done
    [RC1 65K Expansion.kicad_pcb, RC1 65K Expansion.sch, RC1 CPU.kicad_pcb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]
2019-09-16 65K layout and silkscreen done
    [RC1 65K Expansion-B.Cu.gbl, RC1 65K Expansion-B.Mask.gbs, RC1 65K Expansion-B.Paste.gbp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]
2019-09-16 Added 65K expansion notice to CPU schematic
    [RC1 CPU.sch]
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2019-09-17 8K ExRAM layout and silkscreen done
    [RC1 8K ExRAM-B.Cu.gbl, RC1 8K ExRAM-B.Mask.gbs, RC1 8K ExRAM-B.Paste.gbp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]
2019-09-21 Moved transistors the right way around
    [RC1 CPU.kicad_pcb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]
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2019-09-23 RC1 Sound Interface schematic
    [RC1 Sound Interface.kicad_pcb, RC1 Sound Interface.sch]
2019-09-24 Sound Interface layout done
    [RC1 Sound Interface-B.Cu.gbl, RC1 Sound Interface-B.Mask.gbs, RC1 Sound Interface-B.Paste.gbp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]
2019-09-24 Wrong schematic name
    [RC1 Sound Interface.sch]
2019-09-25 Added Real Time Clock (untested and unverified)
    [RC1 Real Time Clock-B.Cu.gbl, RC1 Real Time Clock-B.Mask.gbs, RC1 Real Time Clock-B.Paste.gbp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]
2019-09-29 Eliminated 74LS145 from CPU module
    [RC1 CPU-B.Cu.gbl, RC1 CPU-B.Mask.gbs, RC1 CPU-B.Paste.gbp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]
2019-09-30 Reworked schematic to remove 74LS145
    [RC1 UI.sch]
2019-09-30 Updated keypad schematic for clarity
    [RC1 Keypad.kicad_pcb, RC1 Keypad.sch]
2019-10-01 Assigned new UI footprints
    [RC1 UI.sch]
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2019-10-08 A7 not usable as digital pin on Nano (appearantly)
    [RC1 8K ExRAM-B.Cu.gbl, RC1 8K ExRAM-B.Mask.gbs, RC1 8K ExRAM-B.Paste.gbp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]
2019-10-08 MX Keypad now matches Commodore Kim-1
    [RC1 Keypad MX-B.Cu.gbl, RC1 Keypad MX-B.Mask.gbs, RC1 Keypad MX-B.Paste.gbp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]
2019-10-16 Fixed paper tape import
    [ExRAM.ino]
2019-10-20 Keypad USB adapter schematic
    [RC1 Keypad to USB.kicad_pcb, RC1 Keypad to USB.sch]
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2019-10-22 Assigned keypad adapter footprints
    [RC1 Keypad to USB.sch]
2019-10-24 Updated J4 markings on 65K board
    [RC1 65K Expansion-B.Cu.gbl, RC1 65K Expansion-B.Mask.gbs, RC1 65K Expansion-B.Paste.gbp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]
2019-11-03 Added diodes to solve display glitch
    [RC1 UI.sch]
2019-11-03 Added diodes to UI board
    [RC1 UI.kicad_pcb, RC1 UI.sch]
2019-11-03 Keypad to USB layout done
    [RC1 Keypad to USB-B.Cu.gbl, RC1 Keypad to USB-B.Mask.gbs, RC1 Keypad to USB-B.Paste.gbp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]
2019-11-07 Gerber export keypad to USB module
    [RC1 Keypad to USB-B.Cu.gbl, RC1 Keypad to USB-B.Mask.gbs, RC1 Keypad to USB-B.Paste.gbp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]
2019-11-08 Changed UI resistors to horizontal
    [RC1 UI-B.Cu.gbl, RC1 UI-B.Mask.gbs, RC1 UI-B.Paste.gbp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]
2019-11-18 Added 65K Expansion README
    [RC1 65K Expansion.kicad_pcb]
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2019-12-20 Project board has clock select pins
    [RC1 Project Board-B.Cu.gbl, RC1 Project Board-B.Mask.gbs, RC1 Project Board-B.Paste.gbp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]
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2019-12-22 LED Cube schematic updated
    [LED Cub.kicad_pcb, LED Cub.sch]
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2019-12-23 LED Cube 4x4 finishing touches
    [LED Cube-B.Cu.gbl, LED Cube-B.Mask.gbs, LED Cube-B.Paste.gbp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]
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2019-12-31 Project boards moved to separate repository
    [LED Cube-B.Cu.gbl, LED Cube-B.Mask.gbs, LED Cube-B.Paste.gbp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]
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2020-01-17 Added N.C. to pin 39
    [RC1 CPU.sch]
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2020-01-21 65K Expansion silkscreen updated
    [RC1 65K Expansion-B.Cu.gbl, RC1 65K Expansion-B.Mask.gbs, RC1 65K Expansion-B.Paste.gbp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]
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2020-01-23 Address calculations fixed
    [RC1 Sound Interface-B.Cu.gbl, RC1 Sound Interface-B.Mask.gbs, RC1 Sound Interface-B.Paste.gbp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]
2020-01-23 Fixed RTC address calculations
    [RC1 Real Time Clock.sch, memory_map.ods]
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2020-01-25 Added buffer to Compact Flash
    [RC1 Compact Flash-B.Cu.gbl, RC1 Compact Flash-B.Mask.gbs, RC1 Compact Flash-B.Paste.gbp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]
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2020-01-27 Updated pad dimensions for Arduino Pro Micro
    [RC1 Keypad to USB-B.Cu.gbl, RC1 Keypad to USB-B.Mask.gbs, RC1 Keypad to USB-B.Paste.gbp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]
2020-01-27 Small board to relocate UI keypad connector
    [RC1 UI Relocate Keypad-B.Cu.gbl, RC1 UI Relocate Keypad-B.Mask.gbs, RC1 UI Relocate Keypad-B.Paste.gbp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]
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2020-02-09 Added game board to memory map
    [memory_map.ods]
2020-10-16 Attempted ExRAM memory backup
    [RC1 8K ExRAM-2020-10-16-02-05-40.sch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]
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2020-10-17 Updated ACIA to make it work with external oscillator
    [RC1 ACIA-2020-10-17-00-32-02.sch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]
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
